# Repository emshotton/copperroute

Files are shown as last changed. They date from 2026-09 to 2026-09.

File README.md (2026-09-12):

# CoppeRoute

An open source PCB autorouter. This started as a rust port of [freerouting](https://github.com/freerouting/freerouting) that got out of hand.

[Live Web Demo](https://copperroute.net)

## Build

Requires a Rust toolchain (see `rust-toolchain.toml`).

```sh
cargo build --release
```

The binary is `target/release/copperroute`.

## Usage

```sh
copperroute route board.dsn -o board.ses
copperroute drc board.dsn --ses board.ses -o report.json
copperroute info board.dsn
copperroute mcp
```

Run `copperroute --help` or `copperroute <command> --help` for the full
option list.

Corridor guidance is enabled by default: related signals are encouraged to share
routing corridors. To disable it for a run:

```sh
COPPERROUTE_CORRIDOR_GUIDANCE=0 copperroute route board.dsn -o board.ses
```

### With a KiCad project

`copperroute` reads a `.kicad_pcb` board directly:

```sh
copperroute route board.kicad_pcb -o board.ses
copperroute drc board.kicad_pcb --ses board.ses -o report.json
```

KiCad 6 and later keep net classes in the `.kicad_pro` project file, not the
board, so a `.kicad_pcb` from those versions carries no clearance or via
sizing of its own. Pass `--kicad-project` alongside it — the flag applies to
a `.kicad_pcb` input the same way it does to a `.dsn` — unless the board is
old enough to embed its own `(net_class ...)` rules:

```sh
copperroute route board.kicad_pcb --kicad-project board.kicad_pro -o board.ses
copperroute drc board.kicad_pcb --kicad-project board.kicad_pro --ses board.ses -o report.json
```

The same flag routes a Specctra export using the project's design rules
instead of the defaults baked into the DSN:

```sh
copperroute route board.dsn --kicad-project board.kicad_pro -o board.ses
copperroute drc board.dsn --kicad-project board.kicad_pro --ses board.ses -o report.json
```

Import `board.ses` back into KiCad with **File → Import → Specctra
Session**. The DRC report uses KiCad's own report schema, so it can be
compared directly with the output of `kicad-cli pcb drc`.

## Layout

The workspace is split into crates, each with its own README:

- `copper-geometry` — exact-arithmetic planar geometry
- `copper-board` — the board model, design rules and spatial indexes
- `copper-dsn` — `.dsn`, `.ses`, `.rules` and KiCad board JSON readers and writers, and a `.kicad_pcb` reader
- `copper-settings` — router configuration from files, environment and CLI
- `copper-router` — fanout, maze routing and the optimizer
- `copper-drc` — the design-rule checker and KiCad DRC report writer
- `copper-core` — loading, saving, the routing job and result manifest
- `copperroute` — the command-line program

## License

GPL-3.0-only. See [LICENSE](LICENSE).

This project is a derivative work of
[freerouting](https://github.com/freerouting/freerouting), which is
distributed under the GNU General Public License version 3. Parts of the
design-rule checker in `copper-drc` are ported from
[KiCad](https://gitlab.com/kicad/code/kicad), which is distributed under
the GNU General Public License version 3 or later. Both are compatible with
distributing the combined work under GPL version 3.

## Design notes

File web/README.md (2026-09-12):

# CopperRoute homepage

A static webpage that accepts a `.kicad_pcb` by dropping it onto the routing
preview window or using the file picker,
runs the existing Rust autorouter in a WebAssembly module worker, displays an
SVG copper preview, and downloads the routed PCB and SVG. No board data is
uploaded. **Route board** removes the existing top-level segments, track arcs and
vias of the selected nets (including locked items) and routes those from scratch.
The initial preview shows the original board; clicking Route shows the unrouted
copy while WASM runs, then updates live with routed copper. The pass number,
remaining connections, and routes completed in the pass update alongside it.
Footprint pads and through holes remain. Original files
on disk are not modified.

The preview appears immediately on file selection, independently of
routing compatibility. Drop `.kicad_pcb` and `.kicad_pro` together to import project
rules, or use the separate optional project picker. Includes a tiny example board
and an immediate Cancel button.

**Board rules** and **Nets to route** are collapsed panels sharing one style.
Each summary names its current state — the project file, embedded classes or
manual rules, and the number of selected nets — so both stay readable while
closed. Board rules holds the zone refill and via-in-pad options.

The example board loads and renders straight away, under a hint inviting a
board to be dropped on the preview. The hint clears on the first click, key
press, scroll or drag, leaving the board visible.

A terminal-styled block below the results carries the commands for cloning and
building the command-line router from GitHub, which the header also links to,
and for serving the routing tools over MCP.
Import notes are no longer surfaced; the status line keeps the pass count and
the review reminder, and DRC findings stay in their own disclosure.

The preview header carries the routing result — remaining connections and the
router DRC count, split into violations that predate the route and new ones.
The line below the preview keeps the pass count and the review reminder.

## Run

From the repository root:

```sh
rustup target add wasm32-unknown-unknown
cargo install wasm-bindgen-cli --version 0.2.127 --locked
cd web
npm ci
npm run build
npm start
```

Open http://127.0.0.1:8080. Easyduino Uno loads automatically with its project rules.
Choose Uno or Nano in the example selector, then click **Route board**.
**Try a small example** loads a minimal two-net board.
Rust and the matching wasm-bindgen CLI are build dependencies; Node is used for
scripts/tests, and Python 3 serves the static files. The generated `pkg/` is
ignored by Git. Serve the `web/` directory over HTTP(S), not `file://`.
Any static host serving `.wasm` as `application/wasm` can host the page. There
are no runtime CDN dependencies, backend services, or cross-origin isolation
requirements; the logo face is the vendored
`fonts/bakbak-one-latin.woff2` (9.5 KiB), served from the same origin under
the SIL Open Font License in `fonts/OFL.txt`, so no request leaves the page. The current release WASM is
approximately 2.9 MiB uncompressed.

## Net selection

**Nets to route** lists every net on the board with its net class. All nets
start selected, so the default route is unchanged. Deselecting a net excludes
it from routing and keeps its existing tracks and vias, which the router treats
as fixed obstacles; only the selected nets are ripped up and routed from
scratch. Unselected nets stay unrouted and are counted in the remaining
connections. **Select all** and **Select none** apply to the nets currently
matching the filter box. Routing is blocked while no net is selected.

The list comes from the board itself, so it appears once the preview loads and
resets with each new board. Selection is passed to the router by net name.
A board the router cannot import still previews, without the net list, and DSN
boards have no net list.

Rerouting a subset of an already routed board is harder than routing the whole
board: the copper of every unselected net is fixed, so the router must fit the
selected nets around it. Expect more remaining connections than a full route of
the same board.

## Via-in-pad rules

**Allow vias in SMD pads** is off by default for KiCad boards and resets when
another board is selected. It supplies the Rust KiCad JSON bridge's explicit
`viaInPadAllowed` permission (absent means false), independently of the project's
width and clearance rules. This is a router option, not an imported KiCad project
property.

Rust stores this permission in each `ViaInfo.attach_smd_allowed`, for the default
via and every net-class via template. Maze search, fanout and forced via insertion
use those rules. Disallowing attachment keeps the new via's copper clear of SMD
pad copper, including off-centre overlaps. `smd_via_relaxation` may reduce via costs
on pure-SMD nets; it cannot override attachment permission for KiCad JSON inputs.

DSN routing continues to use its embedded `(control (via_at_smd on/off))` and
per-via attachment rules, including the legacy pure-SMD search relaxation. The
browser checkbox is disabled for DSN. See the [native permission guide](../docs/fixes/via-in-pad-permissions.md)
for JSON class overrides and format-conversion behavior. Native KiCad imports
preserve existing vias in place; this setting governs newly routed vias.
The browser removes existing vias before rerouting. Disallowing via-in-pad may
require more routing space and can leave connections unrouted.

## Scope and limits

This proves browser routing, rather than complete native KiCad format support.
For KiCad boards, the browser bridge imports KiCad **JSON**, so `kicad.js` translates a supported
subset of the native S-expression format into that existing representation.

- Standard circular, rectangular, oval, and rounded rectangular pads; rotated
  footprints and pads on either side; straight tracks; through vias; up to 32
  copper layers; one outer board outline with internal cutouts, made from lines, arcs, circles, a rectangle,
  or a polygon, including Edge.Cuts inside footprints. Curves are approximated
  within 0.005 mm; legacy center/angle arcs and modern three-point arcs are supported.
  The original outline remains intact in downloads. Cutouts become fixed obstacles
  on every copper layer, with the imported copper-edge clearance.
- Copper layers retain stack order and canonical names independently of KiCad
  numeric IDs; the original layer table (including IDs and aliases) is preserved
  in the PCB download. Signal/mixed copper layers allow routing; power layers
  become non-routing planes in Rust. Unsupported layer types are rejected.
  Export rejects changed layer mappings and traces on non-routing layers.
  The preview legend lists every copper layer, including aliases and plane status.
- Rounded pads preserve corner radii for physical hole-clearance DRC, while routing
  and other DRC checks still use enclosing rectangles. The core
  approximates oval pads with its existing polygon representation.
- Oval slots, plated or not, retain their original geometry in downloads. Routing
  uses the copper pad shape and the smaller drill dimension; slot-specific DRC needs
  KiCad. Connector pads are supported.
- Both legacy numeric net references and KiCad 10 named net references are
  supported. Paste-only pad apertures are excluded from copper routing.
- Copper zones are accepted when **Refill copper zones in KiCad after routing**
  is selected (the visible default). Routing operates on tracks and pads without
  relying on pours. The download preserves zone definitions and removes cached
  `filled_polygon`/`fill_segments` data. Open it in KiCad, press **B** to refill,
  then run DRC. This is not an in-browser zone fill implementation. Keepout areas that
  explicitly allow both tracks and vias are preserved, including pour-only
  keepouts. Areas restricting tracks or vias, and netless copper zones, remain
  rejected. Deselecting the option rejects copper zones but still allows these
  non-routing keepout areas.
- Offset pad copper is translated in its local coordinate system while the hole
  stays at the pad anchor. Custom pad copper is the convex hull of every primitive
  (polygon, line, rectangle, arc and circle) inflated by its stroke, together with
  the circular or rectangular anchor, approximated within 0.005 mm. A pad that is
  not a single convex filled outline warns that its hull can overstate its copper.
  Trapezoid pads are imported as their four corners.
- Copper text is reserved using conservative rectangles. Footprint copper
  rectangles include their stroke and reserve their entire interior. Original
  graphics remain in the download; the reserved text bounds can reduce routability.
- Keepouts restricting tracks or vias, separate outer boards, other footprint
  copper graphics, and net ties are explicitly rejected. Existing routing is
  discarded before import, including locked tracks, arcs and all via types. This excludes many production boards.
- An optional `.kicad_pro` supplies net-class widths, clearances, via diameters,
  drills and class assignments to the existing KiCad JSON loader. The WASM entry
  point also calls the same `fr_drc::apply_kicad_project` API as the native CLI
  for supported board minima, DRC constraints and severities. Project rules take
  precedence over the disabled manual fields. Simple `*`/`?` net-name patterns
  and explicit assignments are supported; composite classes and richer patterns
  are rejected. `.kicad_dru` custom rules and local pad overrides are not applied.
  Legacy embedded `net_class` records supply widths, clearances, via dimensions
  and exact net assignments without a project. An accompanying project takes
  precedence. Manual rules apply when neither source is available. Project files are
  limited to 5 MiB. Browsers cannot read adjacent project files automatically.
- Original non-routing source sections are preserved byte for byte, including
  footprints and board metadata, except cached zone fills when rebuilding zones and the modification notice
  added to bundled example downloads. Top-level tracks and vias are replaced with
  the pipeline output, so their individual UUIDs/properties are not retained.
- KiCad pad and via drills, including net-class via templates, are stored explicitly
  in Rust padstacks in board units. DRC and hole-clearance search geometry use these
  dimensions, and the writer exports them directly. Non-plated holes are marked
  separately and are exempt from annular-ring checks. Pads with different drill
  diameters or plating do not share a padstack. Slotted-hole drill geometry remains
  approximate; legacy inputs without drill metadata retain their fallback behavior.
- `preview.js` displays native outlines, pads, tracks, vias, filled copper zones,
  and reference labels, including modern arc geometry. Previewing does not need
  WASM or a successful routing import, and routing errors retain the preview.
  Some unsupported custom pad shapes are shown by their bounding dimensions.
  It does not render complete silkscreen, component bodies or airwires.
- Routing is single threaded; optimization is disabled. A time limit is
  cooperative within the router, and final DRC/export can take additional time.
  Cancel terminates the worker immediately and discards that attempt. A new
  attempt starts with a fresh WASM instance, including after a panic.
- The UI reports incomplete connections, timeouts, and the Rust DRC count.
  A completed run can still have unrouted connections or violations. Always
  inspect in KiCad and run its DRC with the original project rules.
- Files are capped at 20 MiB. Large accepted boards may still exceed the browser's
  practical memory or runtime limits. Tested in Chromium; other browsers have
  not yet been verified.

## Implementation

`app.js` manages file selection, worker lifecycle, result state, and Blob downloads.
`worker.js` renders native geometry on selection. On Route it imports the board,
applies project classes, loads WASM, routes, then sends the final preview and PCB. All parsing and routing happens in the worker.
`crates/copper-web` resolves normal headless settings, loads the existing JSON format,
invokes `fr_core::RoutingPipeline`, and returns the JSON output plus route metrics.
Routing `std::time::Instant` uses are replaced with `web_time`, a native alias on
native targets and a browser clock on WASM. `ProgressSink::on_board_update` lends
observers the board at existing autorouter checkpoints (250 ms throttle, plus
pass boundaries); its default forwards the unchanged event to existing sinks.
`RoutingPipeline::run_with_progress` allows the browser to use a local callback
without the native sink's `Send` requirement. Snapshots are serialized and rendered
in the worker, then posted while synchronous WASM routing continues. This shows
committed board geometry, not individual maze-search steps. Long searches can
leave a frame unchanged until the next checkpoint. Cancel/replacement terminates
the worker and ignores stale messages. Final output remains the pipeline result.

Relevant format/runtime references:
[KiCad board format](https://dev-docs.kicad.org/en/file-formats/sexpr-pcb/),
[KiCad common S-expressions](https://dev-docs.kicad.org/en/file-formats/sexpr-intro/),
[web-time](https://docs.rs/web-time/1.1.0/web_time/).

Next steps for broader board support: a full native-format importer with exact curved
geometry, in-browser copper zone fills/keepouts and custom rules; geometry oracle tests against
KiCad for real corpus boards; fanout/maze-search visualization; and richer layer/airwire viewing.

## Validation

```sh
# From web/ (build first):
npm test
npx playwright install chromium
npx playwright test

# From repository root:
cargo check --workspace
cargo test -p fr-core --lib
cargo test -p fr-board --lib time_limit
cargo test -p fr-router --lib pipeline::stop
```

Browser tests cover actual drag/drop → WASM route → SVG → PCB/SVG downloads,
read-back of downloaded routing, no uploads/external requests, mobile layout,
invalid input, cancellation and retry. Adapter tests cover placement, source
preservation, drill preservation, rejected geometry, and SVG metadata isolation.

The included board routed both connections with zero Rust DRC violations.
KiCad 10.0.3 independently loaded the browser download and reported zero
unconnected items and no routing errors. Its two warnings were missing local
`Browser` footprint-library definitions for the example's embedded footprints.

Lantern import regression (2026-09-06, before the route-from-scratch change): the user-supplied KiCad 10 PCB and project load
53 nets, 210 copper pads, 413 existing segments, and 128 vias. A one-pass browser
run produced a downloadable result with 10 track-only incomplete connections and
43 Rust DRC findings. KiCad 10.0.3 loaded that download with the original project,
refilled its two ground pours, and reported **zero unconnected items**; remaining
findings were two footprint-library warnings and one dangling-via warning.
The private board is not copied into this repository.

Live preview validation: the v2 Lantern PCB/project streamed six frames during
one routing pass, with remaining connections decreasing from 63 to 11. Browser
tests verify intermediate copper frames arrive before completion and dropping a
replacement onto an existing SVG cancels the old worker. The preview also opens
the file picker with click, Enter, or Space.

## Bundled examples

The picker offers six boards spanning 9 to 225 nets: Hubble jacks, CATs-Eurosynth
Slimline VCA, Easyduino Uno and Nano, Adafruit Feather ICE40, and real-time
chess. Each is fetched only when selected, so opening the page costs one board.
Every board keeps its upstream `LICENSE.txt` and notice beside it, and the
sidebar credit, the routed download's title block and the SVG description all
name that board's own project, author, commit and licence. Boards other than
the Easyduino pair ship without a KiCad project file, so the manual rules apply
to them.

## Bundled Easyduino examples

Uno and Nano are Arduino-compatible designs by Hanqaqa and contributors, from
[Easyduino](https://github.com/Hanqaqa/Easyduino/tree/53b14b66d64f25c55f88971c1c1b51656126bd30).
The unmodified PCB and project pairs are in `examples/easyduino/`, with the
upstream CERN-OHL-P-2.0 license, README, and a provenance notice. These are not
endorsed by Arduino. Keep these notices and the license when redistributing the
examples. Routed example PCBs include a dated modification notice in their title
block; SVG downloads include attribution in a description element.

Both are four-layer boards with one Default net class (no distinct per-net classes):

| Example | Track width | Clearance | Via diameter / drill |
| --- | --- | --- | --- |
| Uno | 0.20 mm | 0.15 mm | 0.50 / 0.30 mm |
| Nano | 0.25 mm | 0.128 mm | 0.50 / 0.30 mm |

The corresponding project is loaded automatically when selecting an example.
A user file selection takes precedence over pending example downloads.

Short one-pass browser runs produced PCB and SVG downloads for both examples.
After refilling zones, KiCad 10 loaded the results and reported 13 unconnected
items for Uno and 19 for Nano, plus 9 and 23 other findings respectively. These
are useful realistic routing demonstrations, not finished production layouts.

Layer regression: the bundled Uno declares F.Cu, In1.Cu, In2.Cu and B.Cu as
signal layers. The Uno example restricts the router to F.Cu and B.Cu via Rust
layer activation settings, while preserving all four layers and their original
types in downloads. Nano and uploaded boards retain their normal routing-layer
behavior. Inner copper now has distinct colors and legend
labels. Browser tests verify that power-plane inner layers receive no traces.

Uno DRC investigation before the drill fix (five passes, outer copper only): all 34 Rust findings were
estimated `drill_out_of_range` results: 32 vias estimated as 0.225 mm and two USB
NPTHs estimated as 0.2925 mm against a 0.30 mm minimum. Actual exported drills
were 0.30 mm and 0.65 mm respectively. The core padstack fallback estimates drill
diameter as 45% of copper diameter when its naming convention does not encode a
drill. At that point, the browser restored via drills only during export, after Rust DRC.
KiCad independently found no undersized holes, but did find one genuine
hole-to-copper clearance error (0.1753 mm versus 0.25 mm), one dangling-via
warning, and three unconnected items. The Rust count is not a manufacturing
sign-off. WASM now includes per-finding `drcDetails` and pre-route
`initialDrcDetails`, with estimate flags and dimensions in mm, for diagnosis.

After the explicit-drill fix, the same Uno run has zero drill-size violations.
Rust reports nine hole-clearance findings: eight already present in its imported
USB footprint approximation and one involving a routed track. KiCad still needs
to validate the complete native geometry, particularly slots and rounded pads.
Regression tests check the unmodified WASM result's via drills, so export-time
repair cannot hide a loss of metadata inside Rust.

## Specctra DSN import

Drop a `.dsn` into the preview window or select it with **Choose a board**.
The native Rust DSN importer supplies embedded net classes, widths, clearances,
via definitions, planes, keepouts, and layer settings to the router. KiCad project
and manual rule controls are disabled for DSN. The preview displays physical board
geometry and updates at routing checkpoints. Loading its preview requires WASM.

**Route board** removes existing traces and vias, including protected routing,
before routing from scratch. Downloads include a routed DSN, an SES session for
import into the original PCB editor, and an SVG. The DSN is reserialized by the
native writer; it is not a byte-preserving copy of the source. Artwork and
source-editor metadata are outside this interchange format. Run the source
editor's DRC after importing the SES. Partially imported DSNs can be previewed
but are rejected for routing.

USB hole-clearance follow-up: see [the investigation](docs/usb-hole-clearance-investigation.md).
The bridge now preserves rounded-pad corner radii and hole-to-copper DRC uses
physical circle, segment, rectangle and rounded-rectangle distances. Routing
retains enclosing rectangles for rounded pads. Result details distinguish
findings already present before routing from new findings; the original project
minimum is not reduced to hide existing footprint violations.

To check a local PCBench download through import, preview, WASM routing and both
PCB/SVG downloads, start the web server and run:

```sh
node web/scripts/check-pcbench.mjs /path/to/PCBench-top-5-new-boards /tmp/pcbench-results
```

The check imports both raw and processed boards and routes each processed board
with its adjacent `raw.kicad_pro` when available. It uses five passes and a
60-second routing budget per board, writes downloaded files and a JSON report,
and verifies unchanged footprints, layer tables and source rules. Passing this
check means the browser produces a usable partial result; the report separately
records remaining connections and DRC findings. Refill pours and run KiCad DRC
before treating an output as complete.

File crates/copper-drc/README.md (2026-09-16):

# copper-drc

The design-rule checker. It answers four questions about a board — *which
rules are violated, which items are unconnected, how many connections
are still incomplete, and how much further the routing fragmented the copper
pours* — and writes the answer as a KiCad DRC report. Use
`copper_drc::prelude::*` to bring in every public type.

The pour question is asked differentially. `PlaneConnectivity` models a refill
on a raster, and that model is an approximation of the CAD tool's own filler,
not a match for it: it erodes without re-inflating, has no thermal reliefs, and
assumes a zone clearance the design file cannot supply. `PlaneFragmentation`
therefore compares two runs of the same model over the same pour outlines —
before and after a session — so the approximations cancel and what is left is
the routing's own effect. An absolute cluster count from this model is not a
claim about the board; a rise in one between two runs is.

The crate sits on `copper-board` (the boards it checks) and on `copper-dsn` (for
`CoordinateTransform` and the shared JSON formatter), and depends on `serde`,
`serde_json` and `thiserror` besides — and on **nothing else**, in particular
not on `copper-settings`. `copper-drc → copper-dsn → copper-board → copper-geometry` is strict
and acyclic. No `tracing`, no GUI, no static mutable state, and **no
clock**: the report's `date` is an injected string.

## API surface

Everything starts from a checker borrowing the board **mutably**:

```rust,ignore
let mut drc = DesignRulesChecker::new(&mut board);
```

`&mut Board` is deliberate. Clearance queries advance the search tree's
entry counter and lower each item's memoised smallest clearance; hiding
either behind interior mutability would hide a side effect a caller can
observe.

| What you want | Call |
|---|---|
| every DRC violation | `get_all_violations() -> Vec<DrcViolation>` |
| the unconnected/dangling list | `get_all_unconnected_items() -> Vec<UnconnectedItems>` |
| the ratsnest | `calculate_all_incompletes()`, then `get_all_airlines() -> Vec<AirLine>` |
| the counters | `max_connections()`, `get_incomplete_count()`, `get_incomplete_count_for_net(n)`, `get_length_violation_count()`, `get_length_violation(n)`, `recalculate_length_violations()` |
| one net's state | `get_net_incompletes(n) -> Option<&NetIncompletes>`, `recalculate_net_incompletes(n)`, `..._with(n, &[ItemId])` |
| the KiCad DRC report | `generate_report(&DrcCoordinates, &DrcReportOptions) -> KiCadDrcReport` |
| that report as JSON | `report_to_json(&DrcCoordinates, &DrcReportOptions) -> Result<String, DrcError>` |
| a hand-built report as JSON | `KiCadDrcReport::to_json()` |
| the clearance block of the board statistics | `BoardStatisticsClearanceViolations::from_violations(&[DrcViolation], board_unit_to_um_factor)` |
| constraints from a KiCad project file | `apply_kicad_project(&project_json, &mut board, &transform)` |
| normalising two DRC documents for comparison | `testkit::normalize_drc_json(&str)` (the `tests/testkit` helper crate) |

`generate_report` and `report_to_json` are `&mut self` for the same reason
`new` takes `&mut Board`: they call `get_all_violations` internally.

### The checks

`get_all_violations` runs `checks::run_all(board, &constraints)`, one
module per check family:

| module | kinds |
|---|---|
| `checks/copper.rs` | `Clearance`, `ShortingItems`, `TracksCrossing` — copper-to-copper on each layer |
| `checks/holes.rs` | `HoleClearance`, `HoleToHole` |
| `checks/edge.rs` | `CopperEdgeClearance` |
| `checks/geometry.rs` | `TrackWidth`, `ViaDiameter`, `AnnularWidth`, `DrillOutOfRange`, `MicroviaDrillOutOfRange` |
| `checks/single.rs` | the per-item pass the geometry checks share |

A `DrcViolation` carries its `kind`, `severity`, the one or two items
involved, the layer, a position, and `expected`/`actual` values;
`kind.kicad_type()` is the string the report writes.

### Constraints

`constraints.rs` resolves the rule set a check runs under. `resolve(board)`
takes the board's own `DrcConstraints` when a KiCad project has been applied
and otherwise derives one from the design (`from_dsn`): per-class clearances
from the clearance matrix, the minimum track width, severities, and the
search radius the copper checks use. `apply_kicad_project` reads a KiCad
`.kicad_pro` document — its board design rules (minimum clearance, track
width, hole clearances, via and microvia sizes), its rule severities and
its net classes' clearances — merges them over the design-derived set, and
stores the result in `board.rules.drc_constraints`, so a board checked
against its project gets the project's numbers rather than the design
file's.

### The two injected parameter blocks

`copper-drc` has no clock and no version constant, so everything the report
needs from outside arrives as a parameter:

```rust,ignore
pub struct DrcReportOptions {
    pub source: String,               // the input file's base name
    pub coordinate_unit: String,      // "mm"
    pub date: String,                 // already formatted
    pub freerouting_version: String,  // without the "Freerouting " prefix, which the report adds
    pub quality_score: Option<f32>,   // None omits the key
}

pub struct DrcCoordinates {
    pub transform: CoordinateTransform,
    pub board_unit: Unit,
}
```

`quality_score` is `Option<f32>` because the score is computed one crate up
(`copper_router::score::BoardStatistics::normalized_score`) as a single-precision
value, and the report widens it to `f64` on the way out; typing the input
`f64` would let a caller hand in a number the scorer cannot produce.

## Determinism

Every walk that could depend on hash order is pinned to item id:

| where | order |
|---|---|
| `unconnectedItems[].items` | ascending item id |
| the seed order of each net's connected-set walk | ascending item id |
| `itemsByNet` | `BTreeMap<i32, …>`, ascending net number |
| the representative item of a connected set | lowest-id `Pin`, else lowest-id `Trace`, else lowest-id item |

**Within** one connected set the walk is descending item id, because
`Board::connected_set` is a `BTreeSet<ItemId>` and the triangulation's
corner-insertion order is the board's item order. Getting this backwards
silently reverses the Delaunay insertion order inside every component and
changes which equal-length airline the ratsnest picks — a wrong-output bug
with no crash.

Two consequences worth knowing before reading a diff:

- **Airline counts are stable; airline endpoints are a function of seed
  order.** `max_connections`, `get_incomplete_count()`, the per-net counts
  and the whole violation list depend only on the board. Which equal-length
  edge the triangulation picks depends on insertion order, so two checkers
  seeded differently can agree on every count and differ on an endpoint.
- **`generate_report` folds dangling-trace entries into `violations`** and
  deduplicates them against each net entry's representative item, so the
  report's `violations` array is longer than `get_all_violations()` and the
  `unconnected_items` array is one entry per net with two or more connected
  sets. The counters and the report measure different quantities of the
  same board; `tests/incompletes.rs` asserts both against one board.

Every `%.4f` in a description is written with a `.` unconditionally, through
`copper_dsn::format::double::java_format_fixed`, so the report does not depend on
the process locale.

## Tests

`cargo test -p copper-drc` runs the unit tests plus the integration suites:

| suite | what it pins |
|---|---|
| `checks.rs` | `get_all_violations`: one check per kind, the dedup and ordering, the report keys and severities |
| `constraints.rs` | constraint resolution from the design and from a KiCad project |
| `unconnected.rs` | `get_all_unconnected_items`: the three phases, their order, the dedup, the representative rule |
| `net_incompletes.rs` | `NetIncompletes`: net-item order, the triangulation, length violations |
| `incompletes.rs` | `calculate_all_incompletes`, the counters, `BoardStatisticsClearanceViolations` |
| `report.rs` | `generate_report` and the four report types, as normalised text |
| `report_json.rs` | `report_to_json`: the key order, the escape and number rules |
| `kicad_oracle.rs` | the checker against KiCad's own DRC output on the committed boards |
| `corpus.rs` | the whole DRC path over every `.dsn` in the fixture corpus (`#[cfg_attr(debug_assertions, ignore)]`) |

`corpus.rs` checks one invariant per board — `generate_report` does not
panic, the JSON parses, and
`violations.len() == hole_clearance + clearance + track_dangling + via_dangling`
with the clearance half checked against an independent
`get_all_violations().len()` — and is the guard on the report layer's three
`panic`s (`item_description`, `detailed_trace_description`,
`item_position`), which replaced silent fallbacks that would have put a
plausible-looking wrong value into a report.

```sh
cargo test -p copper-drc --release --test corpus     # or: --test corpus -- --ignored
```

The committed reference reports in `tests/reference/drc-*` (eight stems
covering every violation type, both auxiliary input paths and both zero and
non-trivial quality scores) are the goldens `crates/copperroute`'s
end-to-end tests compare the `drc` command against;
`COPPERROUTE_REGOLDEN=<label> cargo test -p copperroute --test cli_e2e`
regenerates them.

### What needs the fixture corpus

`tests/corpus` supplies the `.dsn` boards. The synthetic-board tests (the
majority of `net_incompletes.rs`, `incompletes.rs`, `checks.rs` and
`report.rs`) need nothing.

## Known limitations

- **The quality score is computed one crate up.** It needs the board
  statistics' trace lengths, via counts and bend counts, so this crate takes
  it injected and `crates/copperroute/src/commands/drc.rs` computes it.
- **Clearance compensation is never exercised.**
  `is_clearance_compensation_used()` is `false` on every headless path, so
  the compensated arm of the clearance split is unreached by any test or
  fixture.
- **`schematic_parity` is `Vec<serde_json::Value>` and always empty.** If a
  later change fills it, the element type needs its own `Serialize` in
  declaration order, like the other report types.

## Conventions this crate shares with the workspace

**`#![forbid(unsafe_code)]`** sits in the crate root, as it does in every
workspace crate.

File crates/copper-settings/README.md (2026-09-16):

# copper-settings

The router-configuration layer. It answers one question — *given a DSN file,
a `.rules` file, a settings JSON, the environment, the command line and a
board, what settings does the router actually run with?* Use
`copper_settings::prelude::*` to bring in every public type.

The crate sits on `copper-dsn` (which owns the `.dsn` and `.rules` readers) and
on `copper-board` (for the one pass that reads a board), and depends on `serde`,
`serde_json` and `thiserror` besides. No `tracing`: a source that cannot be
applied becomes a `MergeReport::errors` entry. No static mutable state.

## The settings types

`RouterSettings` is the root: `enabled`, `algorithm`, `max_passes`,
`max_items`, `max_threads`, `vias_allowed`, `automatic_neckdown`,
`strict_drc`, `trace_pull_tight_accuracy`, `copper_to_edge_clearance_um`,
`hole_clearance_um`, `zone_clearance_um`, `neck_width_um`,
`job_timeout_string`, `result_json_path`, `ignore_net_classes`,
`save_intermediate_stages`,
`opt_changed_area_ms`, `smd_via_relaxation`, `failure_give_up_threshold`, a
per-layer `layers: Vec<LayerSettings>`, and the nested `fanout:
FanoutSettings`, `optimizer: OptimizerSettings` and `scoring:
ScoringSettings`. `DesignRulesCheckerSettings` and `DebugSettings` live in
`drc_settings.rs`; `BoardUpdateStrategy` and `ItemSelectionStrategy` in
`optimizer_settings.rs`.

**Every field is `Option<T>`, and that is the merge protocol.** `None` means
"this source has no opinion", not "off". The null-coalescing accessors
(`get_max_passes`, `get_layer_active`, `get_bend_cost`, …) apply the defaults
only at the point of use, so a partial source can be merged over a complete
one without erasing anything.

`ExpansionCostFactor { horizontal, vertical }` is the per-layer trace cost
pair the router reads; `RouterSettings::get_trace_costs` builds one per
layer from the layer settings.

## Sources and the merge

Each source implements `SettingsSource` (`get_settings`, `get_source_name`,
`get_priority`, `kind`). `SettingsMerger` sorts its sources by priority,
clones the first non-empty one and applies the rest over it with
`apply_new_values_from`, then validates. The priorities are constants in
`merger::priority`:

| priority | source | where it comes from |
|---|---|---|
| 0 | `DefaultSettings` | built-in defaults, sized by `HostEnvironment` |
| 10 | `JsonFileSettings` | a `copperroute.json` named on the command line (`--settings <file>`) |
| 20 | `DsnFileSettings` | the design's own `(autoroute_settings …)` block |
| 30 | `SesFileSettings` | a session file (contributes nothing today) |
| 40 | `RulesFileSettings` | a `.rules` file |
| 55 | `EnvironmentVariablesSource` | `COPPERROUTE__ROUTER__<A>__<B>=v` |
| 60 | `CliSettings` | `--router.<a>.<b>=v`, or `--set router.<a>.<b>=v` on the native command line |
| 65 | GUI | reserved, unused |
| 70 | `ApiSettings` | the sparse tier an MCP `route_board` call's `settings` argument fills |

`set_field_value(&mut RouterSettings, path, value)` (`field_path.rs`) is the
string-path writer behind the environment and command-line sources; it
knows every field's type (`FieldSpec`/`FieldKind`) and refuses unknown paths
and unparsable values with a `MergeError`.

`copy_fields.rs` is the field-by-field merge (`CopyFields`, implemented per
struct in declaration order) with two rules that decide routing behaviour:
primitive and `String` arrays copy only into an empty target (first writer
wins), and object arrays merge element-wise and are never shrunk. That is
why a `.rules` file's per-layer trace costs do not reach the router through
the merge but its per-layer preferred directions do. `MergeMode::FillAbsent`
is the inverse mode, used once (below).

## `resolve_headless`

The headless run does not perform one merge; it performs two, with a
board-tuning pass between them and a `.rules` re-apply after the second,
and the `.rules` file ends up outranking the environment and the command
line for every field an `(autoroute_settings)` block can carry.
`resolve_headless` (`resolve.rs`) is that sequence as one linear pass:

```text
s = DefaultSettings
s.apply(json_file)                                   // 10
s.apply(dsn)                                         // 20
s.apply(parse(cli_rules))                            // 40   (a rules file named on the command line)
s.apply(env)                                         // 55
s.apply(cli)                                         // 60
s.validate()
s.set_layer_count(board) if it disagrees
s.apply_board_specific_optimizations(board)
s.board_specific_trace_costs_applied = None
s.fill_absent_from(parse(scheduler_rules))           // the second merge's own contribution
s.validate()
s.apply(parse_against(scheduler_rules, board))       // the rules file, re-read against the board's layers
s.apply_board_specific_optimizations(board)
```

Its inputs are `SettingsInputs`:

```rust,ignore
pub struct SettingsInputs<'a> {
    pub json_file:       Option<&'a RouterSettings>,
    pub dsn:             Option<&'a RouterSettings>,
    pub cli_rules:       Option<&'a [u8]>,
    pub scheduler_rules: Option<&'a [u8]>,
    pub env:             Option<&'a RouterSettings>,
    pub cli:             Option<&'a RouterSettings>,
}
```

The two rules slots are **bytes**, not parsed objects, because the same
file is parsed twice against two different layer structures: once with the
layers discovered from the file's own `(layer_rule …)` names, and once
against the board's. A two-layer rules file on a four-layer board puts
`B.Cu` at a different index in each, and handing one parsed object to both
steps produces the wrong settings. Feed it `std::fs::read(path)`.

`resolve_scheduler_rules_path(job_rules, cli_rules, dsn_path)` says which
`.rules` file a run picks up (an explicit one, else the one beside the
design); `_with` injects the file-exists probe for tests.

Three things to keep in view while reading `resolve.rs`:

- **`board_specific_trace_costs_applied` is cleared by hand** at the point
  where the two merges would have handed over to a fresh object, so the
  second `apply_board_specific_optimizations` re-derives the costs.
- **`validate()` is not idempotent.** `max_passes == 0` becomes `i32::MAX` on
  the first call and `9999` on the second, because the second call clamps a
  value above `9999`. The linear pass calls it exactly twice, like the two
  merges it replaces.
- **`resolve_headless` models the CLI-started run.** An MCP `route_board`
  call has a sparse priority-70 payload instead, and `crates/copperroute`
  composes that path itself.

## Defaults, clamps and the host

`DefaultSettings::new(&host)` fills every field; the headline constants are
public (`DEFAULT_VIA_COSTS = 50`, `DEFAULT_PLANE_VIA_COSTS = 5`,
`DEFAULT_START_RIPUP_COSTS = 100`, `DEFAULT_BEND_PENALTY = 10.0`,
`DEFAULT_UNROUTED_NET_PENALTY = 5e6`,
`DEFAULT_CLEARANCE_VIOLATION_PENALTY = 1e6`,
`DEFAULT_COPPER_TO_EDGE_CLEARANCE_UM = 500.0`,
`DEFAULT_HOLE_CLEARANCE_UM = 0.0`). `layers` and the two cost arrays are left
absent — their size depends on the board. `zone_clearance_um` defaults to
`router_settings::DEFAULT_ZONE_CLEARANCE_UM` (500.0): the zone clearance the
copper-pour refill model assumes, since no design file carries one.

Clamps live on the setters: `set_bend_cost` clamps to `[0.0, 9.9]`;
`set_via_costs`, `set_plane_via_costs` and `set_start_ripup_costs` floor at
1; the two trace-cost setters floor at 0.1 and set the applied flag;
`validate` clamps `max_passes` to `0..=9999` (with `0` meaning unlimited),
`max_threads` to the core count, and `trace_pull_tight_accuracy` to at
least 1.

Every machine-dependent number goes through `HostEnvironment`.
`HostEnvironment::detect()` calls `std::thread::available_parallelism()`
once — the only such call in the crate — and `HostEnvironment::with_processors(n)`
is what every test uses, so the processor count never leaks into a test
expectation.

## JSON

`RouterSettings::from_json_str` / `to_json_string_pretty` (`json.rs`) read
and write the settings document. The reader is strict JSON (`NaN` and
`Infinity` are refused) and drops the three transient fields (`max_items`,
`save_intermediate_stages`, `ignore_net_classes`). The writer emits fields
in declaration order through `copper_dsn::format::json::to_gson_string_pretty`,
the layout shared with the DRC report and the result manifest.

## The legacy short flags

`sources/cli.rs` also carries `apply_command_line_arguments`, the table for
the legacy short flags (`-mp`, `-mt`, `-oit`, `-us`, `-is`, `-hr`, `-inc`,
`-drc`). It writes a `LegacyBridge` that nothing on the routing path reads:
those flags are parsed for their effect on argument positions and
diagnostics, and the values that actually reach the router come through the
priority-60 `CliSettings` spelling. The `copperroute` binary no longer accepts
that form; nothing in the workspace calls this table any more.

## Tests

`cargo test -p copper-settings` runs the unit tests plus eleven integration
suites: `copy_fields`, `field_path`, `router_settings`, `board_optimizations`,
`sources`, `env_source`, `cli_source`, `precedence`, `json`, `struct_shape`
and `corpus`.

- **`precedence.rs`** is the load-bearing one. It runs a 64-case matrix
  (`tests/matrix/mod.rs`: 4 DSN shapes × 4 rules shapes × 2 environments × 2
  command lines) through **both** forms of the composition — the literal
  two-merge shape built out of `SettingsMerger`, and the linear
  `resolve_headless` — and asserts they agree field for field.
- **`struct_shape.rs`** pins every struct's field order, because
  `copy_fields` iterates it and `json.rs` emits it.
- **`json.rs`** replays 64 committed settings documents from
  `tests/golden/p4t1-mode1/all.txt` through the reader and writer.
- **`corpus.rs`** runs `DsnFileSettings::new` over every `.dsn` in the
  fixture corpus (~2.7 s in debug, not ignored) and asserts the source's
  layer count matches the header the reader reported. Its `.rules` sibling is
  `#[cfg_attr(debug_assertions, ignore)]`; run it with
  `cargo test -p copper-settings --release --test corpus`.

`tests/data/README.md` describes the committed inputs — the two `.rules`
matrices the precedence suite feeds in and the trimmed
`Issue029-hw48na_reduced.rules`.

### What needs the fixture corpus

`tests/corpus` supplies the DSN and `.rules` fixtures for `corpus.rs`,
`precedence.rs`, `sources.rs`, `json.rs` and `board_optimizations.rs`'s
three `*_golden_*` tests. `copy_fields`, `field_path`, `router_settings`,
`env_source`, `cli_source` and `struct_shape` are pure.

## Conventions this crate shares with the workspace

**`#![forbid(unsafe_code)]`** sits in the crate root, as it does in every
workspace crate.

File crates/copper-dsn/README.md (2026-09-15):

# copper-dsn

The file-format layer: a Specctra `.dsn` reader that builds a
`copper_board::Board`, writers for `.dsn`, `.ses` and `.rules`, a `.ses` and
`.rules` reader, and the KiCad board-JSON reader and writer. Use
`copper_dsn::prelude::*` to bring in every public type.

The crate sits directly on `copper-board` and `copper-geometry`. It builds boards
through `copper-board`'s public insert API and reads them back through
`get_traces`/`get_vias`/`get_connectable_items`/`items_in_board_order`; it
owns no board state of its own. `serde`/`serde_json` are used by the KiCad
module and the JSON formatter only. No `regex`, no `tracing`: reader
diagnostics go onto `ReadScopeParameter::warnings`.

## Entry points

| What you want | Call |
|---|---|
| read a `.dsn` into a board | `read_board(input, &DsnReadOptions) -> BoardReadResult` |
| only the header (layer count, unit, resolution, embedded router settings) | `read_metadata(input) -> BoardReadResult` |
| write a board as `.dsn` | `dsn_writer::write(&mut w, &board, &ct, …)` |
| write a routing session (`.ses`) | `ses_writer::write(&mut w, &board, &ct, …)` |
| apply a session to a board | `ses_reader::read(input, &mut board, …) -> SesImportSummary` |
| write / read a `.rules` file | `rules_writer::write`, `rules_reader::read`, `rules_reader::read_router_settings` |
| a KiCad board JSON | `kicad::read_board`, `kicad::import_session`, `kicad::write` |
| a `.kicad_pcb` file | `kicad::pcb::read_pcb(text, name, &defaults) -> Result<ImportedPcb, PcbError>` |

`BoardReadResult` is `Success { board, metadata, coordinate_transform, warnings }`,
`OutlineMissing` (the same, for a design with no outline), `Partial` (the
file ended inside an unclosed scope; the board built so far is returned with
that fact recorded), `ParseError` or `IoError`. `BoardMetadata` carries the
host CAD name and version, layer count, unit, resolution, snap angle, and the
`(autoroute_settings …)` block as a `DsnRouterSettings` when the file has one.

`CoordinateTransform` — the unit and resolution a file was read in — is
threaded explicitly: `BoardReadResult::Success` carries the one the reader
built, and every writer takes `ct: &CoordinateTransform`, because that is the
only transform that round-trips the file's coordinates unchanged.

## Layout

| Module | What it holds |
|---|---|
| `lexer/` | `DsnScanner`, a table-driven tokeniser (`tables.rs` is generated by `scripts/gen-lexer-tables.py`), and `Token { Open, Close, Kw, Str, Int, Float }` |
| `keyword.rs` | `Keyword` and `ScopeKeyword`, the token vocabulary |
| `parser/` | one module per scope family — `structure`, `library`, `part_library`, `placement`, `network`, `wiring`, `autoroute_settings`, `geometry`, `header`, `dsn_file` — plus `ReadScopeParameter`/`WriteScopeParameter`, the state threaded through a read or a write |
| `dsn_reader.rs`, `dsn_writer.rs`, `ses_reader.rs`, `ses_writer.rs`, `rules_reader.rs`, `rules_writer.rs` | the six file-level entry points |
| `kicad/` | `dto.rs` (the board-JSON document types, field names matching the wire format), `reader.rs`, `writer.rs` |
| `format/` | `IndentFileWriter`, `IdentifierType` (quoting rules for identifiers, with the DSN and SES reserved-word tables), `double` (fixed-width and shortest-round-trip number formatting), `json` (`to_gson_string_pretty`, the JSON layout shared with `copper-settings` and `copper-drc`) |
| `coordinate_transform.rs` | `CoordinateTransform` |

### Read lexemes and write literals are independent

Three things are kept separate and must not be conflated: the scanner's
lexeme → `Keyword` table, `Keyword::name()`, and the literal strings each
writer emits. A scope can be read under one spelling and written under
another (`(rect …)` is written where the keyword is named `rectangle`), so a
change to one table is not a change to the others.

### The KiCad board-JSON reader

`kicad::read_board` builds a board from a KiCad board JSON: units, layer
structure, clearance matrix, outline, net classes, nets, padstacks,
packages, components and pins, conduction areas, traces and vias. Things
worth knowing before touching it:

- **Nets are numbered in first-reference order.** Auto-registered nets get
  their numbers in the order the file first mentions them, so numbering is a
  pure function of the file.
- **A malformed board is refused at the DTO boundary.** A `null` where the
  board needs a name — a layer, a net class, a net, a component reference, a
  pad — or a `null` array element is refused by `KiCadBoardJson::validate`
  with a diagnostic naming the file, the section and the object.
- **A pad's padstack is keyed on its shapes and its drill, not on its
  generated name.** The name encodes neither the layer span nor the drill;
  `unique_padstack_name` keeps display names unique.
- **The clearance matrix it builds is asymmetric on purpose.** The reader
  writes one entry per class pair, and `ClearanceMatrix` readers ask for the
  `(a, b, layer)` triple they mean.

### Reading a `.kicad_pcb` file directly

`kicad::pcb::read_pcb` parses a `.kicad_pcb` file's S-expressions straight into a
`KiCadBoardJson`, returned as `ImportedPcb { board, warnings, embedded_net_classes }`; pass
the result's `board` to `kicad::read_board_json` to get a `copper_board::Board`.
`embedded_net_classes` is the number of `(net_class ...)` entries the file carried, so
callers can tell whether the board defines its own rules or needs a `.kicad_pro`.
`kicad::pcb::default_net_class` gives the net class values the reader falls back on when the
file has no `Default` net class.

- **Some constructs are refused outright.** Curved tracks, footprint zones, locked tracks,
  concave custom pads, zone keepouts that restrict tracks or vias, netless copper zones,
  locked/blind/micro vias, and through vias with no net all fail the read rather than being
  approximated.
- **Net ties are read.** A footprint's `net_tie_pad_groups` are resolved against its pads; the
  tie pads keep their own nets, and the copper joining them carries the group's nets.
- **Copper zones that carry a net are kept, not routed.** They come through with their fill
  cache removed and a warning attached: the reader works in tracks only, and expects KiCad to
  refill zones once the board comes back.
- **A curved board edge is approximated for routing, not discarded.** The outline is
  flattened to straight segments within 0.005 mm and a warning records it; the original
  curved outline is preserved wherever the board is written back out.

## Invariants

- **`normalize_all_traces` runs under a stop check.** Every `.dsn` read ends
  with trace normalisation, which can loop on pathological same-net ladders.
  `DsnReadOptions::normalize_time_limit` (default 60 s) bounds it; when it
  trips the reader records `"Wiring: normalization of traces failed"` as a
  warning and continues. `Duration::ZERO` is a deterministic opt-out. No
  fixture in the corpus comes near the limit, and the corpus test asserts it.
- **UTF-16 code-unit string order.** Several structures are keyed by name in
  UTF-16 code-unit order, which differs from Rust's code-point `str: Ord`
  above the BMP. Where the order is observable in the output, the writers
  use `utf16_cmp` (`parser/part_library.rs`), not the derived `Ord`.
- **Descending item iteration.** Every writer walks the board through
  `Board::get_items`/`items_in_board_order` — newest item first — and the
  output bytes depend on it.
- **The scanner buffer is sized to the input.** `DsnScanner::new` is
  infallible; there is no input-size ceiling.
- **Never edit a reference output by hand.** `tests/reference/<stem>/` is
  produced only by the generator scripts under `scripts/`.

## Tests

`cargo test -p copper-dsn` runs the unit tests plus the integration suites in
`tests/`: the lexer, the number formatters, `IdentifierType`, each scope
family (`structure_scope`, `library_scope`, `placement_scope`,
`network_scope`, `geometry_scopes`, `scopes`, `wiring`, `network`), the DSN
reader, the SES and rules round trips, the KiCad DTOs, reader, writer and
round trip, the JSON formatter (`gson_format`), and the two byte-parity
suites `parity_dsn` and `parity_ses`, which compare the writers' output
against the committed reference files in `tests/reference/` byte for byte.

The corpus test in `tests/dsn_reader.rs` reads every
`.dsn` in the fixture corpus and compares the `BoardReadResult` variant and
the complete warning list against a committed golden. It is `#[ignore]`d in
debug builds (~90 s) and runs unconditionally in release —
`cargo test -p copper-dsn --release`, or `--ignored` in debug. Its always-on
sibling checks that the golden still parses and still names every fixture.

### What needs the fixture corpus

The boards live in `tests/corpus` and the expected outputs in
`tests/reference/`; both travel with the repository. `parity_ses` re-cuts its
references under `COPPERROUTE_REGOLDEN=<label>`.

`tests/kicad_pcb_corpus.rs` runs `read_pcb` against a further set of real `.kicad_pcb`
boards that does not travel with the repository. It skips unless `COPPERROUTE_PCBENCH` names
the corpus root; run it with `COPPERROUTE_PCBENCH=<corpus root> cargo test -p copper-dsn
--test kicad_pcb_corpus -- --nocapture`.

## Conventions this crate shares with the workspace

**`#![forbid(unsafe_code)]`** sits in the crate root, as it does in every
workspace crate.

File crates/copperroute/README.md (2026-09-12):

# `copperroute` — the command-line program

```sh
copperroute route board.dsn -o board.ses
copperroute drc board.dsn --ses board.ses -o report.json
copperroute info board.dsn
copperroute mcp
```

Every subcommand builds a request for `ops` — the crate's one implementation of
load, route, check and summarise — and renders the outcome. The MCP tools are
the same operations behind a JSON-RPC front end.

## Subcommands

| command | what it does |
|---|---|
| `route <input> -o <output>` | load a design, route it, write the session. `<output>` must end in `.ses` (a Specctra session) or `.json` (a KiCad session); anything else is a usage error before the board is read |
| `drc <input> [-o <report>]` | load a design, optionally a session and rules, run the design-rule check, write the KiCad DRC report — to stdout when `-o` is omitted |
| `info <input>` | print the board summary — layers, nets and components by name, the file's metadata, and the board statistics — as JSON on stdout |
| `mcp` | serve the four tools below over newline-delimited JSON-RPC on stdin/stdout |

`<input>` is a Specctra DSN, a KiCad board JSON, or a KiCad `.kicad_pcb`
board; the format is read from the bytes, not the extension.

Global flags, accepted before or after the subcommand: `-v`/`-vv`/`--verbose`
and `--log-level <off|error|warn|info|debug|trace>` set the log level;
`--settings <file>` names a settings JSON.

Corridor guidance is enabled by default. Set `COPPERROUTE_CORRIDOR_GUIDANCE=0`
to disable it; leaving the variable unset or setting it to `1` enables guidance
and its final shove-path safety check.

`route` takes:

| flag | meaning |
|---|---|
| `--rules <file>` | a Specctra `.rules` file. Without it, a `.rules` beside the input is used when one exists |
| `--ses <file>` | a session to import before routing, so the run continues from it |
| `--kicad-project <file>` | a KiCad `.kicad_pro` whose design rules are applied before routing |
| `--max-passes <n>` | how many routing passes to run; `0` means unlimited |
| `--timeout <t>` | wall-clock budget for the whole job, as `hh:mm:ss` or seconds |
| `--result-json <file>` | write the result manifest here |
| `--set router.<section>.<field>=<value>` | override one setting; repeatable. `router.max_items=N` stops the optimizer as well as the router, where `--max-passes` stops only the router |
| `--visualize <dir>` | write one SVG frame per sampled maze step into an absent or empty directory; `--visualize-every N`, `--visualize-max-frames N`, `--visualize-width`, `--visualize-height` bound it (`docs/routing-visualizer.md`) |

`drc` takes `--ses`, `--rules`, `--kicad-project` and `-o <report>`.

## Settings

A run's settings are assembled from, lowest first: the defaults; the
`--settings` file; the design's own `(autoroute_settings …)` block; the rules
file; `--max-passes`, `--timeout` and `--set`; and, for the MCP `route_board`
tool, its `settings` argument. The rules file is read twice — once for its
own layer names, once against the loaded board — which is why `--rules` takes
a path rather than a parsed object.

`--set` names a field by its path under `router.`; `copperroute mcp`'s
`list_settings` tool prints every field with a description and the defaults
in force. The `--settings` file has the same shape:
`{"router": {"scoring": {"via_costs": 77}}}`. No settings file is read
without the flag.

## Exit codes

| code | when |
|---|---|
| **0** | a completed run; `--help`; a `drc` whose report is clean |
| **1** | any failure: an unreadable input, a board that will not load, a session that cannot be written; and a `drc` whose report carries at least one violation |
| **2** | a usage error: an unknown flag, a missing argument, an output path with the wrong extension |

`route` exits 0 on `COMPLETED` and on `TIMED_OUT` with the session written,
because a timed-out job still leaves a usable partial board.

## The MCP server

`copperroute mcp` speaks newline-delimited JSON-RPC 2.0 on stdin/stdout —
**one JSON object per line, no `Content-Length` framing**. Stdout carries the
protocol and nothing else; every log line goes to stderr. It is an
in-process server: there is no listener, no port and no credential.

| what | behaviour |
|---|---|
| `initialize` | `protocolVersion` `"2025-06-18"`; `serverInfo` `{name: "copperroute", version: <crate version>}`; `capabilities` `{"tools": {"listChanged": false}}` — the tool list is fixed at compile time |
| `ping` | answered, `{}` |
| `tools/call` result | a text block **and** `structuredContent`, so a client reads the value instead of re-parsing prose. A tool that runs and fails is an `isError: true` result; a protocol failure is a JSON-RPC `error`; a tool that **panics** answers `-32603` and the server keeps serving |
| a notification | nothing is written back |
| a malformed line | `{"jsonrpc":"2.0","id":null,"error":{…}}` (`-32700`); a blank line is skipped |
| `notifications/progress` and `notifications/cancelled` | both. A `tools/call` runs on its own thread with a `CancelToken`; `_meta.progressToken` turns on interim notifications, and an inbound `notifications/cancelled` flips the token **while** the tool runs |
| shutdown | every path **drains**: the loop stops taking new work and runs until the last tool thread has reported, so no response is truncated. **EOF does not cancel** — a client that closed stdin has no more requests, which is not a client that has stopped reading — so every in-flight `tools/call` finishes and answers, and the exit code is 0. A read failure (1) and a write failure (1) do cancel, because there the answers have nowhere to go |

### The four tools

| tool | arguments | answers |
|---|---|---|
| `route_board` | `dsn_path` \| `dsn_text`, `ses_path?`, `rules_path?`, `output_path?`, `settings?` | `ses_path` when `output_path` was given, else `ses_text` **and** `data` (Base64); plus `stats`, `incompletes`, `unrouted_report`, `drc_violation_count`, `timed_out`, and `job_id`/`size`/`crc32`/`format`/`filename`/`path`. Always a Specctra session, whatever went in |
| `check_drc` | `dsn_path` \| `dsn_text`, `ses_path?`, `rules_path?`, `kicad_project_path?` | the KiCad DRC report — the same document `copperroute drc` writes, coordinates in `mm` |
| `board_info` | `dsn_path` \| `dsn_text` | the board summary — the same document `copperroute info` writes |
| `list_settings` | `{}` | `{"schema": …, "defaults": …}` — the settings schema with a description on every field, and the defaults resolved at call time |

`route_board` is the only one that reports `notifications/progress` and the
only one whose `CancelToken` can be flipped mid-run; the other three are a
load and a walk. **A cancelled route answers a result, not an error**: a
partial board with `timed_out: false`, because only the job deadline sets
that flag. `filename` and `path` name **the input's** directory and the
session's derived name; `ses_path` is the only member that says where a file
was written.

The `settings` argument is applied above every other source and is
*sparse*: naming one field of `scoring` overrides that field and leaves the
rest alone. It is strict JSON — `NaN` and `Infinity` are refused — and a
transient field (`max_items`, `save_intermediate_stages`,
`ignore_net_classes`) is dropped. The server-wide `--settings <file>` given
to `copperroute mcp` sits below it.

## Logging

Everything goes to **stderr**, and there is no log file. The output carries
no timestamp, so it is byte-reproducible. The console default is `INFO`;
`-v` raises it to debug, `-vv` to trace, and `--log-level` sets it outright
(an unrecognised name means `INFO`).

## Layout

| module | what it holds |
|---|---|
| `cli.rs` | the clap surface |
| `lib.rs` | `run` and `ExitCode` |
| `ops/` | `SettingsOverrides` and the settings ladder (`settings.rs`); `BoardSource`, `LoadRequest`, `Loaded` and `load` (`load.rs`); `RouteRequest`, `RouteOutcome` and `route` (`route.rs`); `DrcRequest`, `DrcOutcome` and `drc` (`drc.rs`); `InfoRequest` and `info` (`info.rs`); `OpError` |
| `commands/` | the three CLI adapters: build a request, call `ops`, write files, pick the exit code |
| `mcp/` | the JSON-RPC transport (`stdio.rs`, `server.rs`, `jsonrpc.rs`) and the four tool adapters under `tools/` |
| `logging.rs` | the level ladder and the subscriber |

## Tests

`cargo test -p copperroute` runs the unit tests plus six integration
suites:

* **`ops_load.rs`, `ops_route.rs`, `ops_drc_info.rs`** pin the operations
  directly: settings precedence, rules discovery, session import, the output
  format, the job deadline, the DRC violation count and quality score.
* **`cli_e2e.rs`** runs the binary. Its scenario tests cover the refusals,
  `--set` and `--settings`, the timeouts, and the `drc` exit codes. Its
  reference tests run every stem of `tests/reference/cli-fixtures.txt` and
  compare the session bytes, the exit code and the normalised manifest
  against the committed `tests/reference/cli-<stem>/` outputs; the `ci` stems
  run by default, the `slow` ones under
  `COPPERROUTE_SLOW=1 cargo test --release`.
* **`mcp_stdio.rs`** drives the server through `initialize`, notifications,
  `ping`, `tools/list`, `tools/call`, cancellation, a panicking tool, a
  malformed line and EOF, over in-process pipes and over the spawned binary.
* **`kicad_pcb_input.rs`** runs the binary against a `.kicad_pcb` board:
  `info`'s summary, `route`'s session and its loader warnings on stderr.

The reference and corpus tests read their boards from `tests/corpus`.

```sh
cargo nextest run --workspace
cargo clippy --workspace --all-targets -- -D warnings
cargo fmt --all --check
COPPERROUTE_SLOW=1 cargo test --release            # the slow lanes

# re-cut the CLI goldens from the binary, after a change that is meant to move them
COPPERROUTE_REGOLDEN=<label> cargo test -p copperroute --test cli_e2e
```

The other reference families are re-cut the same way from their own
suites; `tests/reference/README.md` lists them.

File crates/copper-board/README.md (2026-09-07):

# copper-board

The board model: items, design rules, the component/net/padstack library,
the search trees that index items geometrically, and `Board` itself —
everything a PCB design needs *before* routing runs. Use
`copper_board::prelude::*` to bring in every public type.

The crate sits on `copper-geometry` and depends on `num-bigint` and `thiserror`
besides. It must not depend on `tracing`: invariant guards are
`debug_assert!`s, and there is no diagnostic logging.

## Layout

| Module | What it holds |
|---|---|
| `board/` | `Board` and its operations, split by subject: insertion and removal (`mod.rs`), connectivity queries (`connectivity.rs`), clearance queries (`clearance.rs`, `query.rs`), trace normalisation (`normalize.rs`, `trace_normalize.rs`), the changed-area tracker (`changed_area.rs`), the trace-entry bookkeeping shoves use (`shape_trace_entries.rs`), snapshots and the one-level undo journal (`snapshot.rs`), the two clearance overrides applied after a load (`clearance_override.rs`), and `Communication` — the coordinate unit and resolution the board was read in |
| `items/` | the `Item` enum and its nine variants, `ItemHeader`, `ItemCtx`, `PolylineTrace`, the drill items (`Pin`, `Via`), the area items, `AutorouteInfo` (the router's per-item scratch, kept as ids), `ClearanceViolation` |
| `structure/` | `LayerStructure`/`Layer`, `Components`/`Component`, `BoardOutline`, `AngleRestriction`, `FixedState`, `Unit`, `ShapeEntrySide` |
| `rules/` | `BoardRules`, `ClearanceMatrix`, `Nets`/`Net`, `NetClasses`/`NetClass`, `ViaInfos`/`ViaInfo`/`ViaRule`, `DrcConstraints`/`DrcSeverity` |
| `library/` | `BoardLibrary`, `Packages`/`Package`/`PackagePin`, `Padstacks`/`Padstack`, `LogicalParts`/`LogicalPart`/`PartPin`, `Keepout` |
| `searchtree/` | `ShapeSearchTree` (a compensated search tree of item shapes on one clearance class), `SearchTreeManager` (one tree per clearance class in use) |
| `datastructures/` | `ShapeTree` (the minimum-area tree under the search trees), `PlanarDelaunayTriangulation`, `TimeLimit`/`StopCheck` |
| `ids.rs` | the newtype ids: `ItemId`, `RoomId`, `ObstacleRoomId`, `ConnectionId`, `DrillId`, `TreeId`, `NetClassId`, `ViaInfoId`, `ViaRuleId`, `PadstackId`, and `TreeObject { Item, Room }`, the key type a search tree stores |

### `Board`

`Board` owns `items: BTreeMap<ItemId, Item>`, `components`, `rules`,
`library`, `communication`, `bounding_box`, `trees: SearchTreeManager`, the
optional `changed_area`, and the shove-failure scratch
(`shove_failing_obstacle`, `shove_failing_layer`). It is `Send + Sync +
Clone`. There is no undo/redo stack: callers that need to roll back clone
the board (`Board::clone` for a shallow snapshot, `Board::deep_copy` for one
whose memoised caches are reset). The one exception is the single undo level
the optimizer opens around each item it tries to improve
(`begin_undo_journal`, `discard_undo_journal`, `undo_from_snapshot`, over
`board::snapshot::UndoJournal`), which replays the attempt's item changes
back through the **live** search trees so the trees end up in the shape they
would have had without the attempt.

### The `Item` enum

`Item`'s nine variants are `Trace`, `Via`, `Pin`, `ObstacleArea`,
`ConductionArea`, `ViaObstacleArea`, `ComponentObstacleArea`,
`ComponentOutline` and `BoardOutline`. Every variant shares one `ItemHeader`:
id, layer set, clearance class, fixed state, net numbers, component number.
The inherent `impl Item` block in `items/mod.rs` is the common method table,
dispatching on the variant.

### `ItemCtx`

Items hold no pointer back to their board. `ItemCtx` bundles the four
immutable references an item method needs — library, rules, components,
bounding box — and is passed as a parameter; `crate::board::item_ctx!` builds
one from a `&Board`. It deliberately excludes `items` and the search trees,
so an item method holding an `ItemCtx` cannot alias `Board::items` while
`Board` iterates it.

## Invariants

- **Descending item iteration.** `Board::items` is a `BTreeMap`, which
  iterates ascending; every walk whose result depends on visiting order —
  search-tree rebuilds, writers, DRC — goes through
  `Board::items_in_board_order` (`items.values().rev()`), so items are always
  visited newest-first. This is load-bearing: `ShapeTree`'s insertion
  heuristic makes the resulting tree shape a function of insertion order, and
  the tree shape decides the order the router meets obstacles in.
- **`OnceLock`, not `Cell`/`RefCell`, for lazy memo fields** (precalculated
  areas, convex-piece caches, drill-item tile-shape caches). Accessors stay
  `&self` and the type stays `Send + Sync` without a lock, matching how the
  board is used: never mutably aliased while being read.
- **`ShapeTree::insert_tiles` returns `Vec<Option<LeafId>>`.** A shape with no
  bounding tile shape under the tree's angle restriction inserts nothing at
  that index but keeps the list the same length as the shape list. Do not
  `.flatten()` it away: callers zip it against the original shape list.
- **`Polyline::from_lines` errors propagate.** Any operation that re-runs the
  normalising `Polyline` constructor (`translate_by`, `turn_90_degree`,
  `change_placement_side`, trace normalisation, `PolylineTrace::split*`)
  threads the `Result` out rather than emptying the trace on failure. Inside
  `Board::normalize_trace` an `Err` becomes `BoardError::Normalization`.
- **Stop checks on the walks that may not terminate.** Trace splitting and
  normalisation can loop on pathological ladders of same-net traces, so
  `Board::insert_via_checked`, `insert_escape_via_checked` and
  `split_traces_checked` take a `StopCheck` (`&dyn Fn() -> bool`) and answer
  `BoardError::Stopped` when it trips. The unchecked forms pass `|| false`.
- **Clearance matrix values round up to even** on write
  (`ClearanceMatrix::set_value`), and the matrix is not required to be
  symmetric; readers ask for the `(class_a, class_b, layer)` triple they mean.

## Post-load overrides

`Board::apply_copper_to_edge_clearance_override` and
`Board::apply_hole_clearance_override` (`board/clearance_override.rs`) are
applied once after a design is loaded, by `copper_router::pipeline::prepare_board`.
The first appends a `board_edge` clearance class carrying the configured
copper-to-edge clearance (default 500 µm) and re-points the outline at it
unless the outline already carries an explicit class; the second does the same
for hole keepouts when a hole clearance is configured. The order is
load-bearing, because both append a class and `board_edge` gets the lower
index.

## Tests

`cargo test -p copper-board` runs the unit tests plus twenty integration suites,
one per subject: `areas_and_outlines`, `autoroute_info`, `board_builder`,
`board`, `clearance_matrix`, `clearance_override`, `clearance_violations`,
`component`, `conduction`, `consistency`, `drill_items`,
`expansion_room_tree`, `layer_structure`, `min_area_tree`, `polyline_trace`,
`search_tree`, `shape_trace_entries`, `snapshot`, `trace_normalize`.

`consistency.rs` is the property suite: insert/remove round trips,
`deep_copy`, 45- versus 90-degree tile shapes (compared with
`TileShape::contains_tile`, since both angle families compute the same
axis-aligned bounding box), `normalize_traces` idempotence on a fixture that
needs normalising, descending item iteration, and
`Board: Send + Sync + Clone`. `snapshot.rs` pins what `structural_hash`
covers — the whole item graph, walked in board order — and what it
deliberately leaves out (on-demand caches whose state records how often the
board has been measured rather than what it is).

Tests that read a board fixture take it from `tests/data/` or, for the larger
boards, from `tests/corpus`.

## Conventions this crate shares with the workspace

**`#![forbid(unsafe_code)]`** sits in the crate root, as it does in every
workspace crate.

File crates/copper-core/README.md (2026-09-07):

# `copper-core`

The composition layer between `copper-router` and the `copperroute` binary:
loading and saving boards, the routing job, cancellation and progress, the
result manifest, the board summary, and `RoutingPipeline::run`, which ties
routing, the final design-rule check and the unrouted report together.

If you want to **route a board from code**, this is the crate you call.
Everything below it is the router, the design-rule checker, the readers and
the settings ladder.

```rust,ignore
let mut job = RoutingJob::default();
job.set_input(&dsn_path)?;
let loaded = copper_core::load::load_board_if_needed(&mut job)?;     // parse, resolve settings, apply the overrides
let mut board = loaded.board;

let sink = SyncProgressSink::default();
let ctx = Ctx::new(&loaded.settings, &sink);                     // CancelToken::new(), RouterBudget::default()
let result = RoutingPipeline::run(&mut board, &ctx)?;

copper_core::save::save_as_specctra_session_ses(&board, &loaded.transform, &design_name, &mut out)?;
```

## What this crate is not

**It is not a new home for anything `copper-router` owns.** `copper_core::{BoardStatistics,
RoutingEvent, ProgressSink, PassRecord, TaskState, RouterStop, RouterBudget,
run_pipeline, prepare_board, build_unrouted_report, …}` are `pub use
copper_router::…`, and `RoutingPipeline::run` **wraps** `run_pipeline`. This
crate is partly a façade: a reader looking for where a routing decision is
made will find it in `copper-router`, even though the call came through here.

## Layout

| Module | What it holds |
|---|---|
| `ctx.rs` | `Ctx { settings, cancel, progress, budget }` and `RoutingResult { stats, unrouted_report, drc_violations, timed_out, stop_reason, pipeline }` |
| `pipeline.rs` | `RoutingPipeline::run(&mut Board, &Ctx) -> Result<RoutingResult, Error>` |
| `cancel.rs` | `CancelToken`, `Deadline` and `JobStopReason { Deadline, Cancelled }` |
| `progress.rs` | `SyncProgressSink`, a `ProgressSink` that can be read from another thread, and its `SyncProgressSinkView` |
| `job.rs`, `file_details.rs` | `RoutingJob`, `BoardFileDetails`, `FileFormat`, `RoutingJobState`, `RoutingStage`, `JobId`/`SessionId` (`Uuid128`) |
| `load.rs` | `load_from_specctra_dsn`, `load_from_kicad_json`, `parse_board_result`, `apply_router_settings_for_loaded_board`, `load_board_if_needed` |
| `save.rs` | `save_as_specctra_session_ses`, `calculate_crc32_for_board` |
| `manifest.rs` | `RoutingResultManifest`, the `--result-json` document |
| `summary.rs` | `BoardSummary` and `summarise`, what `copperroute info` and the `board_info` tool print |
| `stats_json.rs`, `stats_from_bytes.rs` | the board statistics as JSON, and the counters that are read from the file bytes rather than the board |
| `timespan.rs` | `parse_timespan_seconds` and the job-timeout ladder |

## `CancelToken` and `RouterStop`

A `CancelToken` is the cross-thread handle; it maps onto the router's
`RouterStop`, which is a **three**-state flag, and the mapping keeps the
distinction:

| `CancelToken` | `RouterStop` | what it means |
|---|---|---|
| `cancel()` | `ALL` | the router **and** the optimizer stop |
| `cancel_auto_router()` | `AUTO_ROUTER_ONLY` | the router stops between connections; the optimizer still runs |

`max_items` reaches the first and therefore *silently disables the
optimizer*; `max_passes` reaches the second and does not. A single boolean
collapsing the two would change behaviour without changing a test, which is
why the token exposes both. The help text for `--set` in
`crates/copperroute/src/cli.rs` says so, because the program has no
`--max-items` flag of its own — the surface for it is the generic override,
`--set router.max_items=N`.

**An uncancelled token is a no-op.** `CancelToken::default().as_router_stop()`
is indistinguishable from `RouterStop::new()`, and `apply_to` on it writes
nothing.

The router polls the token at four sites: the pass-loop heads in
`pipeline::{batch_loop, fanout, optimizer}`, and the item loop in
`pipeline::pass_runner`. The fourth exists because one pass of a large board
can take minutes in release, and a cancellation that is observed only
between passes is not a cancellation an operator can use.

## The job deadline

`Deadline` has one instant, `stop_at`: when routing must stop. The ladder
that builds it from `--timeout` / `router.job_timeout` is: parse; clamp
**from above only** at `MAX_TIMEOUT_SECONDS` (24 h); `started_at + timeout`.
There is **no lower clamp**, so a negative timeout is a deadline in the past.
`CancelToken::with_deadline` carries it into the run, and the router polls it
at the same sites it polls cancellation.

`RoutingPipeline::run` records **why** a run stopped as
`RoutingResult::stop_reason`: `Some(JobStopReason::Deadline)` when the job
deadline expired, `Some(JobStopReason::Cancelled)` when the token was
cancelled, `None` for a run that finished on its own.
`RoutingResult::timed_out` is `stop_reason == Some(Deadline)`. The CLI and the
MCP tools map that reason straight onto the job state (`TIMED_OUT`,
`CANCELLED`, `COMPLETED`), so a cooperatively stopped job reports
`TIMED_OUT` as soon as it returns its partial board.

The job deadline is not the same flag as a stage's budget. The tightener's
time limit, the fanout per-pin clock and the optimizer's own deadline are
`RouterBudget` knobs that end their stage and surface as
`PipelineResult::timed_out`; they never set the job's stop reason.
`crates/copperroute/tests/cli_e2e.rs::final_state_distinguishes_stage_limits_from_job_deadlines`
is the test that keeps the two apart.

## `Ctx` has no rng seed and no `max_threads`

Spec §10 mentions both. This crate has neither: there is no randomness on any
routing path that is not derived from the settings, and `max_threads` is
read by nothing — the only threads in the workspace are the MCP transport's
two, and they carry no routing policy. `Ctx` also holds no board and no
job; the board is `RoutingPipeline::run`'s `&mut Board` parameter, owned by
whichever caller loaded it.

## `RoutingPipeline::run` composes; it does not decide

Three additions over `run_pipeline`, and **no fourth**: the `CancelToken`
adaptation, the final board's DRC violations, and the unrouted report.
`RoutingResult::stats` **is** `PipelineResult::final_statistics`, never a
second `BoardStatistics::compute` — the statistics constructor runs the
design-rule checker, and `copper-drc`'s memoisation makes the call count
observable. `RoutingResult::unrouted_report` is the diagnostic text; the
**count** comes from `stats.connections.incomplete_count`.

## The load sequence

Loading a board is `load_from_specctra_dsn` (or `load_from_kicad_json`) →
`apply_parsed_board_result` → **`apply_router_settings_for_loaded_board`** →
`apply_immediate_post_load_processing`, with `load_board_if_needed` in front
of them. The third step has four parts that split two and two:

| step | who owns it |
|---|---|
| if the board's layer count differs from the settings', write the board's into the settings | **settings** — `apply_router_settings_for_loaded_board`, and `copper_settings::resolve_headless` |
| `apply_board_specific_optimizations(board)` | **settings** — the same two |
| the copper-to-edge clearance override | **board** — `copper_router::pipeline::prepare_board` → `Board::apply_copper_to_edge_clearance_override` |
| the hole clearance override | **board** — the same, → `apply_hole_clearance_override` |

The two settings steps have two callers and one implementation each.
`resolve_headless` runs them because it models the whole settings ladder;
`load.rs` runs them because it is the loader. They are **not** nested — the
loader has no `SettingsInputs` ladder to hand `resolve_headless`. The order
is settled at the one place the two meet, the CLI: parse the board, call
`resolve_headless` **once** against the parsed board, then run the loader's
two board passes with the resolved settings.
`tests/load.rs::the_settings_pass_is_the_same_two_steps_resolve_headless_runs`
asserts the two agree, so the duplication cannot drift.

The two board steps run **once** per load, after the design is read.

## Versions

```
SERVER_VERSION = env!("CARGO_PKG_VERSION")
```

The crate's own version is what the manifest's `app_version`, the DRC
report's `router_version` and the MCP `serverInfo` carry. The SES/DSN
`(host_cad …)`/`(host_version …)` are echoed back **from the input file** and
never carry it. `tests/testkit`'s manifest normaliser drops `app_version`, so
a committed manifest golden does not move when the crate version does.

## The result manifest (`manifest.rs`)

`RoutingResultManifest` is the `--result-json <path>` document: thirteen
keys in declaration order, written through the same
`to_gson_string_pretty` the settings and the statistics go through, with no
trailing newline. **The Rust field order is the JSON key order** — serde's
derived `Serialize` streams a struct in declaration order — so reordering the
struct changes the file.

Three things about it are worth knowing before reading the code.

**`board_statistics` is serialised through `GsonBoardStatistics`**, not
through `serde_json::Value`: `Value`'s map alphabetises keys and its `f32`
widens to `f64`, and both would change the bytes. `normalized_score:
572.4359` in the committed `p8t2` transcript is what proves the single-
precision path end to end.

**The SHA-256 is hand-written.** `sha256_hex` needs one and the workspace
adds no dependency for it; the FIPS 180-4 core is sixty lines in
`manifest.rs`, pinned against the three NIST example vectors, the empty
message and the 55/56/63/64/65-byte padding boundaries.

**`resolve_git_sha` reads the environment**, `COPPERROUTE_GIT_SHA` first and
`freerouting.git.sha` second, and trims the value with its own whitespace
set rather than `str::trim`; `whitespace_sets_are_the_measured_ones` pins
that set.

## The job model (`job.rs`, `file_details.rs`)

`RoutingJob` carries the file details of the input, output, rules and DRC
files (`BoardFileDetails`: path, name, format, derived output name), the
job's `RouterSettings` and `DesignRulesCheckerSettings`, its state and
stage, and resource usage. `FileFormat` is detected from the file bytes and
has nine values (`Dsn`, `Frb`, `Ses`, `Rules`, `Scr`, `DrcJson`,
`KicadDesignJson`, `KicadSessionJson`, `Unknown`). `RoutingJobState::Invalid`
is a terminal state — an input that is neither a design nor a KiCad board
fails the job rather than leaving it queued.

`Session` collapses to `SessionId` (a 128-bit newtype) plus
`validate_session_host`. There is no random id: `RoutingJob::new` uses
`Uuid128::NIL` and `RoutingJob::with_id` takes one from a caller that has one
(the MCP server mints them). Nothing on a decision path reads an id.

**The path helpers in `job.rs` are POSIX-only**: they hardcode `/` as the
separator and `starts_with('/')` as the definition of an absolute path, so
every derived output name goes through the same rules on every host.
Windows support is a rewrite of that module, not an unpinning of one
constant.

## Tests

`cargo test -p copper-core` runs the unit tests plus eleven integration suites:
`cancel` (the three-state mapping, the no-op property, a real cross-thread
cancel), `ctx`, `job` (154 file-detail rows from `tests/data/p8t1-job-model.txt`,
plus 36 named edge cases), `load`, `manifest`, `overrides` (the 54 stage
blocks of `tests/data/p8t3-clearance-overrides.txt`, search-tree leaf count
and order digest included), `pipeline` (the whole pipeline with a recording
sink, comparing session bytes), `register`, `stats`, `summary` and
`timespan` (the 30 rows of `tests/data/p8t0-timespans.txt`).

The suites that read a board fixture take it from `tests/corpus`.

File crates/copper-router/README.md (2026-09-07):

# copper-router

The autorouter. It routes, fans out and optimises a **whole board**:
`pipeline::run_pipeline` sequences the fanout pre-pass, the routing pass loop
and the optimizer, and everything under it — the maze search, its expansion
rooms, the shove and pull-tight families, the via optimizer — is this crate's
too. Use `copper_router::prelude::*` to bring in every public type.

The crate depends on `copper-board`, `copper-geometry`, `copper-settings`, `copper-drc` (for
the unrouted report and the score's clearance block) and `thiserror`, and on
nothing else. `copper-dsn` and `parity` are dev-dependencies, for fixtures.

## Entry points

```rust,ignore
pub fn run_pipeline(
    board: &mut Board,
    settings: &RouterSettings,
    stop: &RouterStop,
    budget: RouterBudget,
    progress: &mut dyn ProgressSink,
) -> Result<PipelineResult, RouterError>;
```

`prepare_board(&mut Board, &RouterSettings)` applies the two post-load
clearance overrides and is called once per loaded board, before
`run_pipeline`. `PipelineResult` carries the router and optimizer
`TaskState`s, the pass counts, the fanout summary, one `PassRecord` per
routing pass (`pass`, `score`, `incomplete_count`, `clearance_violations`,
`via_count`, `trace_count`), the final `BoardStatistics`, and whether any
stage's budget expired. `build_unrouted_report(&mut Board)` writes the
diagnostic text naming every incomplete connection.

Below the pipeline, `route_connection` routes one connection through an
`AutorouteEngine` — maze search, locate, delete the ripped connections,
insert — and `route_connection_full` adds the necked retry, the strict-DRC
rollback and the failure-log write around it.

## Layout

| Module | What it holds |
|---|---|
| `pipeline/run.rs` | `run_pipeline`, `PipelineResult`, `normalize_router_algorithm` |
| `pipeline/batch_loop.rs` | `AutorouteBatchLoop::run` — how many passes run, which board survives them, when to give up; `BatchLoopResult`, `BatchLoopExit`, the stagnation windows |
| `pipeline/pass_runner.rs`, `batch_autorouter.rs` | one routing pass: the work list (`BatchAutorouter::autoroute_items`, sorted ascending by airline length), the per-item loop, progress events |
| `pipeline/fanout.rs` | `BatchFanout::fanout_board` and `fanout_pass`, the SMD-pin escape pre-pass, with `FanoutComponent`/`FanoutPin` ordering and the `FanoutRunSummary` |
| `pipeline/optimizer.rs` | `BatchOptimizer::run_batch_loop`, `opt_route_pass`, `opt_route_item` — re-route one item at a time and keep the result only if the score improves, rolling back through `copper-board`'s undo journal otherwise |
| `pipeline/board_history.rs` | `BoardHistory`, the pass loop's best-board memory (up to 30 clones, ranked by score) |
| `pipeline/stop.rs` | `RouterStop` (the three-state stop flag), `RouterBudget` (the wall-clock knobs), `PassRecord`, `ProgressThrottler`, `DeterministicWorkBudget` |
| `pipeline/airline.rs`, `counters.rs`, `failure_log.rs`, `item_route_result.rs`, `unrouted_report.rs`, `board_prep.rs` | airline distance, `RouterCounters`, `RoutingFailureLog`, `ItemRouteResult`, the unrouted report, `prepare_board` |
| `autoroute/maze/` | `AutorouteEngine` (the room lifecycle), `MazeSearchEngine` (the search frame, `expand.rs` its body), `MazeExpansionEngine` (drill and layer expansion), `MazeRipupResolver` (the ripup decision and cost), `MazeTraceShover` (the check-only shove probe), `AutorouteControl`, `DestinationDistance`, `MazeListElement`, `MazeQueue` |
| `autoroute/expansion/` | the expansion rooms (`FreeSpaceExpansionRoom`, `IncompleteFreeSpaceExpansionRoom`, `CompleteFreeSpaceExpansionRoom`, `ObstacleExpansionRoom`), doors (`ExpansionDoor`, `TargetItemExpansionDoor`), the three neighbour sorters (any-angle, 45°, orthogonal), and `ExpansionRoomStore`, the arenas they live in |
| `autoroute/drill/` | `DrillPage`, `DrillPageArray`, `ExpansionDrill` — the pages that manufacture the search's layer changes |
| `autoroute/path/` | `FoundConnectionLocator` (three angle regimes) turns a `MazeResult` into corner lists; `FoundConnectionInserter` inserts them; `Connection` |
| `autoroute/tree_ext.rs` | `AutorouteSearchTreeExt` — `complete_shape` and `divide_large_room`, the two search-tree operations only the router needs |
| `board_ext/` | `RoutingBoardExt`, the extension trait over `copper_board::Board` for everything that needs an engine or a shove: `init_autoroute`/`finish_autoroute`, `insert_forced_trace_polyline`/`_segment`, `opt_changed_area`, `remove_items_and_pull_tight`, `fanout`; and the classes it drives — `TraceShover`, `DrillItemMover`, `ForcedPadRouter`, `ForcedViaInserter`, `ViaOptimizer`, and the pull-tight family in `tightener/` (base, 90°, 45°, any-angle) |
| `score/` | `BoardStatistics` and its blocks, `normalized_score`, the JSON DTOs |
| `visualization.rs` | opt-in SVG capture of the maze search: `RoutingVisualizationOptions`, `start_routing_visualization`, the `RoutingVisualizationGuard` whose `finish()` returns a `RoutingVisualizationSummary`. When no recorder is active the capture hooks the search calls cost one relaxed atomic load; `docs/routing-visualizer.md` describes the frames and the viewer |
| `arena.rs` | `Arena<T>` and its index newtypes |
| `error.rs` | `RouterError` |

## The stop machine and the budget

`RouterStop` is a **three**-state flag, not a boolean, and the distinction
is load-bearing:

| write | state | effect |
|---|---|---|
| `request_stop()` | `ALL` | the router **and** the optimizer stop |
| `request_stop_auto_router()` | `NONE -> AUTO_ROUTER_ONLY` | the router stops between connections; **the optimizer still runs** |

`is_stop_requested()` is `== ALL` and gates the optimizer stage;
`is_stop_auto_router_requested()` is `!= NONE` and is what the pass loop and
the item loop read. Every ordinary exit from the pass loop — the pass cap,
"cannot improve", both stagnation windows — raises `AUTO_ROUTER_ONLY`, so
the optimizer runs after a normal routing run and is skipped only after a
full cancel. Nothing resets the flag between stages; `run_pipeline` hands
both stages the same `RouterStop`.

`RouterBudget` holds the wall-clock knobs: `opt_changed_area_ms` (the
tightener's time limit, default 1000), `fanout_ms_per_pin`,
`board_update_throttle_ms` and `progress_throttle_ms`.
`RouterBudget::disabled()` turns every one of them off, which is what every
reproducibility test passes — a run with a live budget is a function of
machine speed. `RouterStop::poll_deadline` has exactly one production call
site, the job-level check at the head of the pass loop; the per-stage clocks
(fanout, optimizer) write only their own `is_timed_out` and never the stop
flag.

## House rules

* **Single-threaded.** No `rayon`, no `std::thread`. `Board` stays
  `Send + Sync`, but nothing here spawns, and `max_threads` is read by
  nothing. A threaded maze would be non-deterministic and would dissolve
  every reproducibility test in the tree.
* **No new workspace dependencies.** Not `rand` (see `SplitMix64` in
  `copper-geometry`), not `slotmap` (see `Arena` below), not `rayon`.
* **Deterministic containers.** The maze queue is a sorted set (`BTreeSet`),
  never a `BinaryHeap`: the search pops the least element and re-inserts
  mutated elements. Every sorted container is a `BTreeSet`, which is sound
  because every comparator is a total order: float keys compare with
  `total_cmp`, giving `NaN` a fixed position rather than letting it sort
  arbitrarily. That covers the neighbour sorters' `SortedRoomNeighbour`,
  `MazeListElement`, `BatchFanout`'s pin order and the queue — each orders and
  dedups identically on every run. `MazeQueue::push` is guarded: an element
  outside the fanout escape window is refused, and the boolean is discarded at
  the one site that discards it, so `init` can succeed with an empty queue.
* **No GUI, no logging, no observers, no clock, and no static mutable state,
  with one recorded exception:** `copper_geometry::Line`'s identity token, which
  `Board::change_trace` reads through `Line::is_same_object` to decide how
  many search-tree leaves to reuse. The contract: a new token wherever a new
  `Line` is built, `Copy` — the same token — wherever the same line is passed
  on. Nothing reads the token's *value*, so no output, ordering, hash or
  serialised form can observe it.
* **`#![forbid(unsafe_code)]`**, as in every workspace crate.

## Cancellation: six sites, and why a seventh is a bug

`AutorouteEngine::is_stop_requested` — the per-connection time limit or the
caller's stop flag — is consulted at exactly six places: four inside
`MazeSearchEngine::init` (the destination-set walk and three seeding loops),
the head of the pop loop before the queue is touched, and
`DrillPage::get_drills`' convex split. Each has a test. Adding a seventh
makes a run stop earlier than the loop shape implies, which changes the
board: the divergence is not "we stopped sooner", it is "we routed something
else". Two consequences:

* **The inserter is handed `&|| false`.** Nothing below the maze search
  checks cancellation; threading the caller's check into
  `FoundConnectionInserter` would abort inserts that should complete, after
  the ripped items have already been removed — a worse board than either
  outcome.
* **`Board::split_traces_checked` consults the check once**, inside the entry
  walk that may not terminate, not once per picked trace.

The per-connection wall clock belongs to `route_connection`, which builds a
`TimeLimit` from the settings; `AutorouteBatchLoop` owns everything outside
that.

## The recovery boundaries

Panics are the error channel for geometry that has no meaningful degraded
value, and the router catches them at exactly these boundaries:

| # | site | mechanism | what it answers |
|---|---|---|---|
| 1 | `AutorouteEngine::complete_expansion_room` | `Result`, and **`Err` means an empty collection** — every caller uses `unwrap_or_default()`, never `?` | no rooms |
| 2 | maze construction in `autoroute_connection` | `catch_unwind` | `FAILED` |
| 3 | `find_connection` | `catch_unwind`, nested inside 2 because the search borrows the engine for its whole life | `FAILED` |
| 4 | the locator | `catch_unwind` | `FAILED` |
| 5 | the whole of `route_connection` | `catch_unwind` | a bare `FAILED` |
| 6 | `insert_forced_trace_polyline`'s normalise and split | the `Result` channel: the `Err` is dropped and the trace stays as it was | a silent skip |
| 7 | `AutoroutePassRunner::run_single_thread` | `catch_unwind` around the whole pass body, degrading to `Ok(false)` — **not** per item: a failure inside the item loop ends the pass rather than skipping one item | the pass ends |
| 8 | `AutorouteBatchLoop::run` when no layer is both active and a signal layer | the **only one that propagates**: fires `TaskState::Cancelled`, then returns `RouterError::NoRoutableLayer` | an error |

The boundaries catch panics, not stack overflows. Everything *below* the
maze search deliberately panics rather than degrading, because the necked
retry in `route_connection_full` is the real recovery. `panic = "abort"`
must stay unset in the release profile: `AutorouteEngine::drill_page_drills`
restores the drill-page grid through `catch_unwind`/`resume_unwind`.

## `Arena<T>`, and why not `slotmap`

The autoroute object graph is cyclic: a room holds its doors, a door holds
both of its rooms, a drill holds one room per layer. `Rc<RefCell<…>>` would
make the engine's borrow of a `Send + Sync` `Board` unrepresentable, so every
room, door, drill and page lives in an `Arena<T>` — a `Vec<Option<T>>`
addressed by a `u32` index — and the newtypes `RoomId`, `ObstacleRoomId`,
`IncompleteRoomId`, `DoorId`, `TargetDoorId`, `DrillId`, `PageId` and
`ConnectionId` are those indices.

It has **no generation counter**, deliberately. `Arena::remove` leaves a
permanent hole and **indices are never reused**: `insert` always appends, so
an index stays valid, or permanently empty, for the arena's whole life. A
long run's arena grows to the total number of objects ever created rather
than the live count. `Arena::clear` drops the indices as well and is only
sound between connections, when no id from the old arena survives.
`DrillPage::invalidate` frees its own drill ids, because pages are
invalidated once per changed item and leaving the slots would grow the arena
for the whole run.

## The maze search in outline

1. `AutorouteControl::from_settings` copies the numbers the search reads —
   trace half widths and costs per layer, via costs and masks, ripup costs,
   the fanout escape window — so the search never touches `RouterSettings`.
2. `MazeSearchEngine::init` seeds the queue with the start items' expansion
   rooms and target doors. A seed refused by the escape window is dropped.
3. The pop loop takes the cheapest `MazeListElement` — ordered by sorting
   value, then expansion value, then door id — and expands it: through its
   room's doors (`expand.rs`), to a drill page or a drill (`MazeExpansionEngine`),
   or through a rippable obstacle (`MazeRipupResolver`, which prices the
   ripup from the obstacle's half width, its detour and the pass number, with
   a pseudo-random scaling from pass 4 on). The A\* cost is the expansion
   value plus a bend penalty (charged above `sin² > 0.01`, about 5.7°) plus
   `DestinationDistance`'s lower bound.
4. `FoundConnectionLocator` walks the backtrack chain into corner lists per
   layer, in the board's angle regime.
5. `FoundConnectionInserter` derives the vias from the layer changes, inserts
   each corner run through `insert_forced_trace_polyline` (which shoves,
   springs over obstacles and pull-tightens), connects the ends, and
   normalises.

`ExpansionDoor`'s id is a hash of its two rooms' ids, not an identity, and it
is the third sort key of the queue; the same is true of `ObstacleExpansionRoom`
and `IncompleteFreeSpaceExpansionRoom`. Only `CompleteFreeSpaceExpansionRoom`
carries a true counter id. Complete-room ids **skip** — the counter ticks once
per neighbour calculation, including ones that build no room — and the arena
index is a different number; both are minted in creation order.

## The pass loop, fanout and optimizer in outline

**The work list** is every routable item with an unconnected set, in board
order, sorted ascending by airline distance. A two-net item that qualifies
on both nets enters the list twice and is routed on every net each time.

**`AutorouteBatchLoop::run`** repeats passes until the pass cap, until a
pass routes and fails nothing, until the score stops improving over the
stagnation window, or until the stop flag rises. `BoardHistory` remembers
the best boards seen; the loop restores from it mid-run when a pass makes
the board worse and swaps the best board in at the end, so the board written
out is the *best* pass's, not the *last* pass's. `restore` is a
`Board::deep_copy` — memoised caches reset, the item-id counter preserved.

**`BatchFanout`** runs first when enabled: components sorted by pin count
descending then id, each SMD pin escaped through `RoutingBoardExt::fanout`
under a per-pin time budget, up to a fixed number of passes or until a pass
changes nothing.

**`BatchOptimizer::run_batch_loop`** runs after routing unless the stop flag
is `ALL`. Each pass visits the routed items in a fixed order, re-routes each
one with its trace removed, and keeps the result only if the board score
rises; otherwise it rolls the item back through `Board::undo_from_snapshot`,
which replays the attempt's changes back through the live search trees. A
pass that improves nothing ends the stage.

`route_connection_full`'s tail — `opt_changed_area` (the tightener sweep
over the region a connection changed), the necked retry with a narrower
trace, and the strict-DRC rollback that removes a connection whose insert
created a violation — runs after every connection.

Two guards on the fanout path are the router's own rather than inherited
behaviour: the micro-neckdown fallback never emits a trace narrower than
the design's minimum net-class width, and the work list is airline-sorted.
`benchmark/reports/java-regressions-2026-09.md` measures why.

## The score

`score::BoardStatistics` is the per-board metric block: board, layers,
items, components, pads, nets, connections (with the incomplete count),
traces (total length, per layer), bends, vias, clearance violations (from
`copper-drc`) and fanout. `normalized_score` folds it into one number from the
`ScoringSettings` weights; the pass loop, the optimizer and `BoardHistory`
rank boards by it, and the result manifest and DRC report carry it.
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

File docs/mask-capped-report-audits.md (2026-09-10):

# Additional findings on boards with capped KiCad reports

These diagnostics validate specific added mask findings. They do not replace the full routing evaluation or imply an uncapped full-board comparison.

## Dropbot

The NPTH correction changes the native full-board mask count 331→332; the archived KiCad report stops at 199. The added pair is SW1's unnetted NPTH pad and rear pad 3. Retained those two pads from the exact saved source, with their footprint and original project; removed other footprints, routing, zones and other SW1 pads from a diagnostic copy.

KiCad 10.0.4 reports one rear mask bridge between those same items, matching the cumulative candidate. The source NPTH pad has 0.254 mm effective expansion despite having no remaining copper. The other pad's expansion is also 0.254 mm. The required gap is 0.508 mm and the copper-shape gap 0.150 mm. The specific new finding is therefore confirmed independently. Other unmodified findings are retained in the diagnostic report.

## Mechaduino DR

The layer correction adds eight mask findings while the full-board KiCad report is capped at 199. Two overlapping HS pads have identical size, position, net and logical pad number but opposite copper sides; both declare front and back mask openings. The added findings are two pad/track comparisons on the opposite mask side and six pad/pad comparisons with U2. This includes KiCad's multiplicity for the two distinct HS pad objects, rather than eight independent new physical defects.
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

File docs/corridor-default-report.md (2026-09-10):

# Corridor guidance enabled by default

Related signals now receive corridor guidance without an environment variable. Its existing final post-shove path check uses the same predicate. `COPPERROUTE_CORRIDOR_GUIDANCE=0` disables guidance; unset or `1` enables it. No routing-cost or insertion algorithms changed. The rejected protected-prefix prototype is excluded.
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

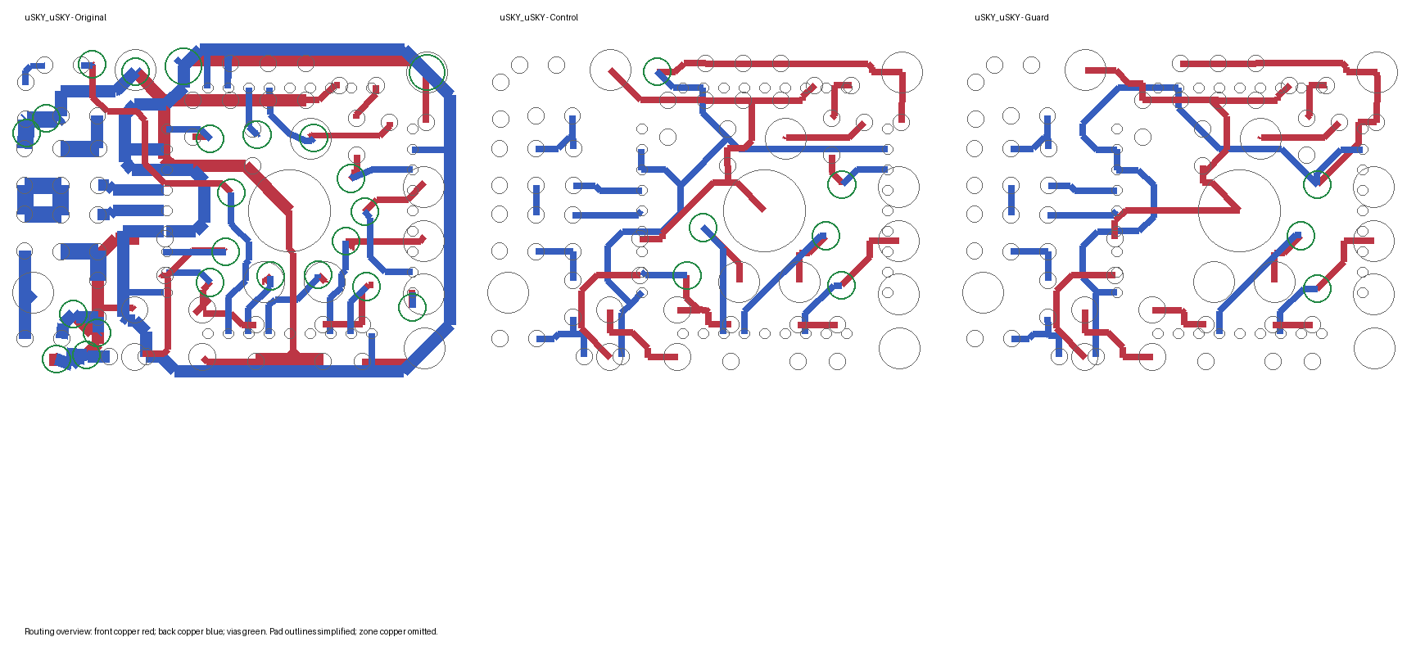
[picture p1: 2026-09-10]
docs/routing-quality-artifacts/shove-revalidation/uSKY_uSKY-routing-overview.png

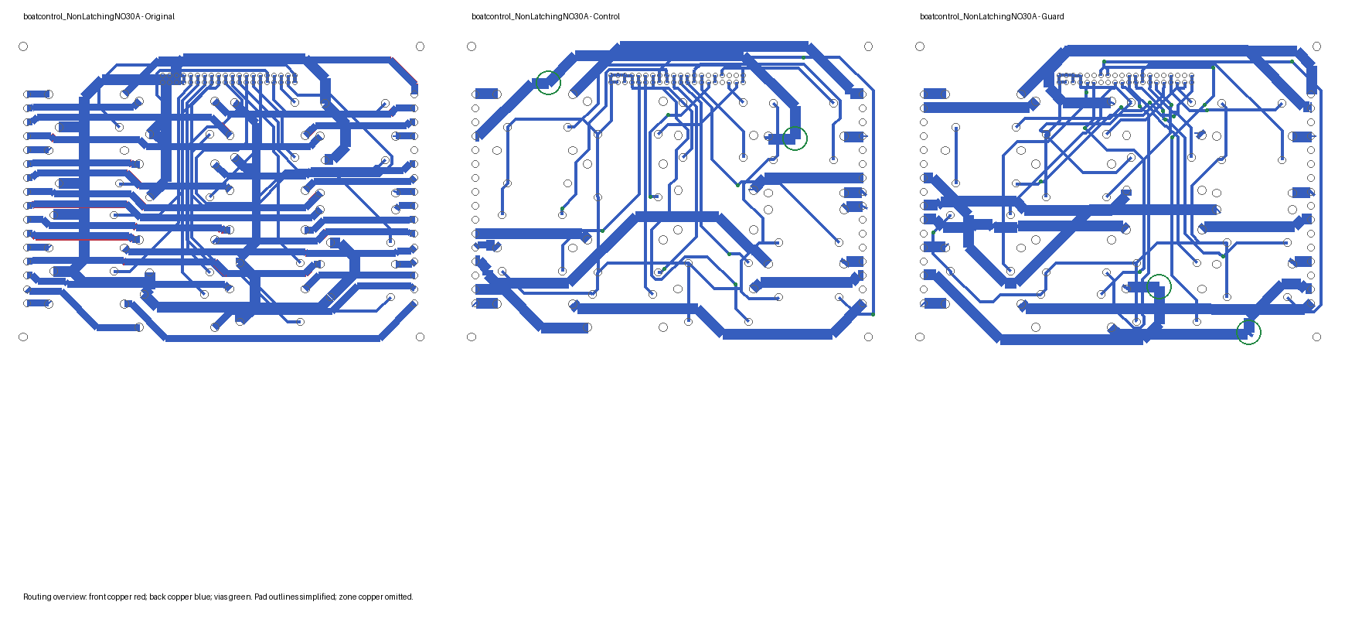
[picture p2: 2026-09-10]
docs/routing-quality-artifacts/shove-revalidation/boatcontrol_NonLatchingNO30A-routing-overview.png

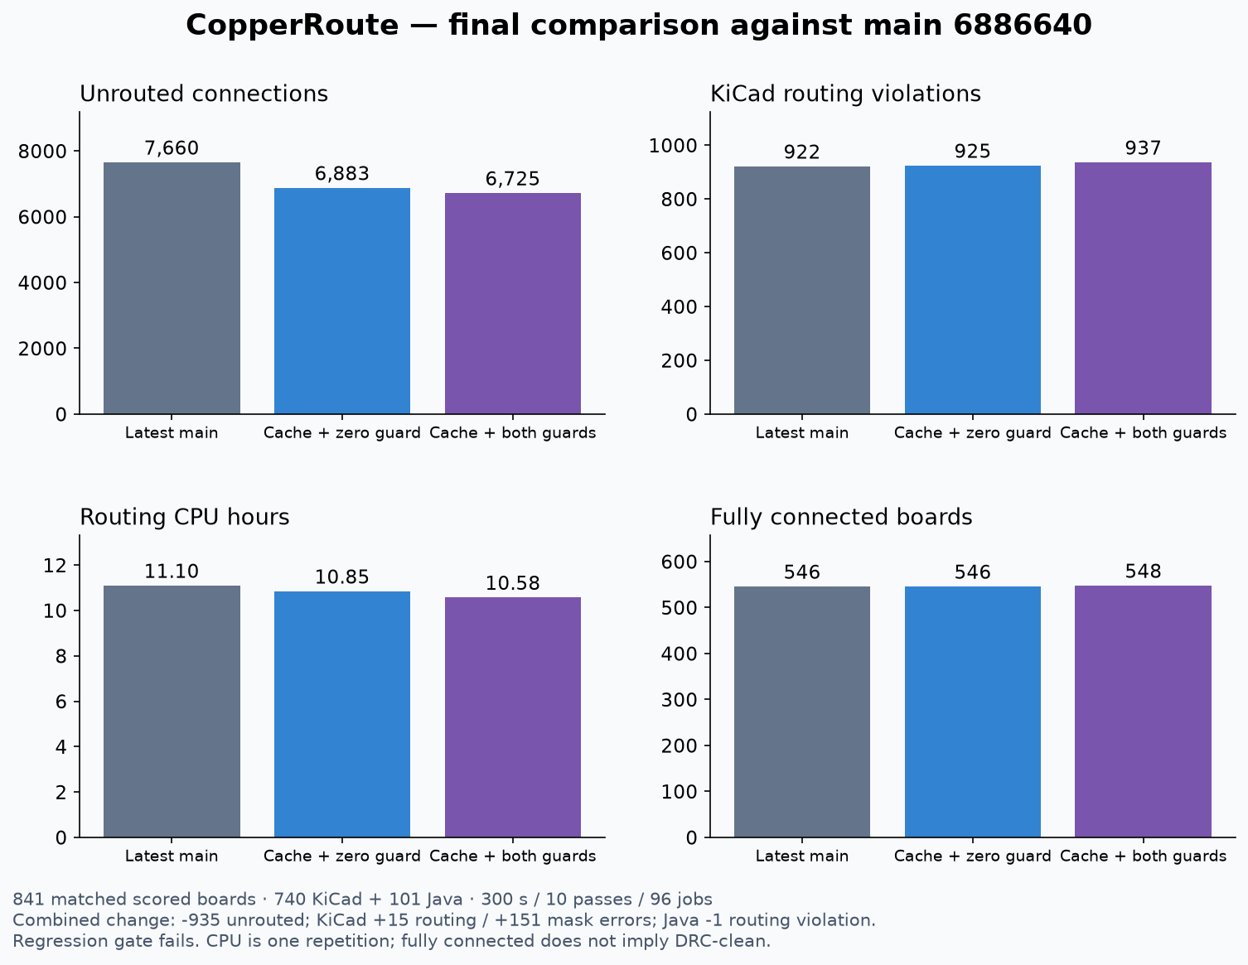
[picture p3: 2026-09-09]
docs/routing-quality-pr-chart.png

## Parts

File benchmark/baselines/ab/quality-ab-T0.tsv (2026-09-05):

# gate-version: g1
# task: T0
# port-sha: 5238a04a579f +uncommitted-changes-under-crates
# repeats: 3
# port-baseline: (none — this run seeds the rolling baseline)
# jar-baseline: benchmark/baselines/quality-baseline-java-head.tsv [absent — Task 1 writes it; the jar_* columns render `-`]
# time-baseline: benchmark/baselines/stem-times.tsv [absent — this run seeds it]
# corpus-median-cpu-ratio: (no time baseline)
# source-of-incomplete-and-violations: the referee's DRC document (`-de <board> <ses> -drc <report>`), NEVER the manifest (survey §4.1)
# forbidden-inputs: traces.total_{vertical,horizontal,angled}_length (#195), board.bounding_box.width/height (#196)
# quality-lane-budget: RouterBudget::disabled() (ruling AI); cpu_s lane: RouterBudget::default()
# cols:family | stem | mp_cap | incomplete | violations | clearance_violations | hole_clearance_violations | normalized_score | trace_length_mm | via_total | via_through | via_blind | via_buried | bend_count | cpu_s | cpu_spread_s | jar_incomplete | jar_violations | jar_clearance_violations | jar_normalized_score | flag
batch | router-rpi-splitter | 8 | 0 | 0 | 0 | 0 | 999.9719 | 111.2505 | 9 | 9 | 0 | 0 | 14 | 0.072 | 0.000 | - | - | - | - | seed
batch | router-dac2020-bm01 | 2 | 31 | 0 | 0 | 0 | 825.6295 | 2972.233 | 81 | 81 | 0 | 0 | 413 | 15.189 | 0.260 | - | - | - | - | seed
batch | router-j2-reference | 99 | 0 | 0 | 0 | 0 | 999.9895 | 377.88388 | 16 | 16 | 0 | 0 | 54 | 0.341 | 0.030 | - | - | - | - | seed
batch | router-tutorial-board | 8 | 0 | 0 | 0 | 0 | 0.0 | 0.0 | 0 | 0 | 0 | 0 | 0 | 6.893 | 0.094 | - | - | - | - | seed
batch | router-ecc83-input | 8 | 0 | 0 | 0 | 0 | 999.997 | 161.87364 | 0 | 0 | 0 | 0 | 15 | 0.028 | 0.001 | - | - | - | - | seed
batch | router-fanout-bm11 | 2 | 2 | 5 | 0 | 0 | 987.4912 | 1632.4795 | 53 | 53 | 0 | 0 | 275 | 5.592 | 0.036 | - | - | - | - | seed
batch | router-strict-drc-cnh | 2 | 11 | 17 | 0 | 16 | 930.0412 | 5038.2734 | 4 | 4 | 0 | 0 | 294 | 10.863 | 0.028 | - | - | - | - | seed
batch | router-empty-board | 1 | 0 | 0 | 0 | 0 | 0.0 | 0.0 | 0 | 0 | 0 | 0 | 0 | 0.005 | 0.001 | - | - | - | - | seed
cli | router-rpi-splitter | 8 | 0 | 0 | 0 | 0 | 999.9719 | 111.2505 | 9 | 9 | 0 | 0 | 14 | 0.071 | 0.001 | - | - | - | - | seed
cli | router-j2-reference | 99 | 0 | 0 | 0 | 0 | 999.9895 | 377.88388 | 16 | 16 | 0 | 0 | 54 | 0.321 | 0.003 | - | - | - | - | seed
cli | router-ecc83-input | 8 | 0 | 0 | 0 | 0 | 999.997 | 161.87364 | 0 | 0 | 0 | 0 | 15 | 0.029 | 0.001 | - | - | - | - | seed
cli | router-empty-board | 1 | 0 | 0 | 0 | 0 | 0.0 | 0.0 | 0 | 0 | 0 | 0 | 0 | 0.005 | 0.000 | - | - | - | - | seed
cli | router-dac2020-bm01 | 2 | 31 | 0 | 0 | 0 | 825.6295 | 2972.233 | 81 | 81 | 0 | 0 | 413 | 14.957 | 0.039 | - | - | - | - | seed
cli | router-tutorial-board | 8 | 0 | 0 | 0 | 0 | 0.0 | 0.0 | 0 | 0 | 0 | 0 | 0 | 6.923 | 0.086 | - | - | - | - | seed
cli | router-fanout-bm11 | 2 | 2 | 5 | 0 | 0 | 987.4912 | 1632.4795 | 53 | 53 | 0 | 0 | 275 | 5.583 | 0.018 | - | - | - | - | seed
cli | router-strict-drc-cnh | 2 | 11 | 17 | 0 | 16 | 930.0412 | 5038.2734 | 4 | 4 | 0 | 0 | 294 | 10.882 | 0.050 | - | - | - | - | seed
cli | tutorial_board | default | 0 | 0 | 0 | 0 | 0.0 | 0.0 | 0 | 0 | 0 | 0 | 0 | 6.845 | 0.022 | - | - | - | - | seed
cli | Issue026-J2_reference | default | 0 | 0 | 0 | 0 | 999.9895 | 377.88388 | 16 | 16 | 0 | 0 | 54 | 0.323 | 0.002 | - | - | - | - | seed
cli | large-outline | 2 | 8 | 415 | 0 | 400 | 823.31805 | 4812.476 | 162 | 162 | 0 | 0 | 534 | 4.983 | 0.016 | - | - | - | - | seed
cli | kicad-ecc83-json | 3 | 6 | 14 | 0 | 14 | 309.99774 | 113.13041 | 0 | 0 | 0 | 0 | 11 | 0.297 | 0.003 | - | - | - | - | seed
cli | kicad-complex-hierarchy-json | default | 0 | 36 | 0 | 36 | 935.709 | 1399.8671 | 0 | 0 | 0 | 0 | 154 | 2.721 | 0.002 | - | - | - | - | seed
drc | drc-dev-board | n/a | 4 | 10 | 0 | 2 | - | - | - | - | - | - | - | 0.045 | 0.000 | - | - | - | - | seed
drc | drc-bbd-mars-64 | n/a | 3 | 96 | 12 | 64 | - | - | - | - | - | - | - | 0.054 | 0.001 | - | - | - | - | seed
drc | drc-natural-tone-preamp | n/a | 44 | 112 | 0 | 0 | - | - | - | - | - | - | - | 0.123 | 0.002 | - | - | - | - | seed
drc | drc-issue593-rules | n/a | 74 | 0 | 0 | 0 | - | - | - | - | - | - | - | 0.012 | 0.001 | - | - | - | - | seed
drc | drc-issue593-ses | n/a | 45 | 13 | 0 | 0 | - | - | - | - | - | - | - | 0.028 | 0.001 | - | - | - | - | seed
drc | drc-issue753-cpu85 | n/a | 169 | 107 | 0 | 78 | - | - | - | - | - | - | - | 0.124 | 0.001 | - | - | - | - | seed
drc | drc-issue110-relay | n/a | 44 | 26 | 0 | 4 | - | - | - | - | - | - | - | 0.012 | 0.001 | - | - | - | - | seed
drc | drc-tutorial-board | n/a | 0 | 0 | 0 | 0 | - | - | - | - | - | - | - | 0.832 | 0.007 | - | - | - | - | seed

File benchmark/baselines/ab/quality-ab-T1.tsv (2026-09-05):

# gate-version: g1
# task: T1
# port-sha: 4c59c86c41cb
# repeats: 3
# port-baseline: benchmark/baselines/ab/quality-ab-T0.tsv
# jar-baseline: benchmark/baselines/quality-baseline-java-head.tsv [read; rendered in the jar_* columns as context, never a gate; 29 stems]
# time-baseline: benchmark/baselines/stem-times.tsv
# corpus-median-cpu-ratio: 1.000
# source-of-incomplete-and-violations: the referee's DRC document (`-de <board> <ses> -drc <report>`), NEVER the manifest (survey §4.1)
# forbidden-inputs: traces.total_{vertical,horizontal,angled}_length (#195), board.bounding_box.width/height (#196)
# quality-lane-budget: RouterBudget::disabled() (ruling AI); cpu_s lane: RouterBudget::default()
# cols:family | stem | mp_cap | incomplete | violations | clearance_violations | hole_clearance_violations | normalized_score | trace_length_mm | via_total | via_through | via_blind | via_buried | bend_count | cpu_s | cpu_spread_s | jar_incomplete | jar_violations | jar_clearance_violations | jar_normalized_score | flag
batch | router-rpi-splitter | 8 | 0 | 0 | 0 | 0 | 999.9719 | 111.2505 | 9 | 9 | 0 | 0 | 14 | 0.073 | 0.002 | 0 | 0 | 0 | 999.9719 | ok
batch | router-dac2020-bm01 | 2 | 31 | 0 | 0 | 0 | 825.6295 | 2972.233 | 81 | 81 | 0 | 0 | 413 | 15.421 | 0.562 | 31 | 0 | 0 | 825.6295 | ok
batch | router-j2-reference | 99 | 0 | 0 | 0 | 0 | 999.9895 | 377.88388 | 16 | 16 | 0 | 0 | 54 | 0.327 | 0.008 | 0 | 0 | 0 | 999.9895 | ok
batch | router-tutorial-board | 8 | 0 | 0 | 0 | 0 | 0.0 | 0.0 | 0 | 0 | 0 | 0 | 0 | 7.068 | 0.210 | 0 | 0 | 0 | 0.0 | ok
batch | router-ecc83-input | 8 | 0 | 0 | 0 | 0 | 999.997 | 161.87364 | 0 | 0 | 0 | 0 | 15 | 0.028 | 0.002 | 0 | 0 | 0 | 999.997 | ok
batch | router-fanout-bm11 | 2 | 2 | 5 | 0 | 0 | 987.4912 | 1632.4795 | 53 | 53 | 0 | 0 | 275 | 5.844 | 0.290 | 2 | 5 | 0 | 987.4912 | ok
batch | router-strict-drc-cnh | 2 | 11 | 17 | 0 | 16 | 930.0412 | 5038.2734 | 4 | 4 | 0 | 0 | 294 | 11.239 | 0.246 | 11 | 17 | 0 | 930.0412 | ok
batch | router-empty-board | 1 | 0 | 0 | 0 | 0 | 0.0 | 0.0 | 0 | 0 | 0 | 0 | 0 | 0.006 | 0.002 | 0 | 0 | 0 | 0.0 | ok
cli | router-rpi-splitter | 8 | 0 | 0 | 0 | 0 | 999.9719 | 111.2505 | 9 | 9 | 0 | 0 | 14 | 0.080 | 0.009 | 0 | 0 | 0 | 999.9719 | ok
cli | router-j2-reference | 99 | 0 | 0 | 0 | 0 | 999.9895 | 377.88388 | 16 | 16 | 0 | 0 | 54 | 0.329 | 0.007 | 0 | 0 | 0 | 999.9895 | ok
cli | router-ecc83-input | 8 | 0 | 0 | 0 | 0 | 999.997 | 161.87364 | 0 | 0 | 0 | 0 | 15 | 0.029 | 0.001 | 0 | 0 | 0 | 999.997 | ok
cli | router-empty-board | 1 | 0 | 0 | 0 | 0 | 0.0 | 0.0 | 0 | 0 | 0 | 0 | 0 | 0.006 | 0.001 | 0 | 0 | 0 | 0.0 | ok
cli | router-dac2020-bm01 | 2 | 31 | 0 | 0 | 0 | 825.6295 | 2972.233 | 81 | 81 | 0 | 0 | 413 | 15.139 | 0.134 | 31 | 0 | 0 | 825.6295 | ok
cli | router-tutorial-board | 8 | 0 | 0 | 0 | 0 | 0.0 | 0.0 | 0 | 0 | 0 | 0 | 0 | 6.926 | 0.045 | 0 | 0 | 0 | 0.0 | ok
cli | router-fanout-bm11 | 2 | 2 | 5 | 0 | 0 | 987.4912 | 1632.4795 | 53 | 53 | 0 | 0 | 275 | 5.570 | 0.018 | 2 | 5 | 0 | 987.4912 | ok
cli | router-strict-drc-cnh | 2 | 11 | 17 | 0 | 16 | 930.0412 | 5038.2734 | 4 | 4 | 0 | 0 | 294 | 10.850 | 0.029 | 11 | 17 | 0 | 930.0412 | ok
cli | tutorial_board | default | 0 | 0 | 0 | 0 | 0.0 | 0.0 | 0 | 0 | 0 | 0 | 0 | 6.889 | 0.020 | 0 | 0 | 0 | 0.0 | ok
cli | Issue026-J2_reference | default | 0 | 0 | 0 | 0 | 999.9895 | 377.88388 | 16 | 16 | 0 | 0 | 54 | 0.320 | 0.003 | 0 | 0 | 0 | 999.9895 | ok
cli | large-outline | 2 | 8 | 415 | 0 | 400 | 823.31805 | 4812.476 | 162 | 162 | 0 | 0 | 534 | 4.970 | 0.015 | 8 | 415 | 0 | 823.31805 | ok
cli | kicad-ecc83-json | 3 | 6 | 14 | 0 | 14 | 309.99774 | 113.13041 | 0 | 0 | 0 | 0 | 11 | 0.296 | 0.003 | 6 | 14 | 0 | 309.99774 | ok
cli | kicad-complex-hierarchy-json | default | 0 | 36 | 0 | 36 | 935.709 | 1399.8671 | 0 | 0 | 0 | 0 | 154 | 2.724 | 0.011 | 0 | 36 | 0 | 935.709 | ok
drc | drc-dev-board | n/a | 4 | 10 | 0 | 2 | - | - | - | - | - | - | - | 0.046 | 0.000 | 4 | 10 | 0 | - | ok
drc | drc-bbd-mars-64 | n/a | 3 | 96 | 12 | 64 | - | - | - | - | - | - | - | 0.054 | 0.001 | 3 | 96 | 12 | - | ok
drc | drc-natural-tone-preamp | n/a | 44 | 112 | 0 | 0 | - | - | - | - | - | - | - | 0.122 | 0.004 | 44 | 115 | 0 | - | ok
drc | drc-issue593-rules | n/a | 74 | 0 | 0 | 0 | - | - | - | - | - | - | - | 0.011 | 0.001 | 74 | 0 | 0 | - | ok
drc | drc-issue593-ses | n/a | 45 | 13 | 0 | 0 | - | - | - | - | - | - | - | 0.028 | 0.001 | 45 | 13 | 0 | - | ok
drc | drc-issue753-cpu85 | n/a | 169 | 107 | 0 | 78 | - | - | - | - | - | - | - | 0.124 | 0.002 | 169 | 107 | 0 | - | ok
drc | drc-issue110-relay | n/a | 44 | 26 | 0 | 4 | - | - | - | - | - | - | - | 0.013 | 0.000 | 44 | 26 | 0 | - | ok
drc | drc-tutorial-board | n/a | 0 | 0 | 0 | 0 | - | - | - | - | - | - | - | 0.831 | 0.002 | 0 | 0 | 0 | - | ok

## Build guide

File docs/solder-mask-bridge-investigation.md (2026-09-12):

# Solder mask bridges: a real routing rule the router cannot see

Routed boards scored by `kicad-cli` report `solder_mask_bridge` errors. This report
establishes where they come from, shows they are caused by the routing rather than by the
source board, and identifies the three places the rule is missing.

## Result

A solder mask aperture is the pad opening: the pad copper grown by the board's mask
expansion. KiCad reports `solder_mask_bridge` when copper of a *different* net enters that
aperture — two nets exposed through one opening will short when the board is soldered.

The gap a foreign net must keep from a pad's copper was measured against `kicad-cli`
10.0.3 across sixteen configurations, to 0.01 mm:

```
threshold gap (mm) at which solder_mask_bridge clears
  expansion \ mask-to-copper    0.00   0.10   0.20   0.30
                       0.00     0.00   0.10   0.20   0.30
                       0.10     0.10   0.20   0.20   0.30
                       0.20     0.20   0.30   0.40   0.40
                       0.30     0.30   0.40   0.50   0.60
```

The two mask terms add: `pad_to_mask_clearance + solder_mask_to_copper_clearance` fits
thirteen of the sixteen cells exactly. The three it misses — `(0.1, 0.2)`, `(0.1, 0.3)` and
`(0.2, 0.3)`, all where expansion is the smaller of the two nonzero terms — it
over-estimates by 0.1 mm, so using it as the rule never under-clears.

The keepout a foreign-net track must respect around a pad is therefore

```
max(net_class_clearance, pad_to_mask_clearance + solder_mask_to_copper_clearance)
```

The router enforces only the first term. Whenever the sum of the two mask terms exceeds
the net class clearance, the router routes to a gap that is legal under copper clearance
and illegal under mask, and `kicad-cli` reports a bridge.

On the benchmark corpus this rarely matters in practice: `benchmark/vendor/kicad/legacy_rules.py`
lists `solder_mask_to_copper_clearance` among `_ZEROED_RULE_KEYS`, so every generated
`.kicad_pro` sets it to zero — the matrix's first column, where the required gap is exactly
the mask expansion.

## Evidence

Synthetic board, `kicad-cli` 10.0.3: one pad on `NETA`, a `NETB` track running past it at a
controlled copper-edge-to-copper-edge gap, net class clearance 0.2 mm.

With `pad_to_mask_clearance` 0.4 mm:

| gap (mm) | KiCad errors |
|---:|---|
| 0.10 | `clearance`, `solder_mask_bridge` |
| 0.15 | `clearance`, `solder_mask_bridge` |
| 0.20 | `solder_mask_bridge` |
| 0.25 | `solder_mask_bridge` |
| 0.30 | `solder_mask_bridge` |
| 0.40 | clean |

The three rows at 0.20–0.30 mm are the finding: copper clearance is satisfied, and the
board is still a DRC failure. The threshold tracks the mask term exactly — sweeping
`pad_to_mask_clearance` at 0.0 / 0.2 / 0.3 / 0.4 mm moves the first clean gap to 0.2 / 0.2 /
0.3 / 0.4 mm respectively, and setting `solder_mask_to_copper_clearance` to 0.3 mm with zero
expansion moves it to 0.3 mm. Each of these sweeps varies one mask term while the other is
zero, which the sixteen-configuration matrix above confirms is exactly where addition and a
plain maximum agree; that fuller matrix is what pins the rule down to addition.

The violations are caused by the routing. The same board, same mask settings, at a gap of
0.25 mm — copper-legal — differs only in whether the track is present:

```
routed  : {'solder_mask_bridge': 1}
stripped: {}
```

This is not pre-existing pad-to-pad noise. It is geometry the router chose, and could have
chosen differently.

## Why nothing caught it

**The router has no mask data.** `pad_to_mask_clearance` and `solder_mask_min_width` live in
the `.kicad_pcb` `(setup)` block. Neither the Specctra DSN nor the `.kicad_pro` carries them,
and `KiCadBoardJson` (`crates/copper-dsn/src/kicad/dto.rs`) has no field for either — it
carries `clearance`, `traceWidth`, `viaDiameter`, `viaDrill` and nothing about mask.
`BoardRules` has no mask concept at all.

**The port has no mask check.** `DrcViolationKind` (`crates/copper-drc/src/violation.rs:5`)
has eleven variants and none is a mask kind.

**The oracle cannot fail on it.** `oracle_counts` in
`crates/copper-drc/tests/kicad_oracle.rs:132` tallies a KiCad violation only when
`DrcViolationKind::from_kicad_type(kind).is_some()`. A check the port does not implement is
dropped from the expected counts as well as the actual ones, so a missing check is invisible
to the test by construction. The six oracle fixtures happen to carry no mask violations, so
nothing pointed at the gap from the data either.

**The benchmark scores it as noise.** `ROUTING_DRC_TYPES`
(`benchmark/bench/referee/kicad.py:39`) lists the types that count toward `violations` and
`clean_pass`. `solder_mask_bridge` is absent, so mask bridges are classed with footprint and
silkscreen findings as pre-existing artwork noise the router never touches. The experiment
above shows that classification is wrong: this type belongs in the routing set. It still
surfaces in `violations_by_type` and `violations_all`, which is where it is visible today.

## What closing it requires

1. **Represent** — carry `pad_to_mask_clearance` and `solder_mask_to_copper_clearance` into
   `BoardRules`. The DSN cannot supply them; they need a path from the `.kicad_pcb`
   `(setup)` block, alongside the existing `apply_kicad_project` route for `.kicad_pro`
   rules.
2. **Check** — add a mask violation kind and check to `copper-drc`, which also makes the
   oracle able to compare the type.
3. **Enforce** — widen the pad keepout the maze and shover use from the net class clearance
   to `max(net_class_clearance, pad_to_mask_clearance + solder_mask_to_copper_clearance)`.
   This is the half that removes the violations rather than reporting them.

Steps 1 and 2 make the failures visible and measurable. Only step 3 changes a board.
Because the effective keepout only grows where the sum of the mask terms exceeds the net
class clearance, boards whose mask expansion is small or zero are unaffected.

## Reproducing

The measurements above come from a generated board and a gap sweep driven through
`kicad-cli pcb drc --format json`. The generator writes a board with one `NETA` pad, a `NETB`
track at a chosen gap, and chosen `pad_to_mask_clearance` / `solder_mask_min_width` values;
the sweep runs DRC per gap and counts error-severity violations by type. `solder_mask_min_width`
had no effect on this geometry at any value tested — it governs the web between two
apertures, not copper under mask.

## Can the native KiCad reader measure stage two?

Stage two needs mask settings out of a `.kicad_pcb`'s `(setup)` block, which the native
reader (`copper_dsn::kicad::pcb::read_pcb`) reads directly rather than through a DSN plus
`--kicad-board`. Whether stage two can run on that path instead depends on how much of the
corpus the reader accepts, which requires the corpus.

`crates/copper-dsn/tests/kicad_pcb_corpus.rs` checks the eleven cells with the largest
`solder_mask_bridge` counts; `scripts/kicad-pcb-import-survey.sh <corpus root>` runs
`copperroute info` across the whole corpus and reports an accept rate. Both are opt-in and
have not been run against the corpus: it lives on em@workbench, not in this checkout. Run

```
COPPERROUTE_PCBENCH=<corpus root> cargo test -p copper-dsn --test kicad_pcb_corpus -- --nocapture
scripts/kicad-pcb-import-survey.sh <corpus root>
```

to get the accept rate and the per-board refusal reasons before stage two is planned. Sort
each refusal into one of two categories:

- a **porting bug**, where `node crates/copper-dsn/tests/data/kicad_pcb_parity.mjs <board>`
  accepts the same board the Rust refuses — fix it;
- a **shared limitation**, where the JS adapter refuses it too, for a construct neither
  supports — leave it, and record it here rather than chasing a bug that is not there. See
  `crates/copper-dsn/README.md`'s "Reading a `.kicad_pcb` file directly" section for the
  current list of constructs `read_pcb` refuses outright; do not copy that list here, since a
  second copy is exactly what would let this section and the README drift apart.

If the accept rate against the corpus turns out low and the refusals are mostly shared
limitations rather than porting bugs, stage two should reach the mask settings through
`--kicad-board` beside a DSN instead of the native path.

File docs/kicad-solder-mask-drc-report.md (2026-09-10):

# Solder-mask checker validation

The proposed checker detects foreign tracks and vias that violate a pad's mask
aperture or the project's mask-to-copper clearance. KiCad remains the external
referee. This change does not include nominal clearance, smoothing, router mask
floors, dogleg escapes, or connection scheduling experiments.

The browser import retains per-pad front/back exposure, board/footprint/pad
expansion precedence, explicit zero and negative expansion, and explicit
footprint permission for solder-mask bridges. Native board import preserves
those values. The check refines corner distances instead of relying solely on
the router's octagonal approximation. Copper-clearance rules remain independent
of mask-bridge permission.

Four included synthetic KiCad 10.0.3 references exercise an illegal mask gap
with legal copper clearance, additional project clearance, a clear off-axis
corner, and an explicitly permitted bridge. Each new behavior had a failing
regression test before implementation. Full validation: **2,570 Rust tests
passed, 77 ignored; 47 web tests passed**.

| Finished session | Internal routing-mask reports | External KiCad evidence |
|---|---:|---|
| LPC2148 nominal/smoothing | 111 | 107 reports match full-board pad/net/layer keys; four more are confirmed on isolated boards |
| LPC2148 mask/dogleg control | 0 | Zero routing-related mask reports; 68 total mask reports include fixed geometry |
| EncoderBoard nominal/smoothing | 0 | Zero routing-related mask reports; 39 total mask reports include fixed geometry |
| Own-Mailbox main, whole board | 353 | All reports match KiCad probes; internal check finds 302 of 305 pad/net/layer keys, missing three unnetted-pad contacts |

Two initial LPC corner false positives, involving a track and a circular via,
were removed by the distance refinement. Report counts do not directly express
precision or recall because Rust joins track segments and KiCad groups apertures.
The Mailbox comparison uses 465 separate probes retaining copper while
exposing one pad aperture per probe. Each stays below KiCad's per-type report
limit; this is local contact evidence rather than a substitute full-board score.

Metadata matching covers all 331 LPC pads and all 461 routed Mailbox pins
(465 original pads, including mechanical geometry). Encoder matches 137/150
original pads and leaves eight synthetic router pins unmatched. The diagnostic
session loader's matching is not a production metadata-import feature.

Coverage is intentionally explicit: unnetted pads, pad-to-pad mask webs and mask
artwork are not implemented in this check; the browser already rejects net-tie footprints.
The three unmatched KiCad keys concern unnetted pads D2.3, IC2.58, and one
physical P3.5 pad. Plain DSN inputs do not carry pad-mask metadata. A clean internal result does
not certify a board as KiCad-clean.

The independent full-corpus run `quality-kicad-drc-01` is complete: all
751 boards have valid KiCad scores. It compares the frozen checker candidate
against main `e9d10c2`, using 10 passes, 300 seconds, one routing thread and
12 jobs on workbench. The measured code matches all 30 implementation/test
source hashes in the local PR worktree.

| Population | Unrouted main → checker | Routing violations | Reported mask violations | CPU seconds main → checker | CPU ratio | Fully connected boards |
|---|---:|---:|---:|---:|---:|---:|
| 740 PCBench, KiCad | 5,321 → 5,069 | 947 → 945 | 13,834 → 13,915 | 37,427.84 → 34,932.14 | 0.9333 | 520 → 521 |
| 11 local, KiCad | 243 → 235 | 59 → 59 | 0 → 0 | 714.45 → 762.77 | 1.0676 | 6 → 6 |
| 751 total | 5,564 → 5,304 | 1,006 → 1,004 | 13,834 → 13,915 | 38,142.29 → 35,694.91 | 0.9358 | 526 → 527 |

PCBench has 14 boards with fewer unrouted connections and four with more;
two gain ordinary routing violations (net change −2). Local fixtures have
one connection improvement and no regression, with unchanged violations.
Total all-category KiCad errors are 17,978 → 18,057. Eighteen boards gain
reported mask errors and eleven lose them. There are no Java-refereed rows.

The standard benchmark gate **fails** on four routing-quality losses.
This result is retained, not replaced by the diagnostic comparisons below.
All 718 pairs where neither run timed out have byte-identical SES routing.
The other 33 pairs involve a timeout on at least one side. Some byte-identical
pairs have different mask totals near KiCad's per-type report cap (for example
badge2016: 203 → 229). These identical-routing pairs account for +62 of the
reported +81 mask delta; the other +19 is among timeout-affected pairs.
The counts on identical routes cannot establish a geometric regression.

The four boards with more unrouted connections are:

| Board | Unrouted main → checker | Routing violations main → checker |
|---|---:|---:|
| karabas-nano_karabas-nano-revC | 92 → 93 | 1 → 1 |
| decelerator4030_decelerator4030 | 481 → 486 | 10 → 11 |
| bms-8s50-ic_bms-8s50-ic | 52 → 53 | 0 → 0 |
| zx-sizif-512-ext_sizif512ext | 44 → 48 | 0 → 0 |

Memory (per-job peak RSS; medians and maxima across the population):

| Population | Median MiB main → checker | Maximum MiB main → checker |
|---|---:|---:|
| PCBench | 15.20 → 15.40 | 453.10 → 453.60 |
| Local | 20.40 → 20.50 | 75.20 → 109.10 |
| All | 15.20 → 15.40 | 453.10 → 453.60 |

Longer 1,200-second controls are complete, runs
`quality-kicad-drc-controls-01` and `-02`. They use the same frozen binaries,
one thread and ten passes; every referee succeeded.

| Board | State on both sides | Unrouted, each | Ordinary violations, each | Mask reports, each | SES files | CPU seconds main → checker |
|---|---|---:|---:|---:|---|---:|
| azalea | Completed, ten passes | 76 | 40 | 159 | Identical | 286.74 → 313.96 |
| bms-8s50-ic | Completed, ten passes | 53 | 0 | 88 | Identical | 542.78 → 544.90 |
| zx-sizif-512-ext | Completed, ten passes | 38 | 0 | 183 | Identical | 749.44 → 794.59 |
| karabas-nano-revC | Completed, ten passes | 40 | 1 | 199 | Identical | 845.90 → 912.89 |
| decelerator4030 | Timed out, six passes | 192 | 14 | 0 | Different partial routes | 1,197.02 → 1,197.17 |

The four completed controls establish identical finished routing for their
boards. Decelerator has equal quality counts at the longer cutoff but
still produces different partial routes; complete-route equivalence on that
board is unproven. The standard 300-second gate remains failed, and its
measurements are not replaced with these diagnostics.

This DSN run tests routing compatibility and cost; native-import oracle tests
and session audits separately validate the new mask behavior. No timing or
routing-quality improvement is claimed for the checker itself. One timing
repetition does not establish a speedup.

The deterministic-work diagnostic `quality-kicad-drc-items-01` is complete.
All five pairs stop after 100 routed items without a timeout, produce
byte-identical SES files, and have identical external KiCad scores:

| Board | Unrouted, each | Ordinary violations, each | Mask reports, each |
|---|---:|---:|---:|
| azalea | 110 | 39 | 159 |
| decelerator4030 | 499 (report cap) | 2 | 0 |
| bms-8s50-ic | 101 | 0 | 88 |
| karabas-nano-revC | 184 | 1 | 199 (report cap) |
| zx-sizif-512-ext | 306 | 0 | 183 |

This establishes matching output for the tested routing prefix on all five
problem boards; it does not claim complete-board convergence for decelerator. All ten
referee checks succeeded.

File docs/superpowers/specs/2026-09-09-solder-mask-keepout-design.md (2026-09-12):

# Solder mask keepout: design

Date: 2026-09-09. Status: design settled; the branch base is an open decision.

## Goal

Stop the router creating solder mask bridges. A foreign net must keep clear of a pad's
mask aperture, not merely of its copper.

This is stage two of the work begun in
`2026-09-09-native-kicad-board-input-design.md`. Stage one built the data path — the
command line reads a `.kicad_pcb` directly. This stage uses it, and is the stage that
changes boards.

## The rule, measured

A pad's mask aperture is its copper grown by the board's mask expansion. KiCad reports
`solder_mask_bridge` when copper of a different net enters that aperture. The gap a
foreign net must keep from a pad's copper was measured against `kicad-cli` 10.0.3 across
sixteen configurations, to 0.01 mm:

```
threshold gap (mm) at which solder_mask_bridge clears
  expansion \ mask-to-copper    0.00   0.10   0.20   0.30
                       0.00     0.00   0.10   0.20   0.30
                       0.10     0.10   0.20   0.20   0.30
                       0.20     0.20   0.30   0.40   0.40
                       0.30     0.30   0.40   0.50   0.60
```

The required gap is `pad_to_mask_clearance + solder_mask_to_copper_clearance`. That fits
thirteen of the sixteen cells exactly. The three it misses — `(0.1, 0.2)`, `(0.1, 0.3)`
and `(0.2, 0.3)`, all where expansion is the smaller of the two nonzero terms — it
over-estimates by 0.1 mm, so it never under-clears.

The keepout the router enforces around a pad is therefore

```
max(net_class_clearance, pad_to_mask_clearance + solder_mask_to_copper_clearance)
```

`docs/solder-mask-bridge-investigation.md` currently states this as a three-way maximum,
with the two mask terms not adding. That is wrong: a maximum under-estimates in six of the
sixteen cells, which would leave in place the violations this stage exists to remove. The
error came from a sweep whose sampled points all lay where the two candidate models
coincide. This stage corrects that document.

On the benchmark corpus the distinction does not arise.
`benchmark/vendor/kicad/legacy_rules.py` lists `solder_mask_to_copper_clearance` among
`_ZEROED_RULE_KEYS`, so every generated `.kicad_pro` sets it to zero — the matrix's first
column, where the required gap is exactly the mask expansion.

## Decisions taken

| Question | Decision |
|---|---|
| Keepout formula | `expansion + mask_to_copper`, per the measurements above. |
| Where it is applied | A per-pad clearance class in the clearance matrix, raised before routing. |
| Guard against harm | Each raised floor is capped at the pad's existing gap to the nearest foreign-net pad. Raising a mask clearance may never close a gap that was already routable, and may never lower an existing copper rule. |
| Enforcement source | Extracted from PR #25, which implements exactly this and has been measured across 751 boards. |
| Representation source | Extracted from PR #22, which carries the board-model fields any enforcement needs. |
| Mask data source | The `.kicad_pcb` parser from stage one, reading `(setup pad_to_mask_clearance)` and per-pad `(solder_mask_margin)`. No sidecar file. |

## Why not the alternatives

**A sidecar metadata file.** PR #25 reaches pad mask data on the DSN path through
`COPPERROUTE_PAD_CLEARANCE_JSON`, a KiCad-derived file passed alongside the board. It
works, but it is a third artifact that must be generated per board and kept in step with
the DSN, and a run that silently lacks it routes differently with no signal. Stage one
removed the need for it: the command line reads the board KiCad wrote.

**A global clearance increase.** Raising every clearance by the mask expansion would clear
the apertures, but would also push apart nets nowhere near a pad, costing routability
across the whole board for a constraint that only applies around pads.

## Components

| File | Change | Purpose |
|---|---|---|
| `crates/copper-board/src/items/drill.rs` | extend | `Pin::solder_mask_expansion` per layer, `Pin::allow_solder_mask_bridges`. From #22. |
| `crates/copper-board/src/rules/drc_constraints.rs` | extend | `solder_mask_to_copper_clearance`, resolved from project then DSN. From #22. |
| `crates/copper-board/src/board/clearance_override.rs` | extend | `raise_solder_mask_clearances`, `solder_mask_clearance_limit`, `raise_pin_clearance`. From #25, with the sidecar loader removed. |
| `crates/copper-router/src/pipeline/board_prep.rs` | extend | Raise the clearances before routing. From #25. |
| `crates/copper-dsn/src/kicad/dto.rs` | extend | `PadJson::solderMaskExpansion`, `PadJson::allowSolderMaskBridges`. From #22. |
| `crates/copper-dsn/src/kicad/reader.rs` | extend | Populate the pin from the DTO. From #22. |
| `crates/copper-dsn/src/kicad/pcb/footprints.rs` | extend | **New.** Populate `solderMaskExpansion` from the board's `(setup pad_to_mask_clearance)` and each pad's `(solder_mask_margin)` override. |
| `crates/copper-board/tests/pad_clearance.rs` | new | From #25. |
| `docs/solder-mask-bridge-investigation.md` | correct | Replace the maximum model with the measured matrix. |

The sidecar loader in #25's `clearance_override.rs` is dropped: its purpose was to reach
mask data the DSN could not carry, which the native reader now supplies directly.

## Verification

**The formula, against KiCad.** A test sweeping the sixteen measured configurations and
asserting the keepout the board computes matches the table above.

**The cap, against routability.** A test with two foreign pads closer together than their
mask expansion would demand, asserting the raised floor is capped at their existing gap
rather than closing it.

**The parser.** The stage-one parity test extends to `solderMaskExpansion`, so the Rust
and the JavaScript adapter must agree on the per-pad value.

**End to end.** A board with a known mask bridge routes clean after the change, verified
by `kicad-cli`, and its copper clearance violations do not increase.

**The corpus.** The eleven boards with the worst `solder_mask_bridge` counts, scored before
and after by the KiCad referee. This is the measurement that says whether the stage worked,
and it must run where the corpus lives.

## Risks

Routability. Raising pad clearances makes boards harder to route, and PR #25's 751-board
run showed both large gains and real regressions — though its packaging bundles nominal
clearance with the mask floors, so the mask work's own contribution is not isolated there.
Extracting the floors alone makes that attribution possible for the first time.

Two of the eleven worst boards — `8bit-cpu_programming_interface` and
`FRM16_Relay_Module_I2C_Controller_relay_controller` — are documented in PR #25 as artwork
boards whose mask reports come from copper lost during stripping, or from mask artwork
outside the pad model. Those are not router-caused and will not improve. The achievable
win is smaller than the raw counts suggest.

## Open decision

The branch base. This stage needs PR #22's representation, and #22 is a separate open pull
request. Rebasing onto it keeps history clean and avoids duplicating those fields across
two branches, at the cost of this branch inheriting #22's review surface and merge order.
Cherry-picking only the representation keeps this branch independently mergeable but
guarantees a conflict for whichever branch merges second.

## Out of scope

Detecting mask bridges in `copper-drc` — PR #22 does that, and this stage is enforcement.
Pad-to-pad mask webs, mask artwork, and unnetted pads, none of which a router can move.
Nominal clearance, smoothing and dogleg changes, which are independent of mask work
despite sharing a commit in PR #25.

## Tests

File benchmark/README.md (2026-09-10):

# Routing benchmarks

This suite answers two questions:

1. How does copperroute compare with the original Java freerouting router?
2. Does a proposed change improve routing relative to a pinned HEAD of this repository,
   without regressions on individual boards?

Candidates run as separate CLI processes on the same board inputs. A shared referee scores
connectivity, routing violations, wirelength and vias; the suite also measures process wall
time, CPU time and peak RSS. Use the same suite checkout, corpus, referee and machine for
both sides of a comparison.

## Setup

Run suite commands from `benchmark/`:

```bash
cd benchmark
uv sync
```

Build the Rust release binary and import KiCad reference boards:

```bash
cargo build --release --locked --manifest-path ../Cargo.toml
uv run bench corpus kicad-fixtures
uv run bench corpus list --tier kicad-fixtures
```

Java is optional as a router candidate. To compare it, build `./gradlew executableJar` in
`../../freerouting`. KiCad is the only DRC reference for all candidates.

Copy [.env.example](.env.example) to `.env` for machine-specific tool paths. Python and the
remote scripts load `benchmark/.env`; shell environment values take precedence. `{java}` in
candidate commands uses `FREEROUTING_JAVA`, otherwise a Gradle-downloaded JDK or `java` on PATH.
`FREEROUTING_JAR` does not rewrite candidate commands.

The manifest is tracked, but board input files, binaries and raw results are gitignored.
A fresh worktree needs corpus import or a copy of the corresponding inputs before routing.
Historical jars are optional: only candidates named by `--candidates` are loaded and checked.

## Compare Rust with Java freerouting

The default [candidates.toml](candidates.toml) provides `java-current` from the sibling Java
checkout and `rs-main` from this checkout's `target/release/copperroute`. `rs-main` is a label:
it runs the binary you built, not an automatic checkout of `main`.

```bash
uv run bench run --candidates java-current,rs-main --tier kicad-fixtures \
  --seeds 3 --threads 1 --jobs 1 --max-passes 100 --timeout 120 --run-id java-vs-rust
uv run bench compare --baseline java-current --against rs-main \
  --runs java-vs-rust --out java-vs-rust
```

Start with KiCad fixtures to check the pipeline, then repeat on a broader shared tier such as
`pcbench` with the same settings for both routers. Use a new run ID each time. Existing run
directories are never reused, so old sessions or metrics cannot leak into new measurements.

Record which Java revision or release you are comparing against. The candidate table also
contains historical releases and experimental Java variants; those are optional investigations,
not the default performance baseline. `sha_from` reads the checkout's HEAD at run time; it
cannot prove an existing binary was built from that commit. Build from a clean, pinned checkout
and keep it unchanged during the run. For a copied binary, set `sha` or `sha_file` explicitly.

[candidates.rs.toml](candidates.rs.toml) provides just Rust and a copied Java jar under
`binaries/`. [candidates.remote.toml](candidates.remote.toml) adds optional Java variants for
remote hosts. Both read the copied Java commit from `binaries/freerouting-current.sha`.

## Compare a change with current HEAD

Freeze HEAD **before starting the change**. If work has already started, choose its intended
baseline commit explicitly (usually the current `origin/main`). Run both binaries from one
suite checkout so they share the same corpus and scoring code.

From the Rust repository root, create and build a separate baseline worktree:

```bash
git worktree add --detach ../benchmark-head HEAD
cargo build --release --locked --manifest-path ../benchmark-head/Cargo.toml \
  --target-dir ../benchmark-head/target
```

Make and commit the proposed change in your development branch, then build it:

```bash
cargo build --release --locked --target-dir target
cd benchmark
```

Create `candidates.local.toml` in `benchmark/`:

```toml
[candidates.rs-head]
kind = "rust"
exec = ["../../benchmark-head/target/release/copperroute"]
sha_from = "../../benchmark-head"

[candidates.rs-change]
kind = "rust"
exec = ["../target/release/copperroute"]
sha_from = ".."
```

Use distinct candidate names and separate target directories. Do not rebuild one candidate's
binary with the other revision before both runs finish. Relative paths resolve against the
candidate TOML file's directory.

```bash
uv run bench run --candidates-file candidates.local.toml --candidates rs-head,rs-change \
  --tier kicad-fixtures --seeds 3 --threads 1 --jobs 1 --max-passes 100 --timeout 120 \
  --run-id head-vs-change
uv run bench compare --baseline rs-head --against rs-change --runs head-vs-change \
  --out head-vs-change --fail-on-regression
```

`--fail-on-regression` writes the reports first, then exits nonzero for routing-quality losses
(clean-pass rate, unrouted connections, violations or score), or if no boards can be compared,
naming each reason it rejected. `uv run bench pr-summary --compare head-vs-change` prints the
same outcome as a Markdown block to paste into the pull request.
Timing and RSS verdicts remain advisory by default. To gate those too, add
`--performance-regression-percent 10`: each side needs at least three measured repetitions,
and insufficient measured time/RSS samples also fail the gate. A performance loss must
exceed both the specified relative margin and three times the root-sum-square
of the two samples' standard deviations. This is a conservative noise allowance, not a
statistical significance guarantee; repeat borderline results under controlled conditions.

Comparisons use the intersection of the candidates' selected boards. Missing repetitions,
unjudged outputs and incompatible referees are reported explicitly; available comparable
measurements still contribute. Add `--require-complete` alongside `--fail-on-regression` when
every shared board and its planned repetitions must be present. A replacement run can complete
an interrupted plan under a new run ID; repeated plans are not added together as new obligations.
Boards selected by only one side are excluded and listed in coverage.

You can also compare separate run IDs with `--runs baseline-run,change-run`. Keep the candidate
names distinct across revisions. Never combine multiple commits under `rs-main`: the suite
rejects that ambiguity. Explicit run IDs avoid accidentally selecting an unrelated latest run.

## Reading results

`reports/<name>.json`, `.md` and `.html` contain candidate identities, settings, per-board
metrics, failures, warnings and aggregate verdicts. Per-board verdicts check, in order:

| Metric | Better direction |
|---|---|
| Clean-pass rate | Higher; connected with zero routing violations |
| Unrouted connections | Lower |
| Routing violations | Lower |
| Normalized routing score | Higher |
| Wall time, or CPU time for concurrent runs | Lower |
| Peak RSS | Lower |

The first difference outside twice the baseline's sample standard deviation decides the
verdict. The first three metrics are hard quality metrics; a loss on one prevents an overall
“better” verdict. `same` means differences did not decide a net win or loss under this rule;
it is not proof of equivalence. Per-board rows remain essential.

`--seeds` defaults to 1 **repetition**; use `--seeds 3` or more to estimate noise. By default no random-seed flag is sent to either router;
`{seed}` is available in candidate `extra_args` for a router that supports one. Below three
baseline measurements the suite uses a zero noise band. This is a noise heuristic, not a significance
test; short routes can be dominated by process/JVM startup. Repeating both candidates under
quiet, comparable conditions is necessary for timing claims.

Coverage is shown near the top of each report. A candidate with no comparable shared boards
gets `inconclusive`; otherwise aggregate verdicts describe the comparable subset. A candidate
that produces no session is scored as a routing failure. An output the referee cannot judge is
excluded from routing aggregates and listed in failures. `--no-referee` runs require
`bench referee` before comparison. The JSON `coverage` field includes shared, unmatched,
incomplete and skipped boards, with reasons for skipped comparisons.

Comparisons reject different thread counts, job counts, pass limits or timeouts unless
`--allow-mixed` is passed for exploratory analysis. Host differences produce a warning: network
hostnames can change on the same machine, so verify the physical hardware yourself. Repetition
count differences are reported, and each board's noise estimate uses its actual baseline
sample count, regardless of `--runs` order. Different commits/settings under one candidate
name remain an error: they cannot be pooled into one identity.

Cells judged by different referees or known Java referee jars are excluded for that board and
candidate pair, without discarding other boards. Re-score those outputs with one referee to
include them. Different score versions omit the score comparison but retain stored scores
for display and keep other metrics. Charts omit incomparable score pairs rather than drawing
them as zero.

For current-version metrics, comparison recomputes scores in memory using one shared denominator
per board: its positive manifest connection count, falling back to its positive manifest net
count. If neither exists, use the largest positive recorded `score_n` across the compared
cells, shared by both sides. If no positive denominator is available, retain the stored scores
for display and omit the score comparison. This avoids manufacturing zero scores for boards
with missing net counts. Candidate failures are charged the same shared connection count. Raw
metrics and exports retain their original scores; the compare JSON records `config.score_basis`
and each board's `score_n`. Historical manifest connection counts remain readable.
Keep the manifest fixed across comparisons and inspect connectivity,
violations, length and vias alongside the normalized score.

### Timing and parallelism

Use `--jobs 1 --threads 1` for controlled comparisons. `--threads` is passed to both routers
(the current Rust implementation does not use that setting to create workers);
`--jobs` controls how many candidate/board/repetition processes run concurrently. Time includes
process startup and the candidate's routing/optimization/output work, but excludes referee work.

With `--jobs > 1`, automatic comparison uses CPU time instead of wall time. CPU time still
changes with host load, cache contention and scheduling; it is not a correction for contention.
Time-limited routing may also produce different quality under contention. Keep host, jobs,
threads and budgets identical, and confirm claimed improvements with serial runs. You can force
`--time-metric wall` or `--time-metric cpu` for analysis.

## Corpus and referees

```bash
uv run bench corpus init
uv run bench corpus kicad-fixtures
uv run bench corpus pcbench --clone ~/PCBench --licensed-only --jobs 4
uv run bench corpus list --tier pcbench
```

`corpus init` imports the Java checkout's DSN fixtures. KiCad fixtures and PCBench imports
strip routing, export DSN inputs and measure the reference board. PCBench license metadata
is retained in the manifest; `--licensed-only` selects classified licensed sources. Review
individual license terms before sharing inputs. `--skip-existing` is the import default;
`--force` regenerates boards. Use `--ids` for PCBench directory names and `--boards` on `run`
for manifest board IDs; both accept comma-separated values.

Scored runs select only KiCad-backed boards by default. DSN-only fixtures can be routed with
`--no-referee` for diagnostics, but cannot be scored. Explicitly selecting them for scoring
produces an error before routing. Historical Java results remain readable, but cannot be
rescored with Java. KiCad boards use `kicad-cli pcb drc` after the
suite imports the session with `vendor/kicad/ses_to_board.py`. The referee preserves project
rules or reconstructs legacy rules, refills zones, and counts routing-related DRC errors.
KiCad failures remain unjudged; there is no automatic Java fallback. KiCad requires both
`kicad-cli` and a Python interpreter with `pcbnew`, configured through `.env` when necessary.

```bash
uv run bench referee --run head-vs-change --only-missing --jobs 1
uv run bench corpus revalidate --origin pcbench --regenerate-projects --rerun-drc --jobs 4
```

Full rescoring records an incomplete marker before starting and clears it only after all
cells are processed. Interrupted rescoring excludes the affected run from quality comparisons;
rerun without `--only-missing` to finish. Individual referee failures remain visible as
failed/unjudged cells even when the rescore attempt finishes. Rescoring does not require
candidate binaries or a candidates file. Legacy runs containing DSN-only cells must be kept
as historical records; scoring them is rejected before any results are modified.

Revalidation can change corpus membership and ground truth. Finish it before benchmarking and
keep the corpus fixed between candidates. Compare/export currently use the current manifest;
archive it along with inputs if a result needs to remain reproducible after corpus updates.
Candidate processes receive isolated HOME/XDG directories to prevent saved
router settings leaking between invocations. Their `JAVA_TOOL_OPTIONS` also includes
`-Djava.awt.headless=true -Dapple.awt.UIElement=true` to disable AWT windows and suppress
normal macOS GUI activation for Java candidates. Existing
`JAVA_TOOL_OPTIONS` are preserved; only subprocess environments are changed. Reports warn about results lacking isolation data.

## Reports, exports and history

```bash
uv run bench pr-summary --compare head-vs-change
uv run bench report --compare head-vs-change
uv run bench export --run head-vs-change --candidate rs-head
uv run bench export --run head-vs-change --candidate rs-change
uv run bench plot --files exports/BASELINE.json,exports/CHANGE.json --out reports/change.html
```

`compare` writes four files per comparison. `<name>.json` is the data, `<name>.md` the full
per-board report, `<name>.html` the report with charts and history, and `<name>.pr.md` a short
Markdown block for a pull request: the verdict, whether the regression gate passes, both
candidates' commits and settings, and the boards whose verdict is not a tie, capped and folded
into a `<details>` block. `pr-summary` prints that block to stdout so it can be piped to a
clipboard; `report` regenerates all three rendered files from the JSON.
[CONTRIBUTING.md](../CONTRIBUTING.md) describes the pull-request workflow that uses it.

Use the filenames printed by `export` in the last command. Exports contain compact per-board
measurements, candidate SHA, host and configuration; they are tracked and can be deliberately
committed. Raw `results/` and generated `reports/` remain local. To share a report, explicitly
add the chosen files with `git add -f reports/<name>.{json,md,html}` and retain the source run
and corpus elsewhere. Exports alone cannot reconstruct every raw cell or rerun the referee.

Existing baseline files and exports are fixed historical measurements, not an updating HEAD
baseline. New comparisons should pin and measure the intended baseline. The archive utility
`scripts/make-java-view.sh` can extract the specific Java result set it names from existing
local result data.

## Remote runs

The `scripts/remote-*.sh` helpers launch jobs on a configured NixOS host. See `.env.example`
for `BENCH_REMOTE_*` settings and each script's usage header. `remote-setup.sh HOST` prepares
the KiCad Python wrapper; `remote-corpus.sh` imports corpus data; `remote-run.sh` syncs the
suite and Java jar, launches a detached job, and pulls results back.

```bash
scripts/remote-setup.sh "$BENCH_REMOTE_HOST"
scripts/remote-run.sh "$BENCH_REMOTE_HOST" --remote-dir copperroute/benchmark --jobs 1 -- \
  --candidates java-current,rs-main --seeds 3 --threads 1 --tier kicad-fixtures \
  --max-passes 100 --timeout 120 --run-id remote-java-vs-rust
```

Provision the Rust repository and build its release binary **on the remote host** first.
These helpers sync the benchmark directory, not a Rust worktree or its build output. For branch
comparisons, build both pinned revisions there and provide a candidates file with remote paths
and known SHAs; `sha_from` only works when the referenced remote Git checkout exists. Keep each
worktree's remote directory separate. Local binaries may target a different architecture.

Remote run IDs cannot be reused, including completed or interrupted runs. Use a new ID for
a new measurement; the script refuses existing IDs before syncing and reserves launches
against concurrent reuse. A successful retrieval requires the remote job's recorded exit status.
`--no-wait` returns after launch; `remote-run.sh HOST --attach RUN_ID` resumes polling and result
retrieval. Corpus import does not pull all board files back automatically; copy the corpus
inputs separately if you need local routing or rescoring. Do not mix local and remote timings.

## Suite checks

```bash
uv run pytest -m 'not slow'
uv run pytest -m slow
```

The first command exercises the suite with synthetic router outputs. Slow tests require the
external Java/KiCad tools and provide integration checks. Neither replaces measuring actual
routing performance on the chosen corpus.

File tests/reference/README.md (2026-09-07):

# `tests/reference`

The committed outputs the test suites compare the crates against. Every file here was written
by this repository's own code, and every family is re-cut the same way:

```sh
COPPERROUTE_REGOLDEN=<label> cargo test -p <crate> --test <suite>
```

The label is free text; the run rewrites the family's files instead of comparing against them.
Inputs come from `tests/corpus`, whose layout the table files below name relative to it.

| family | files | table | cut by |
|---|---|---|---|
| DSN/SES writers | `<stem>/unrouted.ses` | `fixtures.txt` | `copper-dsn`'s `parity_ses` |
| per-connection routing | `router-<stem>/router.jsonl`, `router-steps18.jsonl` | `router-fixtures.txt` | `copper-router`'s `reference_parity` |
| whole-board routing | `router-<stem>/batch.ses`, `batch.passes.jsonl` | `router-fixtures.txt` | `copper-router`'s `batch_parity` |
| DRC reports | `drc-<stem>/drc.json` | `drc-fixtures.txt` | `copperroute`'s `cli_e2e` |
| the command line | `cli-<stem>/argv.txt`, `route.ses`, `route.exit`, `manifest.json` | `cli-fixtures.txt` | `copperroute`'s `cli_e2e` |
| KiCad's DRC | `<stem>/kicad-drc.json`, `kicad-drc.meta.txt` | `kicad-drc-fixtures.txt` | `scripts/gen-kicad-drc-reference.sh` |

The `<stem>/roundtrip.dsn` files are inputs to `copper-core`'s `stats` suite, not references.

The KiCad DRC family is the one oracle: `scripts/gen-kicad-drc-reference.sh` runs `kicad-cli pcb
drc` over each stem's board with the routed session imported, and `copper-drc`'s `kicad_oracle`
compares the checker's per-type counts against it. It needs a KiCad installation and is run by
hand.

Stems marked `slow` in `cli-fixtures.txt` and the `#[cfg_attr(debug_assertions, ignore)]` tests
run only under `COPPERROUTE_SLOW=1 cargo test --release`; re-cut those in release mode too.

`_scratch/` receives the actual output of a failed text comparison and is ignored by git.

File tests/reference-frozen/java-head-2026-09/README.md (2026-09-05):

# Reference outputs

> ## Plan 9 — these stop being *Java* reference outputs
>
> **Read this before regenerating anything.** Plans 1-8 cut every file under this directory from
> the Java jar, and byte parity with the jar was the port's acceptance test. **Plan 9 reverses
> that.** The port fixes 121 catalogued defects, byte parity with the jar may break wherever a fix
> lands, and the evidence moves from "the jar agrees" to "the port's own golden did not move
> unexplained, and the routing got better on 605 real boards". From Plan 9 Task 1 on, everything
> here is **regenerated from the port** and is the port's own golden.
>
> ### The freeze
>
> Before the first regeneration, Task 1 copies this whole tree, as it stands at the last
> jar-generated commit, to the **sibling** directory
>
> ```
> tests/reference-frozen/java-head-2026-09/
> ```
>
> — a sibling, never a child of `tests/reference/`, because a recursive copy of a directory into
> itself is not expressible and because a child would be swept up by every glob that walks this
> tree. The freeze is a **historical artefact, not a test input**: it is written once, made
> read-only, and **read by nothing** — no test, no script, and specifically not
> `scripts/quality-ab.sh` (ruling BL8, as amended by ruling BP1). The jar's quality numbers are
> derived from it **once**, at Task 1, and written *outside* it to
> `benchmark/baselines/quality-baseline-java-head.tsv`, where the A/B harness reads them as
> context and never as a gate. `grep -rn "reference-frozen" crates/ scripts/` must return nothing
> but prose for the whole of Plan 9, and `tests/reference-frozen/README.md` says so at the other
> end.
>
> ### The two generator lanes
>
> Each of the five generators now takes a lane:
>
> | flag | drives | what it is for |
> |---|---|---|
> | `--jar` (**the default**) | the jar, exactly as before | the frozen baseline, and **triage**: when a port-cut golden churns for a reason nobody can name, this answers "did the jar move, did the port move, or did the reference?" |
> | `--from-port` | the port — its CLI, or its own `p6t1` / `p7t9` / `refwriter` twin | what regenerates the committed references from Task 1 on |
>
> A `--from-port` run writes three provenance lines into the stem's `meta.txt`: **the port's git
> sha, the Plan 9 task at that sha, and the `RouterBudget` in force**. That line exists so that a
> golden cut *before* a later fix is **loudly** invalid — a reader who finds `plan 9 task UNKNOWN`,
> or a task number older than the fix they are chasing, knows the reference is stale without
> having to re-derive it. Cut a reference without `--task T<n>` and the file says so in capitals.
>
> `REFERENCE_OUT_ROOT` redirects a generator's **output** to a scratch tree while it still reads
> the fixture tables from here — which is how a lane is proved byte-unchanged without moving a
> committed byte.
>
> ### What does not change
>
> The stem lists, the `-mp` caps, the file names and the meaning of every artefact are unchanged;
> so is the rule below that **no generated file is ever edited by hand**. The `--jar` lane still
> produces exactly the bytes it produced before Plan 9 — Task 0 proved that by re-running it into
> a scratch tree and diffing, and the Task 0 report records what was compared and the two known
> non-deterministic fields (a `drc.json` `date` stamp and a `route.log` timestamp) that no lane
> can make reproducible.
>
> Everything below this box describes the **jar** lane and is still accurate for it.

# Java reference outputs

Generated by `scripts/gen-reference.sh` from the pinned freerouting 2.3.0 jar
(the parity baseline per the Java repo's AGENTS.md). For each stem in
`fixtures.txt` the script produces:

- `<stem>/roundtrip.dsn` — Java `DsnReader.readBoard` → `DsnWriter.write`, no routing
- `<stem>/unrouted.ses`  — same board → `SesWriter.write`, no routing (0 `(wire` entries)
- `<stem>/java.log`      — driver output, for debugging

## How it works (and why not `-de/-do`)

The script compiles `scripts/gen-reference/RefWriter.java` against the jar and
runs it per fixture. The normal `-de/-do` job path was tried first and cannot
produce these references:

- `-do <file>.dsn` is accepted but the headless job writer only emits SES or
  KiCad JSON, so the DSN output is an empty file.
- `-mp 0` means *unlimited* passes, not zero.
- `--router.enabled=false` disables only the autoroute stage; fanout and the
  optimizer still run and modify the board (fanout added vias/wires).
- With all three of `--router.enabled=false --router.fanout.enabled=false
  --router.optimizer.enabled=false` the job completes with nothing to do and
  writes 0 bytes.

## Which fixtures, and why

`fixtures.txt` has seven stems. The first four (`tutorial_board`,
`Issue026-J2_reference`, `Issue103-Board-Unrouted`, `Issue143-rpi_splitter`)
are the plan's original bit-parity set. Between them they have **zero**
`polyline_path`, zero wiring `(via `, zero `(type shove_fixed|fix|protect)`
and zero `(plane ` — so they prove the `structure`/`placement`/`library`/
`part_library`/`network` writers and nothing about six others. Plan 3
controller ruling G added three more in Task 15 to close that:

| stem | exercises | roundtrip.dsn | wires in .ses |
|---|---|---|---|
| `Issue413-test` | 11 `polyline_path`, 4 wiring vias, 3 fixed states | 8,492 B | 11 |
| `Issue110-RelayModule` | 22 wiring vias, 22 fixed states | 171,349 B | 0 |
| `Issue753-CPU-85_r104` | 3 `(plane …)`, 65 `polyline_path` | 273,049 B | 0 |

`Issue413-test` is the only reference whose `unrouted.ses` carries `(wire`
entries, so it is the one that pins `SesWriter`'s trace path. The other six are
wire-free. Both halves of that are asserted: `parity_ses.rs`'s
`no_reference_contains_a_wire` runs over all six wire-free stems (the ruling-G
ones included) and `ruling_g_references_do_carry_wires` pins `Issue413-test`'s
11 entries.

**Never edit a generated file by hand** — regenerate with the script. Adding a
stem to `fixtures.txt` and re-running is the whole procedure; the script is
idempotent for the stems already present (only `java.log`'s timestamp changes).

Note the 2.3.0 jar's package layout predates the clone's renames
(`app.freerouting.board.BasicBoard`, not `board.facade`); the driver imports
the jar's names.

## Why the 2.3.0 jar, not the clone's HEAD (Plan 3 ruling 1)

The clone's HEAD camelCased fifteen Specctra keyword names in `Keyword.java`
*and* the writers' string literals (`(hostCad `, `(viaRule `, `(snapAngle `,
`(stringQuote `, ...), while its lexer still only recognises the snake_case
tokens -- so HEAD writes DSN it cannot read back (re-reading its own
`tutorial_board` output drops `host_cad`, every via rule, every clearance rule
and 26 wires). The 2.3.0 jar writes the correct Specctra tokens, and diffing
HEAD's output against these references differs in exactly those fifteen tokens
and nothing else on every fixture. The port therefore emits the 2.3.0 tokens,
these references are the acceptance target, and `docs/java-quirks.md` #92 is
the upstream bug report. Regenerating with a HEAD jar would silently move the
target; do not.

Reference files are committed. `_scratch/` holds the Rust side of a failing
comparison and is gitignored, as is `scripts/gen-reference/build/`.

Requirements: JDK 25 (`brew install openjdk@25`, then
`JAVA=/opt/homebrew/opt/openjdk@25/bin/java scripts/gen-reference.sh`), network
access on first run to download the jar into `tools/`.

---

# DRC references (`drc-*`, Plan 5 Task 9)

The seven stems above are `scripts/gen-reference.sh`'s. The eight `drc-*` stems are a **separate
set**, generated by `scripts/gen-drc-reference.sh` from a **different jar**, and listed in
`drc-fixtures.txt` (`stem|dsn|rules|ses`) rather than in `fixtures.txt`. Per stem:

- `<stem>/drc.json`     — the `-drc` CLI's report, **verbatim**
- `<stem>/drc.meta.txt` — the jar's identity (size, mtime, version), `java -version`, the hash
                          mode and the command line. Every machine-specific prefix is written as
                          `<FREEROUTING_JAVA_DIR>` or `<workspace>`, so the file is byte-identical
                          wherever it is regenerated. `scripts/gen-drc-reference.sh --meta-only`
                          rewrites it from the existing `drc.json` without running the jar, for
                          when this file's format changes and the references must not move
- `<stem>/java.log`     — the CLI's stdout+stderr. **Unlike the other two it is machine-specific**:
                          it carries absolute paths and wall-clock timestamps, exactly as
                          `gen-reference.sh`'s `java.log`s do. It is kept for debugging and read by
                          nothing, so a diff in it means nothing

## Why a second script and a second jar

`gen-reference.sh` is pinned to the downloaded **2.3.0** jar because the `io/specctra` byte-parity
references have to be 2.3.0's (Plan 3 ruling 10, "Why the 2.3.0 jar" above). The DRC references
have to be the clone's **HEAD** build: Plan 5 ports HEAD's `drc/**` and `io/kicad/KiCadDrc*.java`,
every file:line in that plan is HEAD's, and the two jars disagree about the report's key spelling
(HEAD writes `coordinateUnits`/`holeClearance`, 2.3.0 writes `coordinate_units`/`hole_clearance` —
plan-5 rulings 1 and 2). Putting two jars behind one `fixtures.txt` would hide that skew, so the
DRC set gets its own file, its own script and its own `drc-` stem prefix.

Unlike the DSN/SES case, no Java driver has to be compiled: `-drc` works from the CLI as-is, for a
plain DSN, for a DSN + `.rules` (`-dr`) and for a DSN + `.ses`. Driving the real CLI is also what
puts a real `qualityScore` in the reference — `DesignRulesChecker` alone never computes it
(`Freerouting.java:343-352`; plan-5 ruling 5 makes it an injected `Option<f64>` in the port, and
`crates/fr-drc/tests/reference_parity.rs` feeds the reference's own value back in).

**There is no `-ds` flag.** The session file has no option of its own: `GlobalSettings` collects
every non-`-` argument after `-de` into a slot list and sorts them by extension
(`GlobalSettings.java:564-648`), so the DSN and the SES are simply two arguments in the `-de` slot.
A single `<dsn>+<ses>` argument reaches the same list through the `+`-split at `:573-579`; the
generator uses the two-argument form, which needs no split and survives a path containing `+`.
(Verified equivalent: both forms produce a `drc-issue593-ses` report byte-identical to the
committed one apart from `date`.) `-drc` is matched by `startsWith` *before* `-dr` in the same
if-chain (`:660-674`), so the two flags cannot be confused whatever their order on the command
line.

## The eight stems, as measured on the HEAD jar

| stem | input(s) | violations (breakdown) | unconnectedItems | qualityScore |
|---|---|---|---|---|
| `drc-dev-board` | `Issue575-drc_dev-board_4_hole_clearance_violations.dsn` | 10 (2 holeClearance, 8 track_dangling) | 4 | 902.078369140625 |
| `drc-bbd-mars-64` | `Issue575-drc_BBD_Mars-64_6_track_1_hole_clearance_violations.dsn` | 96 (64 holeClearance, 12 clearance, 18 via_dangling, 2 track_dangling) | 3 | 828.276123046875 |
| `drc-natural-tone-preamp` | `Issue575-drc_Natural_Tone_Preamp_7_unconnected_items.dsn` | **115** (111 track_dangling, 4 via_dangling) | 44 | 334.8545227050781 |
| `drc-issue593-rules` | `Issue593-BBD_Mars-64.dsn` + `.rules` via `-dr` | 0 | 74 | 0.0 |
| `drc-issue593-ses` | `Issue593-BBD_Mars-64.dsn` + `.ses` via the `-de` slot | 13 (1 track_dangling, 12 via_dangling) | 45 | 556.5908203125 |
| `drc-issue753-cpu85` | `Issue753-CPU-85_r104.dsn` | 107 (78 holeClearance, 16 track_dangling, 13 via_dangling) | 169 | 331.1068115234375 |
| `drc-issue110-relay` | `Issue110-RelayModule.dsn` | 26 (4 holeClearance, 22 via_dangling) | 44 | 0.0 |
| `drc-tutorial-board` | `examples/tutorial_board/tutorial_board.dsn` | 0 | 0 | 0.0 |

Between them the set covers all five `type` strings (`clearance` only ever appears in
`drc-bbd-mars-64`), the `-dr` path, the session path, one wholly empty report
(`drc-tutorial-board`, 0/0 — `drc-issue593-rules` has no violations but 74 unconnected entries),
three `qualityScore`s of exactly `0.0` and five non-trivial ones.

## The hash-mode sweep, and the one stem that fails it

`scripts/gen-drc-reference.sh --verify-hash-modes` regenerates every stem once per
`-XX:+UnlockExperimentalVMOptions -XX:hashCode=0,1,2,3,4` and reports how many distinct
**normalised** documents (`scripts/normalize-drc.py`) come out. Agreement is what makes a
reference a property of the board rather than of the JVM run that produced it. Result on the jar
named in `drc.meta.txt`:

| stem | distinct normalised documents over the five modes |
|---|---|
| `drc-dev-board`, `drc-bbd-mars-64`, `drc-issue593-rules`, `drc-issue593-ses`, `drc-issue753-cpu85`, `drc-issue110-relay`, `drc-tutorial-board` | **1** |
| `drc-natural-tone-preamp` | **5** |

`drc-natural-tone-preamp` is recorded, not papered over. `generateReport` folds
`getAllUnconnectedItems`' `track_dangling` entries into `violations`
(`DesignRulesChecker.java:271-276`), and that phase's dedup (`:160`) drops whichever dangling trace
a net entry's hash-ordered `firstItem` happens to be — a representative-dependent result
(`findRepresentativeItem`, plan-5 ruling 3; quirk #146).

**Its violation count lands in the range 113-115, and only `-XX:hashCode=2` pins it.** Mode 2 is a
constant, so it is the one `Object.hashCode` source that reproduces run to run without being
derived from an object address; it gives **115**, and that is the committed reference. Modes 0 and
5 are PRNG-seeded and modes 1 and 4 are address-derived, so their counts move between sweeps — two
independent sweeps of this same jar agreed on mode 2 and disagreed with each other on modes 0 and 4
— and mode 3 is a per-thread xorshift, deterministic only within a single-threaded run. **No
per-mode count should be quoted for those four**; the honest statement is the range plus mode 2's
value. Three independent sweeps of this jar have now been taken (Task 9's, the reviewer's and a
re-run): every one of modes 0, 1, 3 and 4 produced a different count in at least one of them, and
mode 2 produced 115 in all three. `crates/fr-drc/tests/data/README.md` records the same finding
from Tasks 4, 7 and 8.

**All eight references are therefore generated under `-XX:hashCode=2`.** For the seven
hash-independent stems the flag changes nothing; for this one it is what makes the reference
reproducible at all. `references_are_from_the_head_jar` asserts every `drc.meta.txt` says so.

The port's own answer on that fixture is 112 violations — its ascending-id representatives make
three of the fixture's four `Trace`-represented net entries dangling — and
`natural_tone_preamp_is_the_reference_minus_three_dangling_tracks` requires the port's document to
be this reference with exactly the three `track_dangling` entries whose item uuids are `1909`,
`1696` and `1242` deleted **in place**, pinned by uuid rather than by count. The other 44
`unconnectedItems` entries and the remaining 112 violations are byte-identical.

## The normalisation is three lines long, on purpose

`parity::normalize_drc_json` drops `date` (`ZonedDateTime.now()`, `KiCadDrcReport.java:70`, an
injected string in the port) and sorts each `unconnectedItems` entry's `items` by **numeric** uuid
(on the JVM that array is two `HashSet<Item>`s, quirk #144). It does **not** touch `violations` —
neither the array order nor any entry's `items`, because a clearance entry's `items` is
`[firstItem, secondItem]` in a deterministic order and sorting it would hide a real ordering
regression. `scripts/normalize-drc.py` is the Python twin, used by `--verify-hash-modes` only; it
is deliberately not on the path of any committed byte, which is why the committed `drc.json` is the
jar's own output and the Rust normaliser is applied to *both* sides inside the test.

## The `*-freerouting_drc.json` files in the Java fixtures directory are NOT references

`../freerouting/fixtures/Issue575-*-freerouting_drc.json` look like DRC references and are not
(plan-5 ruling 10). Verified while writing this task:

- they are `Freerouting 2.1.2-SNAPSHOT`-era and carry **no `quality_score`** key at all;
- they are snake_case, i.e. neither jar's current output for two of the type strings;
- the dev-board one claims **5 violations / 1 unconnected item** where both current jars produce
  **10 / 4**; the BBD Mars-64 one claims 93 / 0 against 96 / 3, and the Natural Tone Preamp one
  28 / 9 against 113-115 / 44.

The `*-kicad_drc.json` files beside them are KiCad 9.0.1's own output and are the evidence for
ruling 2's `DrcJsonFlavor::KiCad` spelling, not a parity target either.

**Never edit a generated file by hand** — regenerate with
`scripts/gen-drc-reference.sh [stem ...]`. The one thing that changes on every regeneration is
`date` (and `java.log`'s timestamps); the parity test drops it on both sides.

---

# Router references (`router-*`, Plan 6 Task 17)

`tests/reference/router-<stem>/router.jsonl` is one JSON line per **routed
connection** — the third reference family in this directory, and the first that
is neither a whole file the jar wrote (`fixtures.txt`'s DSN/SES round trips) nor
a report it generated (`drc-fixtures.txt`'s `-drc` documents).

`scripts/gen-router-reference.sh` writes them from
`tests/reference/router-fixtures.txt` (`stem|dsn|max_items|ripup_pass_no`, paths
relative to the Java checkout; Plan 7 Task 16 made fields 3 and 4
mandatory-or-`-` and appended three batch columns at 5-7, which this script does
not read) and `crates/fr-router/tests/reference_parity.rs` reads the same table,
so the generator and the tests cannot drift apart. A row with `-` in `max_items`
is a batch-only row and this generator skips it.

## A third script, and the HEAD jar again

Like `gen-drc-reference.sh` this one is pinned to the clone's **HEAD** build, not
to the 2.3.0 jar the DSN/SES references need: HEAD's `autoroute/**` has been
refactored away from upstream (`MazeSearchAlgo` → `maze/MazeSearchEngine`,
`LocateFoundConnectionAlgo*` → `path/FoundConnectionLocator*`, and
`MazeExpansionEngine`/`MazeRipupResolver`/`AutorouteConnectionRouter` do not
exist there at all), so a 2.3.0 reference would be a *different algorithm*.

Unlike the DRC generator it cannot drive the CLI: the CLI runs the whole pipeline
(fanout, passes, the optimizer) and plan-6 ruling 2 cuts the port at step 5 of
`AutorouteConnectionRouter.route`. So it compiles and runs
`scripts/differential/java/P6T1.java` — the same driver
`scripts/differential/run.sh p6t1` diffs live against the Rust twin.

Per stem: `router.jsonl` (the driver's stdout **verbatim**, minus its `HEADER`
line), `java.log` (its stderr) and `router.meta.txt` (the jar's identity and
version, `java -version`, the hash mode, the driver path, the connection count,
the command line and the `HEADER` line, every machine-specific prefix replaced by
`<FREEROUTING_JAVA_DIR>` or `<workspace>`). The `HEADER` line is the one thing
not committed as-is: it names the jar by absolute path, byte size and mtime,
which are properties of a checkout rather than of a board.
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

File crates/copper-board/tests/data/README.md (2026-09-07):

# `copper-board` test data

The transcripts here are expected-value tables for
`crates/copper-board/tests/clearance_violations.rs`: for every item of the dev board, each
clearance violation's `(firstItem, secondItem, layer, expectedClearance, actualClearance)`, the
aggregated list sorted by severity, the smallest clearance, and seven synthetic box pairs for the
bisection. Doubles are printed the way `copper_dsn::format::double::format_double` prints them,
so the comparison is exact.

`copper-board` cannot read a `.dsn` itself (the dependency runs the other way), so the
whole-board rows are checked one crate up.

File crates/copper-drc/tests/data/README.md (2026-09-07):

# `copper-drc` test data

Expected-value transcripts for this crate's integration suites, one family per suffix:

| suffix | read by | rows |
|---|---|---|
| `.list.txt` | `checks.rs` | the deduplicated clearance-violation list in walk order, every field |
| `.unconnected.txt` | `unconnected.rs` | the unconnected-items list, projected to what is order-independent |
| `.netincompletes.txt`, `.airlines.txt`, `.airlines-union.txt` | `net_incompletes.rs` | per-net incompletes and the airline endpoints |
| `.incompletes.txt` | `incompletes.rs` | the incompletes counters and the clearance block of the board statistics |
| `.report.txt` | `report.rs` | the report as normalised text |
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

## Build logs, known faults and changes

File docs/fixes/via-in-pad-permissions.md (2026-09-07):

# Via-in-pad permissions

KiCad board JSON uses an explicit opt-in for newly routed vias to share SMD pad
copper. Add `"viaInPadAllowed": true` to the top-level board object to allow this.
An absent or false field disallows attachment. Each entry in `netClasses` can
override the board value with its own `viaInPadAllowed` boolean.

For example, merge these properties into a complete KiCad board JSON:

```json
{
  "viaInPadAllowed": false,
  "netClasses": [
    { "name": "Default" },
    { "name": "DenseBGA", "viaInPadAllowed": true }
  ]
}
```

This keeps attachment off for Default and allows it for nets assigned to
DenseBGA. Preserve the other board and net-class properties when editing an
export. These are extensions to the Rust JSON bridge; KiCad exporters may omit
them. They are not imported from a .kicad_pro project.

CLI users can edit the JSON before running
`copperroute route board.json -o routed.json`. MCP users can route the same
edited JSON through `route_board`. There is no separate CLI permission flag.
The browser integration supplies the top-level value from its checkbox.

The importer sets each via template's attachment permission and enables
`BoardRules.strict_smd_via_attachment`. Maze search and final insertion respect
the template permissions. `smd_via_relaxation` still discounts pure-SMD via costs
but does not override these KiCad permissions. Imported existing vias are
preserved in place.

DSN imports retain their established behavior: via rules carry the
`via_at_smd`/padstack permissions, and `smd_via_relaxation` additionally relaxes
the legacy pure-SMD search gate. That search relaxation is separate from the
per-via insertion masks. Disabling the setting removes the search relaxation
and cost discount, without revoking explicitly allowed via rules.

KiCad JSON export takes each class's permission from the same first via in its
effective net-class rule used for its exported via diameter and drill. It does
not use the separately stored via catalogue. The default class supplies the
top-level permission and differing classes carry overrides. Mixed class
permissions therefore survive a JSON round trip. The JSON format represents
one via template per class; additional DSN via templates are not representable.
DSN and SES output retain their native via rules and attachment controls.

Disallowing via-in-pad can require more routing space and leave connections
unrouted on dense boards.

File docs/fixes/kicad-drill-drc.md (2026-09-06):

# KiCad drill metadata and clearance measurements

## Import and routing rules

Padstacks carry optional drill diameters in board units, a drill-approximation
flag and a hole-only flag. KiCad JSON imports populate these for pads, existing
vias, session vias and net-class via templates. Padstack sharing includes drill
diameter, plating and approximation status. The writer exports explicit via
drills. Inputs without drill metadata use padstack-name heuristics or estimated
diameters. The JSON pad extensions `nonPlated` and `drillEstimated` default to
false. Non-plated holes are exempt from annular-ring checks.

Project import attaches DRC constraints after board preparation. Board
preparation and pipeline entry floor routing hole clearance and board-edge
clearance at the project minima, converting to board units. Larger explicit
routing clearances are preserved, and search trees are rebuilt when a minimum
raises a value.

## Hole-clearance geometry

Hole-to-hole DRC measures center distance minus the two drill radii.
Hole-to-copper DRC measures circular pad/via copper, trace centerlines plus half
width, and placed rectangular or rounded pad copper. Both directions of a
pad/hole pair are checked. Same-net and same-logical-pad exclusions apply; there
is no general same-footprint exemption. Bare holes participate in hole checks
but have no copper for copper-clearance or copper-edge checks. Real overlap is
reported even when the required clearance is zero.

KiCad JSON accepts `shape: "roundrect"` with an optional `roundRectRatio` between
zero and one half. When present, the ratio and positive finite pad dimensions
are validated. When absent, the pad retains the legacy rectangular
representation. Corner-radius metadata participates in padstack identity.

Rounded-corner measurements use the nearest point on an inset convex tile plus
the corner radius. This supports axis-aligned, 45-degree and arbitrary pad
rotations. If the inset cannot supply a nearest point, measurement falls back to
the enclosing polygon; the pad/hole pair is still checked. Coordinates are
rounded to board units. Trace measurements use the geometry crate's polyline
nearest-point implementation and run once per ordered copper/hole/layer tuple,
even if several segment tiles encounter the same hole. Violation markers are
clamped to the interval between the hole center and nearest geometry point.

## Limits

Routing and non-hole DRC use enclosing rectangles for rounded pads.
Oval copper remains a circumscribing octagon, so hole-to-oval gaps can be
underestimated near the curved ends. General polygonal pad geometry is measured
as imported. Slotted holes and drills marked estimated retain their
approximations. These limits mean that not every DRC measurement represents an
exact physical copper outline.

Via-in-pad attachment permissions are independent of these measurements.
Browser format translation, UI behavior and zone refilling are outside these
native checks.

## Regression coverage

Tests cover distinct padstack drill/radius identities, via drill export, legacy
roundrect payloads without radius metadata, invalid explicit radii, circular
hole spacing, trace clearance, both item orders, both board sides, rotations
including 45 and 135 degrees, zero-clearance overlap and project routing minima.

Analytical USB connector examples with a 0.25 mm requirement give these gaps:

| Pad geometry | GND gap (mm) | Vbus gap (mm) |
| --- | ---: | ---: |
| Rectangle (Uno) | 0.1751 | 0.2099 |
| Rounded rectangle (Nano) | 0.1944 | 0.2586 |

With the duplicated pad definitions in those footprints, these measurements
correspond to eight Uno and four Nano findings. They describe the imported
footprints, independently of any routed tracks or vias.

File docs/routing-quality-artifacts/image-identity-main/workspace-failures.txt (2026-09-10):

---- the_p8t3_transcript_replays_cell_for_cell stdout ----

thread 'the_p8t3_transcript_replays_cell_for_cell' (4304168) panicked at crates/copper-core/tests/overrides.rs:443:17:
assertion `left == right` failed: issue593-bbd-mars-64 0 stage after_parser: the port's board disagrees with the jar's
--- port ---
[stage] name=after_parser
  layers=2 classes=3 names=null,default,smd
  outline_class=1 default_area_class=1 hole_clearance=0 items=961
  keepouts=8 keepout_classes=1:8
  reclassified=
  tree_leaves=216 entry_id=0
  tree_order digest=558f83db7f9fe53b head=1:0,1:4,1:1,1:5,1:2,76:0,78:0,80:0,82:0,84:0,86:0,77:0 tail=222:0,258:0,294:0,321:0,681:0,958:0,959:0,908:0,934:0,909:0,935:0,1:7
  matrix_sum=13000
  msum L0 = 6500 rows=0,4000,2500
  msum L1 = 6500 rows=0,4000,2500
  mrow L0 0 null = 0 0 0
  mrow L0 1 default = 0 2000 2000
  mrow L0 2 smd = 0 2000 500
  mrow L1 0 null = 0 0 0
  mrow L1 1 default = 0 2000 2000
  mrow L1 2 smd = 0 2000 500

--- jar ---
[stage] name=after_parser
  layers=2 classes=3 names=null,default,smd
  outline_class=1 default_area_class=1 hole_clearance=0 items=961
  keepouts=8 keepout_classes=1:8
  reclassified=
  tree_leaves=216 entry_id=0
  tree_order digest=51459a519bd57b53 head=1:0,1:4,1:1,1:5,1:2,76:0,78:0,80:0,82:0,84:0,86:0,77:0 tail=222:0,258:0,294:0,321:0,681:0,958:0,959:0,908:0,935:0,909:0,934:0,1:7
  matrix_sum=13000
  msum L0 = 6500 rows=0,4000,2500
  msum L1 = 6500 rows=0,4000,2500
  mrow L0 0 null = 0 0 0
  mrow L0 1 default = 0 2000 2000
  mrow L0 2 smd = 0 2000 500
  mrow L1 0 null = 0 0 0
  mrow L1 1 default = 0 2000 2000
  mrow L1 2 smd = 0 2000 500

  left: "[stage] name=after_parser\n  layers=2 classes=3 names=null,default,smd\n  outline_class=1 default_area_class=1 hole_clearance=0 items=961\n  keepouts=8 keepout_classes=1:8\n  reclassified=\n  tree_leaves=216 entry_id=0\n  tree_order digest=558f83db7f9fe53b head=1:0,1:4,1:1,1:5,1:2,76:0,78:0,80:0,82:0,84:0,86:0,77:0 tail=222:0,258:0,294:0,321:0,681:0,958:0,959:0,908:0,934:0,909:0,935:0,1:7\n  matrix_sum=13000\n  msum L0 = 6500 rows=0,4000,2500\n  msum L1 = 6500 rows=0,4000,2500\n  mrow L0 0 null = 0 0 0\n  mrow L0 1 default = 0 2000 2000\n  mrow L0 2 smd = 0 2000 500\n  mrow L1 0 null = 0 0 0\n  mrow L1 1 default = 0 2000 2000\n  mrow L1 2 smd = 0 2000 500"
 right: "[stage] name=after_parser\n  layers=2 classes=3 names=null,default,smd\n  outline_class=1 default_area_class=1 hole_clearance=0 items=961\n  keepouts=8 keepout_classes=1:8\n  reclassified=\n  tree_leaves=216 entry_id=0\n  tree_order digest=51459a519bd57b53 head=1:0,1:4,1:1,1:5,1:2,76:0,78:0,80:0,82:0,84:0,86:0,77:0 tail=222:0,258:0,294:0,321:0,681:0,958:0,959:0,908:0,935:0,909:0,934:0,1:7\n  matrix_sum=13000\n  msum L0 = 6500 rows=0,4000,2500\n  msum L1 = 6500 rows=0,4000,2500\n  mrow L0 0 null = 0 0 0\n  mrow L0 1 default = 0 2000 2000\n  mrow L0 2 smd = 0 2000 500\n  mrow L1 0 null = 0 0 0\n  mrow L1 1 default = 0 2000 2000\n  mrow L1 2 smd = 0 2000 500"
note: run with `RUST_BACKTRACE=1` environment variable to display a backtrace

---- every_port_airline_is_one_some_jvm_run_picks stdout ----
Issue575-drc_dev-board_4_hole_clearance_violations: all 9 port airlines are in the six-run JVM union

thread 'every_port_airline_is_one_some_jvm_run_picks' (4305585) panicked at crates/copper-drc/tests/net_incompletes.rs:184:17:
Issue575-drc_BBD_Mars-64_6_track_1_hole_clearance_violations: airline (4, 909, 935) was picked by none of the six JVM runs
note: run with `RUST_BACKTRACE=1` environment variable to display a backtrace

---- the_three_fixtures_match_the_jvm stdout ----

thread 'the_three_fixtures_match_the_jvm' (4305754) panicked at crates/copper-drc/tests/unconnected.rs:102:9:
assertion `left == right` failed: Issue575-drc_BBD_Mars-64_6_track_1_hole_clearance_violations.dsn
  left: "unconnectedItems 3\nnet=1 first=Pin second=Pin items=13,87,792,873,962,963,964,965,966,967,1192,1193,1194\nnet=4 first=Pin second=Pin items=4,5,78,79,766,798,867,909,922,935,986,987,988,989,990,991,992,993,994,995,996,997,998,999,1000,1001,1002,1200,1201\nnet=7 first=Pin second=Pin items=8,726,818,1030,1031,1032,1033,1034,1035,1205,1206,1207\ntrack_dangling_candidates 2\nfirst=1031\nfirst=998\nvia_dangling 18\nfirst=1289\nfirst=1287\nfirst=1266\nfirst=1264\nfirst=1262\nfirst=1257\nfirst=1255\nfirst=1252\nfirst=1242\nfirst=1233\nfirst=1226\nfirst=1222\nfirst=1220\nfirst=1215\nfirst=1213\nfirst=1211\nfirst=1204\nfirst=1194\n"
 right: "unconnectedItems 3\nnet=1 first=Pin second=Pin items=13,87,792,858,962,963,964,965,966,967,1192,1193,1194\nnet=4 first=Pin second=Pin items=4,5,78,79,766,798,864,909,922,934,986,987,988,989,990,991,992,993,994,995,996,997,998,999,1000,1001,1002,1200,1201\nnet=7 first=Pin second=Pin items=8,726,818,1030,1031,1032,1033,1034,1035,1205,1206,1207\ntrack_dangling_candidates 2\nfirst=1031\nfirst=998\nvia_dangling 18\nfirst=1289\nfirst=1287\nfirst=1266\nfirst=1264\nfirst=1262\nfirst=1257\nfirst=1255\nfirst=1252\nfirst=1242\nfirst=1233\nfirst=1226\nfirst=1222\nfirst=1220\nfirst=1215\nfirst=1213\nfirst=1211\nfirst=1204\nfirst=1194\n"
note: run with `RUST_BACKTRACE=1` environment variable to display a backtrace

---- issue110_relay_module_wiring_matches_javas_vias stdout ----

thread 'issue110_relay_module_wiring_matches_javas_vias' (4305862) panicked at crates/copper-dsn/tests/common/mod.rs:243:9:
assertion `left == right` failed: Issue110-RelayModule-items.txt: line 47 differs
  left: "item 46 ComponentOutline layer=0 courtyard=false cmp=4 cl=0 nets=[]"
 right: "item 46 ComponentOutline layer=0 courtyard=true cmp=4 cl=0 nets=[]"
note: run with `RUST_BACKTRACE=1` environment variable to display a backtrace

---- every_reference_is_byte_for_byte_identical stdout ----

thread 'every_reference_is_byte_for_byte_identical' (4306564) panicked at crates/copper-dsn/tests/parity_ses.rs:145:9:
Issue110-RelayModule: not byte-identical to /Users/em/Development/freerouting/copperroute-image-identity-main/tests/reference/Issue110-RelayModule/unrouted.ses
line 11:
  actual   "    )"
  expected "      (place K2 1220000 -2040000 front 180)"
note: run with `RUST_BACKTRACE=1` environment variable to display a backtrace

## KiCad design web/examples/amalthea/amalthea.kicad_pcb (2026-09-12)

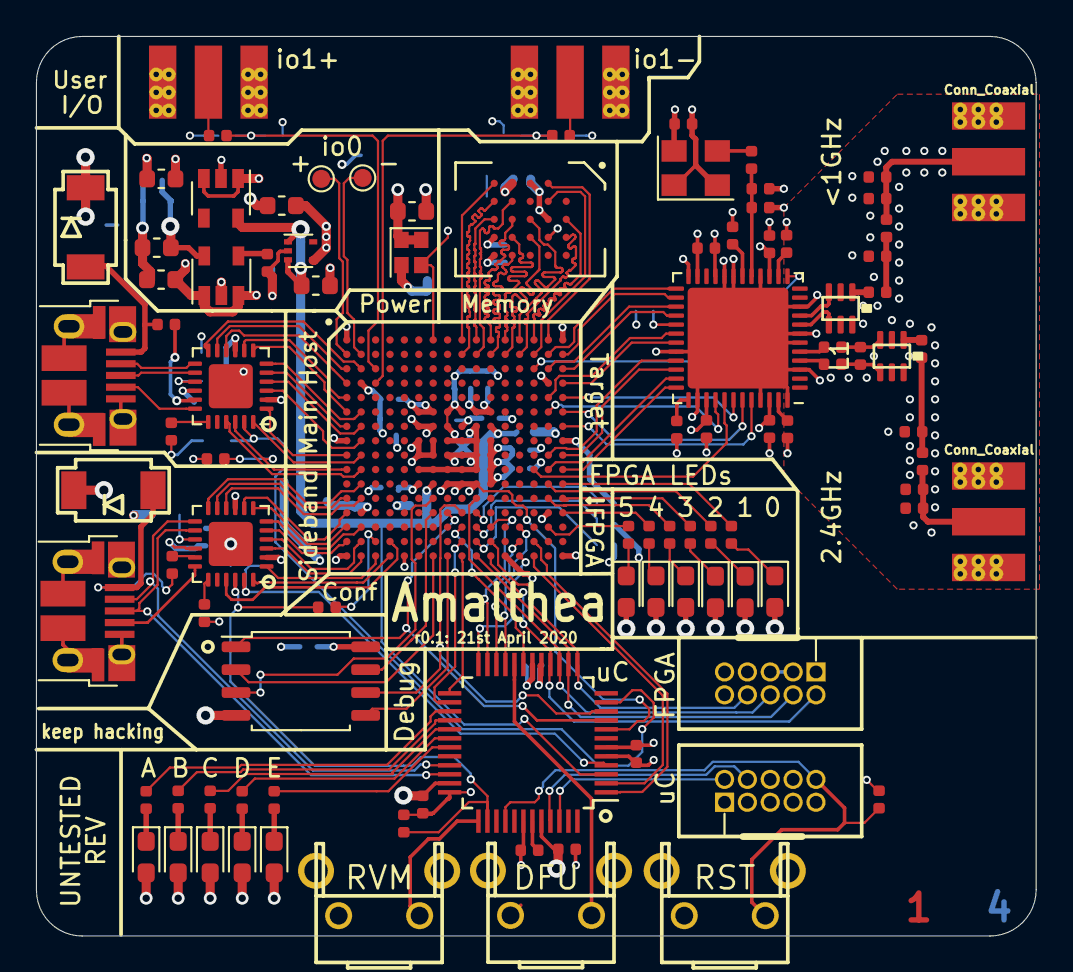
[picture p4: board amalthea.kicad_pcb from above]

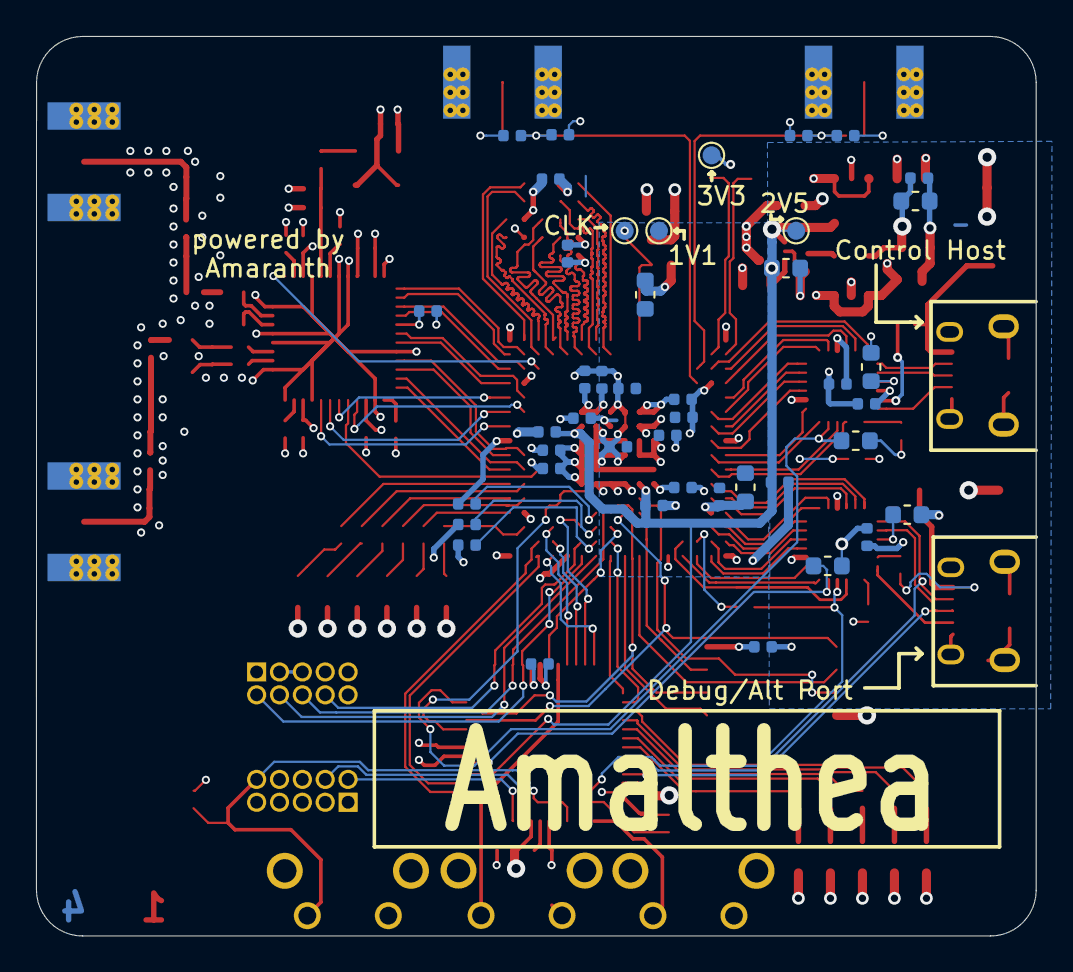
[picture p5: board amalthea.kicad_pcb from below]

Board: 4 copper layers, 55.5 x 50.0 mm, 140 parts (43 on the bottom side), 153 nets.

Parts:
C1, C2, C3, C4, C6, C20: 2.2uF; C_0603_1608Metric
C7, C8, C9, C10, C11, C12, C13, C14, C15, C16, C17, C18, C23, C24, C25, C26, C27, C31, C32, C33, C34, C35, C38, C39, C47, C49, C51, C57, C60, C61, C62, C63, C64: 0.1uF; C_0402_1005Metric
C21, C44, C45, C54, C55, C65: C; C_0402_1005Metric
C22, C28, C29, C30, C36, C37, C48, C50: 1uF; C_0603_1608Metric
C40, C41, C59: 1uF; C_0402_1005Metric
C42, C46: 1.8pF; C_0402_1005Metric
C43: 0.8pF; C_0402_1005Metric
C52: 470pF; C_0402_1005Metric
C53: 15pF; C_0402_1005Metric
C56: 1nF; C_0402_1005Metric
C58: 10pF; C_0402_1005Metric
D1, D8: PMEG3050EP,115; SOD128
D2: RED; LED_0603_1608Metric_Pad1.05x0.95mm_HandSolder
D3: ORANGE; LED_0603_1608Metric_Pad1.05x0.95mm_HandSolder
D4: YELLOW; LED_0603_1608Metric_Pad1.05x0.95mm_HandSolder
D5: GREEN; LED_0603_1608Metric_Pad1.05x0.95mm_HandSolder
D6, D10, D14: BLUE; LED_0603_1608Metric_Pad1.05x0.95mm_HandSolder
D7: PURPLE; LED_0603_1608Metric_Pad1.05x0.95mm_HandSolder
D11, D13: PINK; LED_0603_1608Metric_Pad1.05x0.95mm_HandSolder
D12: WHITE; LED_0603_1608Metric_Pad1.05x0.95mm_HandSolder
IC1: ECP5-BGA256; lattice_cabga256
J1, J2: USB_B_Micro; USB_Micro-B_Amphenol_10103594-0001LF_Horizontal
J3, J4, J8, J9: Conn_Coaxial; SMA-EDGE
J5, J6: Conn_ARM_JTAG_SWD_10; SWD_CONNECTOR_LARGE_BOX
L1: 5.6nH; L_0402_1005Metric
R1, R3: 0R; R_0402_1005Metric
R2, R4, R5, R12, R13, R14, R24, R25: 10k; R_0402_1005Metric
R6: 100k; R_0402_1005Metric
R7, R8, R9, R10, R11, R26, R27, R28, R29, R30, R31: 330; R_0402_1005Metric
R15: 1k; R_0402_1005Metric
R16, R20: 8.06k+1%; R_0402_1005Metric
R17, R21: 20k; R_0402_1005Metric
R22: 15K; R_0402_1005Metric
R23, R32, R35, R36: R; R_0402_1005Metric
SW1: BTN_RECOVERY; SWITCH-FSMRA
SW2: BTN_DFU; SWITCH-FSMRA
SW3: BTN_RESET; SWITCH-FSMRA
TP1, TP2, TP3, TP4, TP5, TP6: TestPoint; TestPoint_Pad_D1.0mm
U1: 2450FB15A050; Filter_Johanson_2x1.25mm
U3: MIC5219-3.3YM5; SOT-23-5
U4: TCR2EE11; SOT-553
U5: MIC5504-2.5YM5; SOT-23-5
U6: ATSAMD21G18A-AUT; TQFP-48_7x7mm_P0.5mm
U7: W25Q32JVSS; SOIC-8_5.23x5.23mm_P1.27mm
U8, U11: USB3343; VQFN-24-1EP_4x4mm_P0.5mm_EP2.45x2.45mm
U9: AT86RF215; QFN-48-1EP_7x7mm_P0.5mm_EP5.6x5.6mm
U10: S27KL0641; BGA-24_5x5_6.0x8.0mm
U12: 0896BM15E0025; Filter_Johanson_2x1.25mm
U13: TXETALSANF-26.000000; Oscillator_SMD_SeikoEpson_SG8002CE-4Pin_3.2x2.5mm
Y1: DSC60xx; Crystal_SMD_2016-4Pin_2.0x1.6mm

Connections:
+1V1: C1.1, C3.1, C7.1, C9.1, C11.1, C13.1, C15.1, C17.1, C29.1, IC1.G6, IC1.G7, IC1.G9, IC1.L8, IC1.L9, IC1.L10, TP4.1, U4.4, U6.8
+2V5: C22.1, C24.1, C26.1, C27.1, C30.1, IC1.G11, IC1.L7, TP5.1, U4.1, U4.3, U5.5, U6.3
+3V3: C2.1, C4.1, C8.1, C10.1, C12.1, C14.1, C16.1, C18.1, C20.1, C23.1, C25.1, C28.1, C31.1, C32.1, C33.1, C34.1, C35.1, C39.1, C49.1, C57.1, C60.1, C61.1, C62.1, C63.1, C64.1, D2.2, D3.2, D4.2, D5.2, D6.2, D7.2, D10.2, D11.2, D12.2, D13.2, D14.2, IC1.F6, IC1.F7, IC1.F10, IC1.F11, IC1.H6, IC1.H7, IC1.H11, IC1.J6, IC1.J7, IC1.J11, IC1.K11, IC1.L6, IC1.L11, J5.1, J6.1, R13.2, R22.2, R23.2, R24.2, R25.1, R32.2, TP3.1, U3.5, U5.1, U5.3, U6.6, U6.17, U6.36, U6.44, U7.8, U8.2, U8.9, U9.15, U9.21, U9.29, U9.39, U9.46, U10.B4, U10.D1, U10.E4, U11.2, U11.9, U13.4, Y1.1, Y1.4
+5V: C6.1, C38.1, C47.1, D1.1, D8.1, U3.1, U3.3, U8.16, U11.16
/DEBUG_SPI_CIPO: IC1.P11, U6.23
/DEBUG_SPI_CLK: IC1.R13, U6.22
/DEBUG_SPI_COPI: IC1.P13, U6.21
/DEBUG_SPI_CS: IC1.T13, U6.24
/Debug & Control Connections/CLKIN_60MHZ: IC1.A7, TP1.1, Y1.3
/FORCE_DFU: SW2.2, U6.20
/FORCE_RECOVERY: SW1.2, U6.37
/FPGA Configuration and Dev Features/D0: IC1.T8, U7.5
/FPGA Configuration and Dev Features/D1: IC1.T7, U7.2
/FPGA Configuration and Dev Features/D2: IC1.M7, U7.3
/FPGA Configuration and Dev Features/D3: IC1.N7, U7.7
/FPGA Configuration and Dev Features/FPGA_CFG0: IC1.N10, R12.1
/FPGA Configuration and Dev Features/FPGA_CFG1: IC1.P10, R13.1
/FPGA Configuration and Dev Features/FPGA_CFG2: IC1.R10, R14.1
/FPGA Configuration and Dev Features/FPGA_CONFIG_CLK: IC1.N9, U6.10, U7.6
/FPGA Configuration and Dev Features/FPGA_DONE: IC1.P9, U6.19
/FPGA Configuration and Dev Features/FPGA_TCK: IC1.T10, J5.4, U6.14
/FPGA Configuration and Dev Features/FPGA_TDI: IC1.R11, J5.8, U6.13
/FPGA Configuration and Dev Features/FPGA_TDO: IC1.M10, J5.6, U6.15
/FPGA Configuration and Dev Features/FPGA_TMS: IC1.T11, J5.2, U6.16
/FPGA Configuration and Dev Features/UC_SWDCLK: J6.4, U6.45
/FPGA Configuration and Dev Features/UC_SWDIO: J6.2, U6.46
/FPGA Configuration and Dev Features/~CS_DI: IC1.N8, U6.9, U7.1
/FPGA Configuration and Dev Features/~FPGA_INIT: IC1.T9, U6.25
/FPGA Configuration and Dev Features/~FPGA_PROGRAM: IC1.R9, U6.26
/FULL_RESET: J6.10, R25.2, SW3.2, U6.40
/HOST_D+: J1.3, U11.14
/HOST_D-: J1.2, U11.13
/HOST_ID: J1.4, U11.18
/HOST_PHY_1V8: C50.1, U6.11, U11.23
/Host Section/HOST_DATA0: IC1.G2, U11.4
/Host Section/HOST_DATA1: IC1.G1, U11.5
/Host Section/HOST_DATA2: IC1.F2, U11.6
/Host Section/HOST_DATA3: IC1.F1, U11.7
/Host Section/HOST_DATA4: IC1.E1, U11.8
/Host Section/HOST_DATA5: IC1.D1, U11.10
/Host Section/HOST_DATA6: IC1.C1, U11.11
/Host Section/HOST_DATA7: IC1.C2, U11.12
/Host Section/HOST_DIR: IC1.J1, U11.1
/Host Section/HOST_NXT: IC1.H2, U11.3
/Host Section/HOST_PHY_CLK: IC1.K2, U11.21
/Host Section/HOST_PHY_RESET: IC1.K1, R24.1, U11.22
/Host Section/HOST_STP: IC1.J2, U11.24
/Host Section/HOST_VBUS: D1.2, J1.1, R21.1
/Host Section/USER_IO0_N: IC1.B2, TP6.1
/Host Section/USER_IO0_P: IC1.B1, TP2.1
/Host Section/USER_IO1_N: C65.1, J8.1
/Host Section/USER_IO1_P: C21.1, J9.1
/RAM / 1V8 Section/CLK: IC1.B14, U10.B2
/RAM / 1V8 Section/RAM_DQ0: IC1.A11, U10.D3
/RAM / 1V8 Section/RAM_DQ1: IC1.B10, U10.D2
/RAM / 1V8 Section/RAM_DQ2: IC1.B12, U10.C4
/RAM / 1V8 Section/RAM_DQ3: IC1.A12, U10.D4
/RAM / 1V8 Section/RAM_DQ4: IC1.B11, U10.D5
/RAM / 1V8 Section/RAM_DQ5: IC1.A10, U10.E3
/RAM / 1V8 Section/RAM_DQ6: IC1.B9, U10.E2
/RAM / 1V8 Section/RAM_DQ7: IC1.A9, U10.E1
/RAM / 1V8 Section/RAM_RWDS: IC1.A13, U10.C3
/RAM / 1V8 Section/~CLK: IC1.A15, U10.B1
/RAM / 1V8 Section/~CS: IC1.A14, U10.A3
/RAM / 1V8 Section/~RESET: IC1.B13, U10.A4
/Right side indicators/D0: IC1.P15, R31.2
/Right side indicators/D1: IC1.N16, R30.2
/Right side indicators/D2: IC1.M15, R29.2
/Right side indicators/D3: IC1.M16, R28.2
/Right side indicators/D4: IC1.L15, R27.2
/Right side indicators/D5: IC1.L16, R26.2
/SIDEBAND_D+: J2.3, U6.34, U8.14
/SIDEBAND_D-: J2.2, U6.33, U8.13
/SIDEBAND_ID: J2.4, U8.18
/SIDEBAND_PHY_1V8: C37.1, U6.4, U8.23
/SIDEBAND_VBUS: D8.2, J2.1, R17.1
/Sideband Section/SIDEBAND_DATA0: IC1.R2, U8.4
/Sideband Section/SIDEBAND_DATA1: IC1.R1, U8.5
/Sideband Section/SIDEBAND_DATA2: IC1.P2, U8.6
/Sideband Section/SIDEBAND_DATA3: IC1.P1, U8.7
/Sideband Section/SIDEBAND_DATA4: IC1.N1, U8.8
/Sideband Section/SIDEBAND_DATA5: IC1.M2, U8.10
/Sideband Section/SIDEBAND_DATA6: IC1.M1, U8.11
/Sideband Section/SIDEBAND_DATA7: IC1.L2, U8.12
/Sideband Section/SIDEBAND_DIR: IC1.T3, U8.1
/Sideband Section/SIDEBAND_NXT: IC1.T2, U8.3
/Sideband Section/SIDEBAND_PHY_CLK: IC1.R4, U8.21
/Sideband Section/SIDEBAND_STP: IC1.T4, U8.24
/Target Section/CIPO: IC1.G16, U9.44
/Target Section/COPI: IC1.F16, U9.43
/Target Section/IRQ: IC1.F15, U9.40
/Target Section/RF09: C55.1, J3.1, R3.1, R4.2
/Target Section/RF09_N: U9.9, U12.3
/Target Section/RF09_P: U9.8, U12.4
/Target Section/RF24: C45.1, J4.1, R1.1, R2.2
/Target Section/RF24_N: C46.1, U9.5
/Target Section/RF24_P: C42.2, U9.4
/Target Section/RXCLK_N: IC1.J15, U9.33
/Target Section/RXCLK_P: IC1.J16, U9.34
/Target Section/RXD09_N: IC1.E15, U9.30
/Target Section/RXD09_P: IC1.D16, U9.31
/Target Section/RXD24_N: IC1.K15, U9.35
/Target Section/RXD24_P: IC1.K16, U9.36
/Target Section/SCLK: IC1.K14, U9.41
/Target Section/TXCLK_N: IC1.B15, U9.25
/Target Section/TXCLK_P: IC1.B16, U9.26
/Target Section/TXD_N: IC1.C15, U9.27
/Target Section/TXD_P: IC1.C16, U9.28
/Target Section/~RSTN: IC1.C14, U9.13
/Target Section/~SELN: IC1.E16, U9.42
/UC_RX_FPGA_TX: IC1.T14, U6.2
/UC_TX_FPGA_RX: IC1.R14, U6.1
/USB_INHIBIT: R15.1, R22.1, U6.38, U8.22
AVSS: C1.2, C2.2, C3.2, C4.2, C6.2, C7.2, C8.2, C9.2, C10.2, C11.2, C12.2, C13.2, C14.2, C15.2, C16.2, C17.2, C18.2, C20.2, C22.2, C23.2, C24.2, C25.2, C26.2, C27.2, C28.2, C29.2, C30.2, C31.2, C32.2, C33.2, C34.2, C35.2, C36.2, C37.2, C38.2, C39.2, C40.2, C41.2, C44.2, C45.2, C47.2, C48.2, C49.2, C50.2, C51.2, C52.2, C54.2, C55.2, C57.2, C58.2, C59.2, C60.2, C61.2, C62.2, C63.2, C64.2, IC1.A1, IC1.A16, IC1.D2, IC1.D15, IC1.F8, IC1.F9, IC1.G8, IC1.G10, IC1.H1, IC1.H8, IC1.H9, IC1.H10, IC1.H16, IC1.J8, IC1.J9, IC1.J10, IC1.K6, IC1.K7, IC1.K8, IC1.K9, IC1.K10, IC1.N2, IC1.N15, IC1.T1, IC1.T5, IC1.T12, IC1.T16, J1.5, J1.6, J2.5, J2.6, J3.2, J4.2, J5.3, J5.5, J5.9, J6.3, J6.5, J6.9, J8.2, J9.2, R2.1, R4.1, R5.2, R6.2, R12.2, R14.2, R16.1, R20.1, R35.2, R36.2, SW1.1, SW2.1, SW3.1, U1.2, U1.5, U3.2, U4.2, U5.2, U6.5, U6.18, U6.35, U6.42, U7.4, U8.25, U9.3, U9.6, U9.7, U9.10, U9.16, U9.19, U9.20, U9.23, U9.24, U9.32, U9.38, U9.45, U9.48, U9.49, U10.B3, U10.C1, U10.E5, U11.25, U12.2, U12.5, U12.6, U13.1, U13.2, Y1.2
unnamed: C21.2, IC1.C3, R23.1, R35.1
unnamed: C36.1, U8.15
unnamed: C40.1, U9.47
unnamed: C41.1, U9.14
unnamed: C42.1, L1.1, U1.4
unnamed: C43.1, C44.1, R1.2
unnamed: C43.2, U1.1
unnamed: C46.2, L1.2, U1.3
unnamed: C48.1, U11.15
unnamed: C51.1, U6.43
unnamed: C52.1, U3.4
unnamed: C53.1, C54.1, R3.2
unnamed: C53.2, U12.1
unnamed: C56.1, C58.1, R5.1, U9.17
unnamed: C56.2, U13.3
unnamed: C59.1, U9.37
unnamed: C65.2, IC1.D3, R32.1, R36.1
unnamed: D2.1, R26.1
unnamed: D3.1, R27.1
unnamed: D4.1, R28.1
unnamed: D5.1, R29.1
unnamed: D6.1, R30.1
unnamed: D7.1, R31.1
unnamed: D10.1, R7.1
unnamed: D11.1, R8.1
unnamed: D12.1, R9.1
unnamed: D13.1, R10.1
unnamed: D14.1, R11.1
unnamed: IC1.R3, R15.2
unnamed: R6.1, U9.18
unnamed: R7.2, U6.27
unnamed: R8.2, U6.28
unnamed: R9.2, U6.29
unnamed: R10.2, U6.30
unnamed: R11.2, U6.31
unnamed: R16.2, U8.19
unnamed: R17.2, U8.17
unnamed: R20.2, U11.19
unnamed: R21.2, U11.17

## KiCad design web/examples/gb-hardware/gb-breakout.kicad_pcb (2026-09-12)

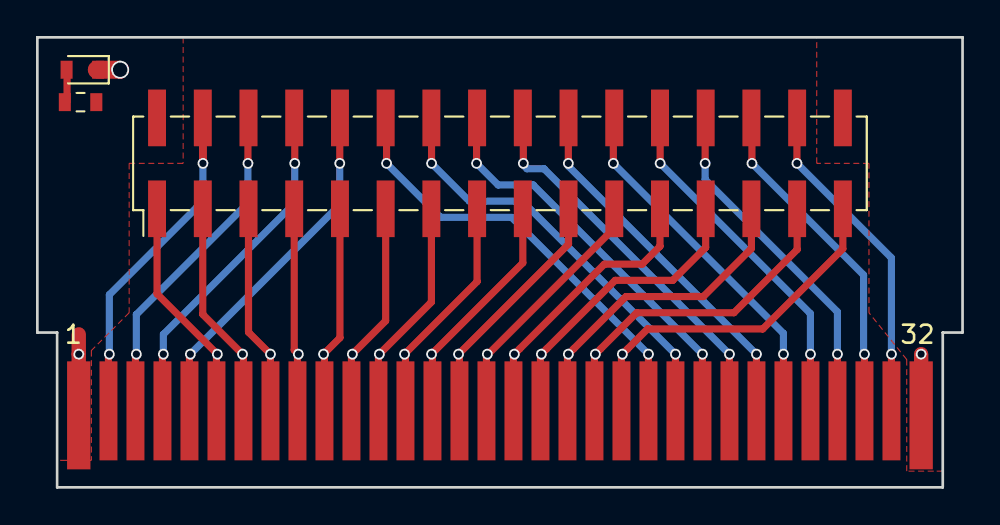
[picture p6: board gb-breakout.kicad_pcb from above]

Board: 2 copper layers, 51.4 x 25.0 mm, 4 parts (0 on the bottom side), 33 nets.

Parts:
D1: LED_R; LED_0603_1608Metric
J1: CONN_02X16; PinHeader_2x16_P2.54mm_Vertical_SMD
J2: Conn_GameBoy_Cartridge; GameBoy_Cartridge
R1: 1K; R_0603_1608Metric

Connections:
+5V: J1.2, J2.1, R1.1
/A0: J1.1, J2.6
/A1: J1.3, J2.7
/A2: J1.5, J2.8
/A3: J1.7, J2.9
/A4: J1.9, J2.10
/A5: J1.11, J2.11
/A6: J1.13, J2.12
/A7: J1.15, J2.13
/A8: J1.17, J2.14
/A9: J1.19, J2.15
/A10: J1.21, J2.16
/A11: J1.23, J2.17
/A12: J1.25, J2.18
/A13: J1.27, J2.19
/A14: J1.29, J2.20
/A15: J1.31, J2.21
/D0: J1.12, J2.22
/D1: J1.14, J2.23
/D2: J1.16, J2.24
/D3: J1.18, J2.25
/D4: J1.20, J2.26
/D5: J1.22, J2.27
/D6: J1.24, J2.28
/D7: J1.26, J2.29
/PHI: J1.4, J2.2
/VIN: J1.30, J2.31
GND: D1.1, J1.32, J2.32
unnamed: D1.2, R1.2
~CS: J1.10, J2.5
~RD: J1.8, J2.4
~RES: J1.28, J2.30
~WR: J1.6, J2.3

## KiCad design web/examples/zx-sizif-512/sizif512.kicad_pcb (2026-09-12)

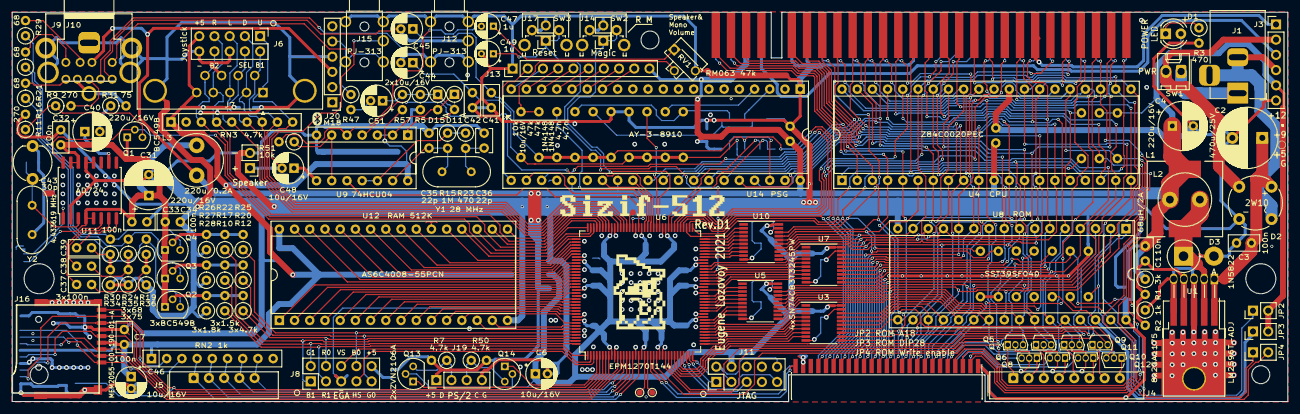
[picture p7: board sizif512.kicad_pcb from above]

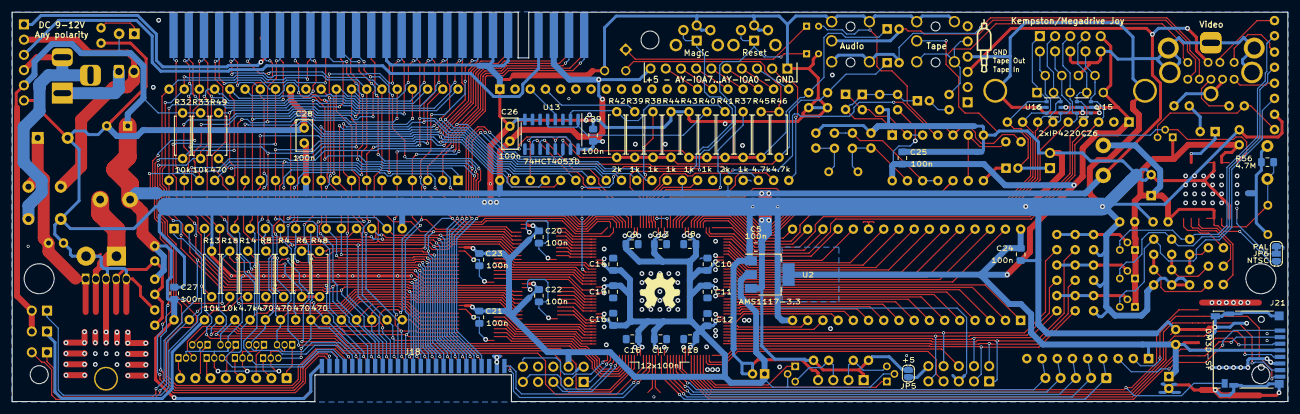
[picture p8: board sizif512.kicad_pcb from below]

Board: 2 copper layers, 213.0 x 65.0 mm, 188 parts (53 on the bottom side), 240 nets.

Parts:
C1: 10n; C_Disc_D5.0mm_W2.5mm_P2.50mm
C2: 470u/25V; CP_Radial_D10.0mm_P5.00mm
C3, C7, C26, C28, C32, C33, C34, C37, C38, C39: 100n; C_Disc_D5.0mm_W2.5mm_P2.50mm
C4, C31: 220u/16V; CP_Radial_D8.0mm_P3.50mm
C5, C8, C9, C10, C11, C12, C13, C14, C15, C16, C17, C19, C20, C21, C22, C23, C24, C25, C27, C29: 100n; C_0805_2012Metric_Pad1.15x1.40mm_HandSolder
C6, C44, C45, C46, C48, C51: 10u/16V; CP_Radial_D5.0mm_P2.00mm
C18: 10n; C_0805_2012Metric_Pad1.15x1.40mm_HandSolder
C35, C36: 22p; C_Disc_D3.8mm_W2.6mm_P2.50mm
C40: 220u/16V; CP_Radial_D6.3mm_P2.50mm
C41, C42: 4.7n; C_Disc_D5.0mm_W2.5mm_P2.50mm
C43: 30p; C_Trim_D6.3mm_P5.50mm
C47, C49: 1u; CP_Radial_D4.0mm_P2.00mm
D1: LED; LED_D4.0mm
D2: 2W10; Diode_Bridge_Round_D10.0mm
D3: 1N5822; D_DO-201AD_P5.08mm_Vertical_AnodeUp
D11, D15: 1N4148; D_DO-35_SOD27_P2.54mm_Vertical_AnodeUp
H1, H2: MountingHole; MountingHole_5mm_7mm_fence
H3, H4, H5: MountingHole; MountingHole_3mm
J1: DS-210; BarrelJack_Horizontal
J2: Conn_02x28_Row_Letter_First; ZX_EDGE
J3, J20: Pin header 1x6 Pitch=2.54mm; PinHeader_1x06_P2.54mm_Vertical
J4: DS1020-08; FFC_FPC_1x08
J5: DS1020-05; FFC_FPC_1x05
J6, J8, J11: Pin header 2x5 Pitch=2.54mm; PinHeader_2x05_P2.54mm_Vertical
J7: DB9-M; DSUB-9_Male_Horizontal_P2.77x2.84mm_EdgePinOffset4.94mm_Hou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
J9: Mini-DIN-9; minidin-9
J10: RCJ-014; CUI_RCJ-01X-WIDE
J12, J15: PJ-313
J13: Pin header 1x10 Pitch=2.54mm; PinHeader_1x10_P2.54mm_Vertical
J14, J17: Pin header 1x2 Pitch=2.54mm; PinHeader_2x01_P2.54mm_Vertical
J16: MEM2055-00-190-01-A; GCT-MEM2055-00-190-01-A
J18: Pin socket 3x25 or 2xPin socket 1x25 Pitch=1.27mm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; PinHeader_2x25_P1.27mm_Edge_SMD
J19: Pin header 1x4 Pitch=2.54mm; PinHeader_1x04_P2.54mm_Vertical
J21: DM3D-SF; microSD_HC_Hirose_DM3D-SF
JP2, JP3, JP4: Jumper / Pin header 1x2 Pitch=2.54mm; PinHeader_1x02_P2.54mm_Vertical
JP5: SolderJumper_2_Open; SolderJumper-2_P1.3mm_Open_RoundedPad1.0x1.5mm
JP6: Jumper_3_Bridged12; SolderJumper-3_P1.3mm_Bridged12_RoundedPad1.0x1.5mm_NumberL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
L1: 68uH/2A; L_Radial_D8.7mm_P5.00mm_Fastron_07HCP
L2: 68uH/2A; L_12x12mm_H8mm
L3: 220u/0.2A; L_Radial_D8.7mm_P5.00mm_Fastron_07HCP
LOGO1: graphic; black-mage2
LOGO2: Logo_Open_Hardware_Small; OSHW-Symbol_6.7x6mm_SilkScreen
LOGO3: graphic; jack35
LOGO4: graphic; bluetooth_small
LOGO5: graphic; sizif512
LS1: Pin header 1x2 Pitch=2.54mm; PinHeader_1x02_P2.54mm_Vertical
Q1, Q2, Q3, Q4: BC549B; TO-92
Q5, Q6, Q7, Q8, Q9, Q10, Q11, Q12: 2SA1175; TO-92S
Q13, Q14: ZVN2106A; TO-92
R1: 3k; R_Axial_DIN0207_L6.3mm_D2.5mm_P2.54mm_Vertical
R2: 1k; R_Axial_DIN0207_L6.3mm_D2.5mm_P2.54mm_Vertical
R3, R23: 470; R_Axial_DIN0207_L6.3mm_D2.5mm_P2.54mm_Vertical
R4, R6, R8, R48, R49: 470; R_Axial_DIN0207_L6.3mm_D2.5mm_P7.62mm_Horizontal
R5, R57: 47k; R_Axial_DIN0207_L6.3mm_D2.5mm_P2.54mm_Vertical
R7, R12, R20, R25, R50: 4.7k; R_Axial_DIN0207_L6.3mm_D2.5mm_P2.54mm_Vertical
R9, R11: 270; R_Axial_DIN0207_L6.3mm_D2.5mm_P2.54mm_Vertical
R10, R17, R22: 1.5k; R_Axial_DIN0207_L6.3mm_D2.5mm_P2.54mm_Vertical
R13, R18, R32, R33: 10k; R_Axial_DIN0207_L6.3mm_D2.5mm_P7.62mm_Horizontal
R14, R45, R46: 4.7k; R_Axial_DIN0207_L6.3mm_D2.5mm_P7.62mm_Horizontal
R15: 1M; R_Axial_DIN0207_L6.3mm_D2.5mm_P2.54mm_Vertical
R16, R19, R21, R24, R29, R30: 68; R_Axial_DIN0207_L6.3mm_D2.5mm_P2.54mm_Vertical
R26, R27, R28: 1.8k; R_Axial_DIN0207_L6.3mm_D2.5mm_P2.54mm_Vertical
R31, R34, R35, R36: 75; R_Axial_DIN0207_L6.3mm_D2.5mm_P2.54mm_Vertical
R37, R38, R39, R40, R43, R44: 1k; R_Axial_DIN0207_L6.3mm_D2.5mm_P7.62mm_Horizontal
R41, R42: 2k; R_Axial_DIN0207_L6.3mm_D2.5mm_P7.62mm_Horizontal
R47, R51: 10k; R_Axial_DIN0207_L6.3mm_D2.5mm_P2.54mm_Vertical
R56: 4.7M; R_0805_2012Metric_Pad1.15x1.40mm_HandSolder
RN2: 1k; R_Array_SIP9
RN3: 4.7k; R_Array_SIP9
RV1: RM063 47k; Potentiometer_Runtron_RM-063_Horizontal
SW1: Jumper / Pin header 1x2 Pitch=2.54mm; Molex_KK-254_AE-6410-02A_1x02_P2.54mm_Vertical
SW2, SW3: Button THT; SW_Tactile_SPST_Angled_PTS645Vx83-2LFS
TP1, TP4, TP7: TestPoint; TestPoint_Pad_D1.0mm
U1: LM2596T-ADJ; TO-220-263-5_Horizontal_TabDown
U2: AMS1117-3.3; SOT-223-3_TabPin2
U3, U5, U7, U10: SN74CB3T3245PW; TSSOP-20_4.4x6.5mm_P0.65mm
U4: Z84C0020PEC; DIP-40_W15.24mm_Socket
U6: EPM1270T144; LQFP-144_20x20mm_P0.5mm
U8: SST39SF040; DIP-32_W15.24mm_Socket
U9: 74HCU04; DIP-14_W7.62mm_Socket
U11: AD724; SOIC-16W_7.5x10.3mm_P1.27mm
U12: AS6C4008-55PCN; DIP-32_W15.24mm_Socket
U13: 74HCT4053D; SOIC-16_3.9x9.9mm_P1.27mm
U14: AY-3-8910; DIP-40_W15.24mm_Socket
U15, U16: IP4220CZ6; TSOP-6_1.65x3.05mm_P0.95mm
Y1: 28 MHz; Crystal_HC49-U_Vertical
Y2: 4.433619 MHz; Crystal_HC49-U_Vertical

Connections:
+3V3: C6.1, C7.2, C8.1, C9.1, C10.1, C11.1, C12.1, C13.1, C14.1, C15.1, C16.1, C17.1, C18.1, C19.1, C20.1, C21.1, C22.1, C23.1, C24.2, C25.2, C46.1, J6.9, J7.5, J11.4, J16.4, J21.4, Q13.2, Q14.2, R57.2, RN2.1, RN3.1, U2.2, U3.20, U5.20, U6.9, U6.19, U6.25, U6.46, U6.56, U6.64, U6.82, U6.90, U6.100, U6.116, U6.126, U6.136, U7.20, U9.14, U10.20, U12.32, U15.5, U16.5
+5V: C1.1, C4.1, C5.2, C26.2, C27.2, C28.2, C29.2, D1.2, J2.A3, J3.5, J9.2, J13.10, J18.1, J18.2, J19.1, J20.3, JP2.2, JP3.2, JP5.1, L1.2, L2.2, L3.1, R1.1, R6.2, R7.2, R18.1, R32.2, R33.2, R48.2, R50.2, U2.3, U4.11, U8.32, U13.16, U14.25, U14.28, U14.40
+5VA: C31.1, C32.2, C33.2, C34.2, JP6.3, L3.2, Q1.1, Q2.1, Q3.1, Q4.1, U11.4, U11.5, U11.14, U11.15
+9V: J2.A4, J3.3
+12V: J2.B22, J3.1
/A0: J2.A9, J18.35, U4.30, U7.18, U8.12
/A1: J2.A10, J18.33, U4.31, U7.17, U8.11
/A2: J2.A11, J18.32, U4.32, U7.16, U8.10
/A3: J2.A12, J18.31, U4.33, U7.15, U8.9
/A4: J2.A24, J18.30, U4.34, U7.14, U8.8
/A5: J2.A23, J18.36, U4.35, U8.7, U10.12
/A6: J2.A22, J18.29, U4.36, U7.13, U8.6
/A7: J2.A21, J18.28, U4.37, U7.12, U8.5
/A8: J2.B26, J18.6, Q10.3, U4.38, U5.13, U8.27
/A9: J2.A27, J18.9, Q7.3, U4.39, U5.12, U8.26
/A10: J2.B27, J18.11, Q6.3, U3.18, U4.40, U8.23
/A11: J2.A28, J18.10, Q5.3, U4.1, U5.11, U8.25
/A12: J2.A2, J18.8, Q8.3, U4.2, U7.11, U8.4
/A13: J2.B2, J18.20, Q9.3, U4.3, U8.28, U10.17
/A14: J2.A1, J18.24, Q11.3, U3.12, U4.4
/A15: J2.B1, J18.23, Q12.3, U3.13, U4.5
/AY_ABC: U6.80, U13.9, U13.10
/AY_BC1: U6.87, U14.29
/AY_BDIR: U6.88, U14.27
/AY_CLK: U6.93, U14.22
/AY_MONO: U6.81, U13.11
/BUS0: J18.49, U6.22
/BUS1: J18.50, U6.23
/Blue0: J8.8, R25.1, U6.140
/Blue1: J8.1, R22.1, U6.143
/CLK28: U6.91, U9.10
/CLKCPU: J18.34, R6.1, U4.6, U10.16
/Csync: Q1.2, U6.107, U11.16
/D0: J2.B6, J18.37, U4.14, U8.13, U10.13, U14.37
/D1: J2.B7, J18.38, U4.15, U8.14, U10.14, U14.36
/D2: J2.B8, J18.39, U4.12, U8.15, U10.15, U14.35
/D3: J2.B11, J18.22, U3.14, U4.8, U8.17, U14.34
/D4: J2.B12, J18.21, U3.11, U4.7, U8.18, U14.33
/D5: J2.B10, J18.18, U3.15, U4.9, U8.19, U14.32
/D6: J2.B9, J18.16, U3.16, U4.10, U8.20, U14.31
/D7: J2.B3, J18.14, U3.17, U4.13, U8.21, U14.30
/Green0: J8.9, R20.1, U6.141
/Green1: J8.2, R17.1, U6.144
/Hsync: J8.7, U6.3
/JOY_SEL: J6.4, J7.7, RN3.6, U6.98, U16.4
/KD0: J5.1, RN2.4, U6.18
/KD1: J5.2, RN2.5, U6.16
/KD2: J5.3, RN2.6, U6.15
/KD3: J5.4, RN2.7, U6.14
/KD4: J5.5, RN2.8, U6.13
/MIX_L: C42.2, C44.1, J18.43, R38.1, R39.1, R42.1, R44.1, R46.1, U13.14
/MIX_R: C41.2, C45.1, J18.42, R37.1, R40.1, R41.1, R43.1, R45.1, U13.13
/PS2_CLK: Q14.1, U6.4
/PS2_DAT: Q13.1, U6.5
/RA14: U6.30, U8.29
/RA15: U6.29, U8.3
/RA16: U6.28, U8.2
/RA17: R14.1, U6.27
/Red0: J8.4, R12.1, U6.142
/Red1: J8.3, R10.1, U6.1
/SD_CD: J16.9, J21.9, U6.6
/SD_CS: J16.2, J21.2, U6.12
/SD_DAT1: J16.8, J21.8, RN2.2
/SD_DAT2: J16.1, J21.1, RN2.3
/SD_MISO: J16.7, J21.7, U6.7
/SD_MOSI: J16.3, J21.3, U6.11
/SD_SCK: J16.5, J21.5, U6.8
/SND_DAC_L: R38.2, U6.85
/SND_DAC_R: R37.2, U6.89
/SND_L: C44.2, J9.8, J12.T
/SND_MONO: C48.2, J9.6, J15.R, LS1.1
/SND_R: C45.2, J9.9, J12.R
/TAPE_IN: J15.T, J20.5, R47.1
/TAPE_IN0: U6.86, U9.4
/TCK: J11.1, U6.35
/TDI: J11.9, U6.34
/TDO: J11.3, U6.36
/TMS: J11.5, U6.33
/VA0: U6.134, U12.12
/VA1: U6.133, U12.11
/VA2: U6.132, U12.10
/VA3: U6.131, U12.9
/VA4: U6.130, U12.8
/VA5: U6.129, U12.7
/VA6: U6.127, U12.6
/VA7: U6.125, U12.5
/VA8: U6.114, U12.27
/VA9: U6.113, U12.26
/VA10: U6.110, U12.23
/VA11: U6.112, U12.25
/VA12: U6.124, U12.4
/VA13: U6.117, U12.28
/VA14: U6.123, U12.3
/VA15: U6.120, U12.31
/VA16: U6.122, U12.2
/VA17: U6.121, U12.1
/VA18: U6.119, U12.30
/VD0: U6.137, U12.13
/VD1: U6.139, U12.14
/VD2: U6.138, U12.15
/VD3: U6.102, U12.17
/VD4: U6.104, U12.18
/VD5: U6.108, U12.19
/VD6: U6.106, U12.20
/VD7: U6.109, U12.21
/VID_B: J9.1, R29.2
/VID_COMP: J9.4, J10.1, R31.2
/VID_G: J9.3, R21.2
/VID_R: J9.7, R16.2
/VID_SYNC: J9.5, R9.2
/Vsync: J8.6, U6.2
/xA0: U6.63, U7.2
/xA1: U6.62, U7.3
/xA2: U6.60, U7.4
/xA3: U6.59, U7.5
/xA4: U6.58, U7.6
/xA5: U6.67, U10.8
/xA6: U6.57, U7.7
/xA7: U6.55, U7.8
/xA8: U5.7, U6.45
/xA9: U5.8, U6.44
/xA10: U3.2, U6.42
/xA11: U5.9, U6.43
/xA12: U6.53, U7.9
/xA13: U6.72, U10.3
/xA14: U3.8, U6.32
/xA15: U3.7, U6.37
/xCLKCPU: U6.71, U10.4
/xD0: U6.68, U10.7
/xD1: U6.69, U10.6
/xD2: U6.70, U10.5
/xD3: U3.6, U6.38
/xD4: U3.9, U6.31
/xD5: U3.5, U6.39
/xD6: U3.4, U6.40
/xD7: U3.3, U6.41
/~BUSACK: J2.A26, J18.3, U4.23
/~BUSRQ: J2.A19, J18.5, R32.1, U4.25
/~CLKCPU: J2.A8, R48.1, U10.18
/~DRD: J2.A16, U6.79
/~DWR: J2.A17, U6.78
/~HALT: J2.B15, J18.4, U4.18
/~INT: J18.40, R49.2, U6.73
/~INTB: J2.B13, R49.1, U4.16
/~IORQ: J2.B17, J18.13, R4.2, U4.20
/~IORQGE: J2.A13, J18.19, R4.1, U10.11
/~JOY_B1: J6.2, J7.6, RN3.8, U6.96, U16.3
/~JOY_B2: J6.8, J7.9, RN3.3, U6.105, U15.6
/~JOY_DOWN: J6.3, J7.2, RN3.7, U6.97, U16.6
/~JOY_LEFT: J6.5, J7.3, RN3.5, U6.101, U15.3
/~JOY_RIGHT: J6.7, J7.4, RN3.4, U6.103, U15.1
/~JOY_UP: J6.1, J7.1, RN3.9, U6.95, U16.1
/~M1: J2.B24, J18.25, U4.27, U5.14
/~MREQ: J2.B16, J18.27, U4.19, U5.18
/~MTR: J2.A18, U6.77
/~NMI: J2.B14, J18.41, U4.17, U6.74
/~RD: J2.B18, J18.17, U4.21, U5.15, U8.24
/~RFSH: J2.B25, J18.26, U4.28, U5.17
/~ROMCS: R8.1, U6.24
/~ROMCSB: J2.A25, J18.12, R8.2, U8.22
/~RSTCPU: J2.A20, J18.44, U4.26, U6.76, U14.23
/~VRD: U6.111, U12.24
/~VWR: U6.118, U12.29
/~WAIT: J2.B21, J18.7, R33.1, U4.24
/~WR: J2.B19, J18.15, JP4.1, U4.22, U5.16
/~xCLKCPU: U6.75, U10.2
/~xIORQGE: U6.66, U10.9
/~xM1: U5.6, U6.48
/~xMREQ: U5.2, U6.52
/~xRD: U5.5, U6.49
/~xRFSH: U5.3, U6.51
/~xWR: U5.4, U6.50
GND: C2.2, C3.2, C4.2, C5.1, C6.2, C7.1, C8.2, C9.2, C10.2, C11.2, C12.2, C13.2, C14.2, C15.2, C16.2, C17.2, C18.2, C19.2, C20.2, C21.2, C22.2, C23.2, C24.1, C25.1, C26.1, C27.1, C28.1, C29.1, C31.2, C32.1, C33.1, C34.1, C35.1, C36.1, C41.1, C42.1, C43.2, C46.2, C49.2, D2.1, D3.2, J2.A6, J2.A7, J2.A14, J3.6, J6.6, J6.10, J7.0, J7.8, J8.5, J9.0, J10.2, J11.2, J11.10, J12.S, J13.1, J14.2, J15.S, J16.6, J16.10, J16.11, J17.2, J18.47, J18.48, J19.4, J20.4, J21.6, J21.10, J21.11, JP6.1, LS1.2, Q5.2, Q6.2, Q7.2, Q8.2, Q9.2, Q10.2, Q11.2, Q12.2, R2.1, R3.2, R5.2, R11.2, R13.1, R26.1, R27.1, R28.1, R34.1, R35.1, R36.1, R43.2, R44.2, R56.1, RV1.3, SW2.1, SW3.1, U1.3, U1.5, U2.1, U3.10, U3.19, U4.29, U5.10, U5.19, U6.10, U6.17, U6.26, U6.47, U6.54, U6.65, U6.83, U6.92, U6.99, U6.115, U6.128, U6.135, U7.10, U7.19, U8.16, U9.7, U10.10, U10.19, U11.2, U11.12, U11.13, U12.16, U12.22, U13.6, U13.7, U13.8, U14.1, U14.24, U15.2, U16.2, Y2.2
unnamed: C1.2, R1.2, R2.2, U1.4
unnamed: C2.1, C3.1, D2.3, U1.1
unnamed: C35.2, R15.2, U9.13, Y1.2
unnamed: C36.2, R23.2, Y1.1
unnamed: C37.1, R19.1, R36.2
unnamed: C37.2, U11.6
unnamed: C38.1, R24.1, R35.2
unnamed: C38.2, U11.7
unnamed: C39.1, R30.1, R34.2
unnamed: C39.2, U11.8
unnamed: C40.1, U11.10
unnamed: C40.2, R31.1
unnamed: C43.1, R56.2, U11.3, Y2.1
unnamed: C47.1, RV1.1
unnamed: C47.2, R51.2, U9.5
unnamed: C48.1, U9.8
unnamed: C51.1, D11.2, D15.1, R5.1, R57.1, U9.1
unnamed: C51.2, R47.2
unnamed: D1.1, R3.1
unnamed: D2.2, J1.2, J1.3, J3.4
unnamed: D2.4, J3.2, SW1.2
unnamed: D3.1, L1.1, L2.1, U1.2
unnamed: D11.1, D15.2, U9.2, U9.3
unnamed: J1.1, SW1.1
unnamed: J4.1, Q5.1
unnamed: J4.2, Q6.1
unnamed: J4.3, Q7.1
unnamed: J4.4, Q8.1
unnamed: J4.5, Q9.1
unnamed: J4.6, Q10.1
unnamed: J4.7, Q11.1
unnamed: J4.8, Q12.1
unnamed: J8.10, JP5.2
unnamed: J13.2, U14.21
unnamed: J13.3, U14.20
unnamed: J13.4, U14.19
unnamed: J13.5, U14.18
unnamed: J13.6, U14.17
unnamed: J13.7, U14.16
unnamed: J13.8, U14.15
unnamed: J13.9, U14.14
unnamed: J19.2, Q13.3, R7.1
unnamed: J19.3, Q14.3, R50.1
unnamed: JP2.1, R13.2, U8.1
unnamed: JP3.1, R14.2, U8.30
unnamed: JP4.2, R18.2, U8.31
unnamed: JP6.2, U11.1
unnamed: Q1.3, R9.1, R11.1
unnamed: Q2.2, R10.2, R12.2, R28.2
unnamed: Q2.3, R16.1, R19.2
unnamed: Q3.2, R17.2, R20.2, R27.2
unnamed: Q3.3, R21.1, R24.2
unnamed: Q4.2, R22.2, R25.2, R26.2
unnamed: Q4.3, R29.1, R30.2
unnamed: R15.1, R23.1, U9.11, U9.12
unnamed: R39.2, U14.4
unnamed: R40.2, U13.1, U13.5
unnamed: R41.2, R42.2, U13.2, U13.3
unnamed: R45.2, R46.2, RV1.2
unnamed: R51.1, U9.6, U9.9
unnamed: TP1.1, U6.20
unnamed: TP4.1, U6.21
unnamed: TP7.1, U6.94
unnamed: U13.4, U14.3
unnamed: U13.15, U14.38
~MAGIC: J14.1, SW2.2, U6.84
~RST: C49.1, J17.1, SW3.2, U6.61

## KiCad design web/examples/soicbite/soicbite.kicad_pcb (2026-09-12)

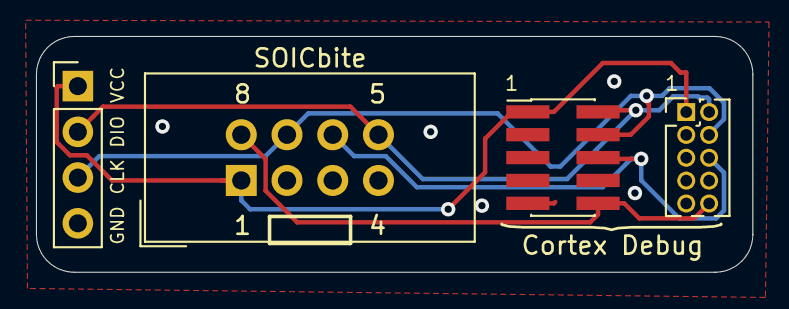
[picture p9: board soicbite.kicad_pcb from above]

Board: 2 copper layers, 39.8 x 13.1 mm, 4 parts (0 on the bottom side), 6 nets.

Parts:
J1: Conn_ARM_JTAG_SWD_10; PinHeader_2x05_P1.27mm_Vertical_SMD
J2: SOICBite IDC Header; IDC-Header_2x04_P2.54mm_Vertical
J3: Conn_01x04_Male; PinHeader_1x04_P2.54mm_Vertical
J4: Conn_ARM_JTAG_SWD_10; PinHeader_2x05_P1.27mm_Vertical

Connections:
/NRST: J1.10, J2.8, J4.10
/SWDCLK: J1.4, J2.7, J3.3, J4.4
/SWDIO: J1.2, J2.5, J3.2, J4.2
/SWO: J1.6, J2.6, J4.6
GND: J1.3, J1.5, J1.9, J2.4, J3.4, J4.3, J4.5, J4.9
VCC: J1.1, J2.1, J3.1, J4.1

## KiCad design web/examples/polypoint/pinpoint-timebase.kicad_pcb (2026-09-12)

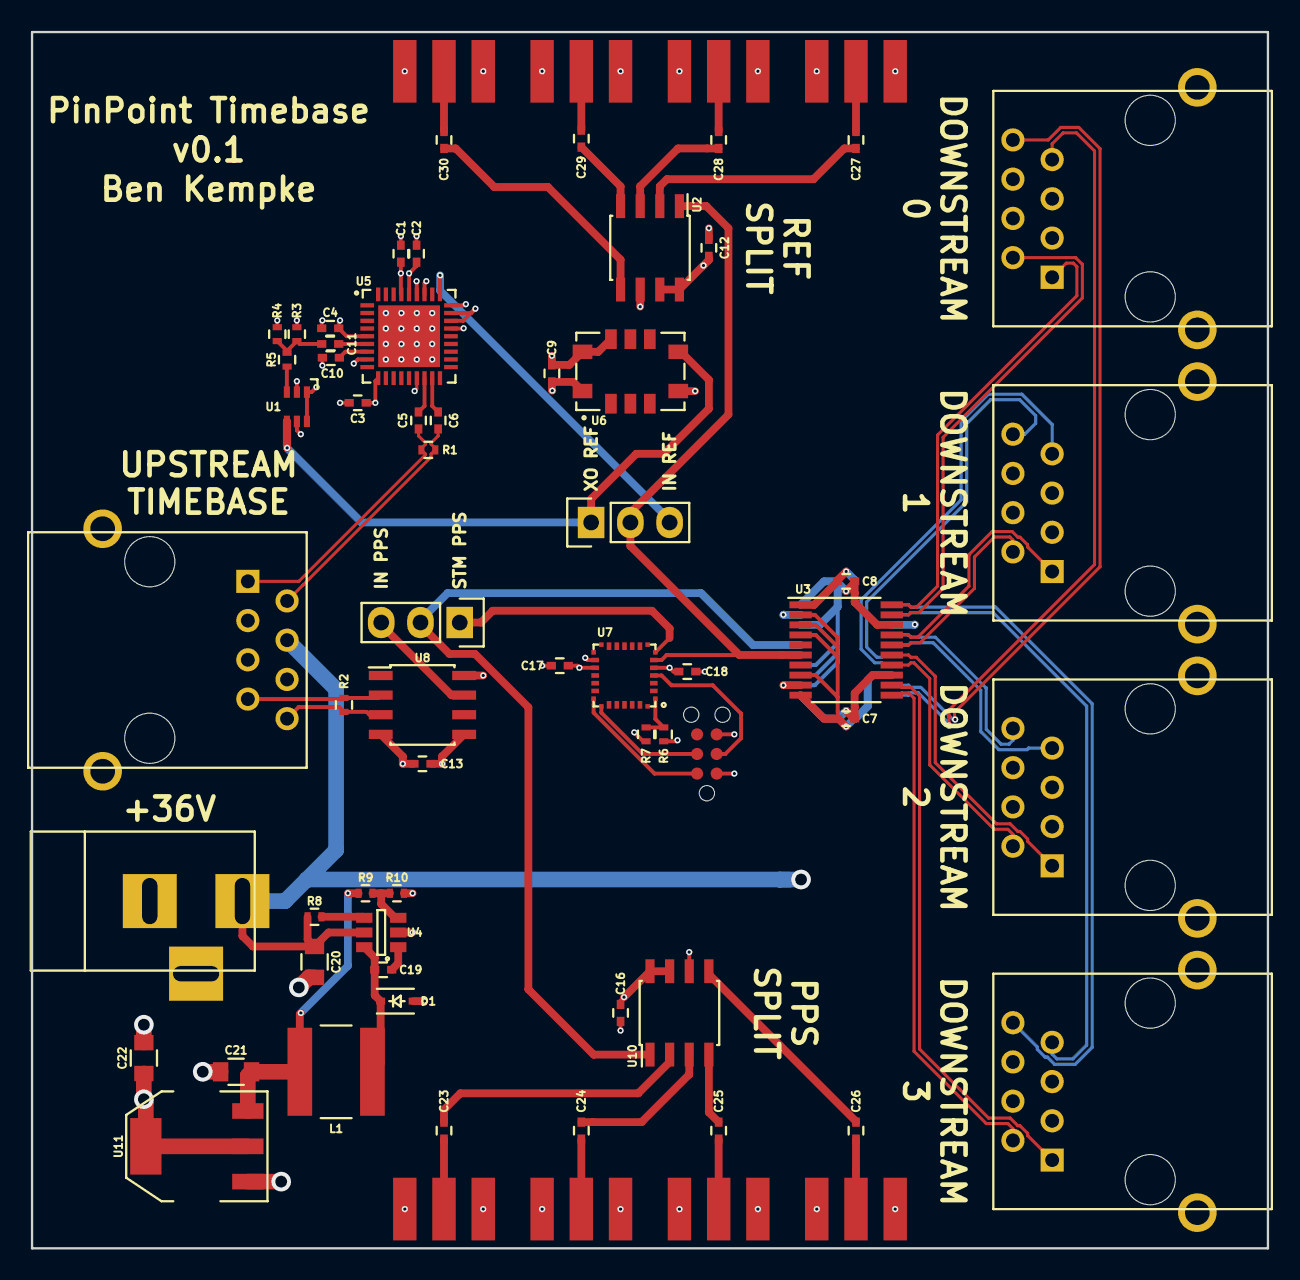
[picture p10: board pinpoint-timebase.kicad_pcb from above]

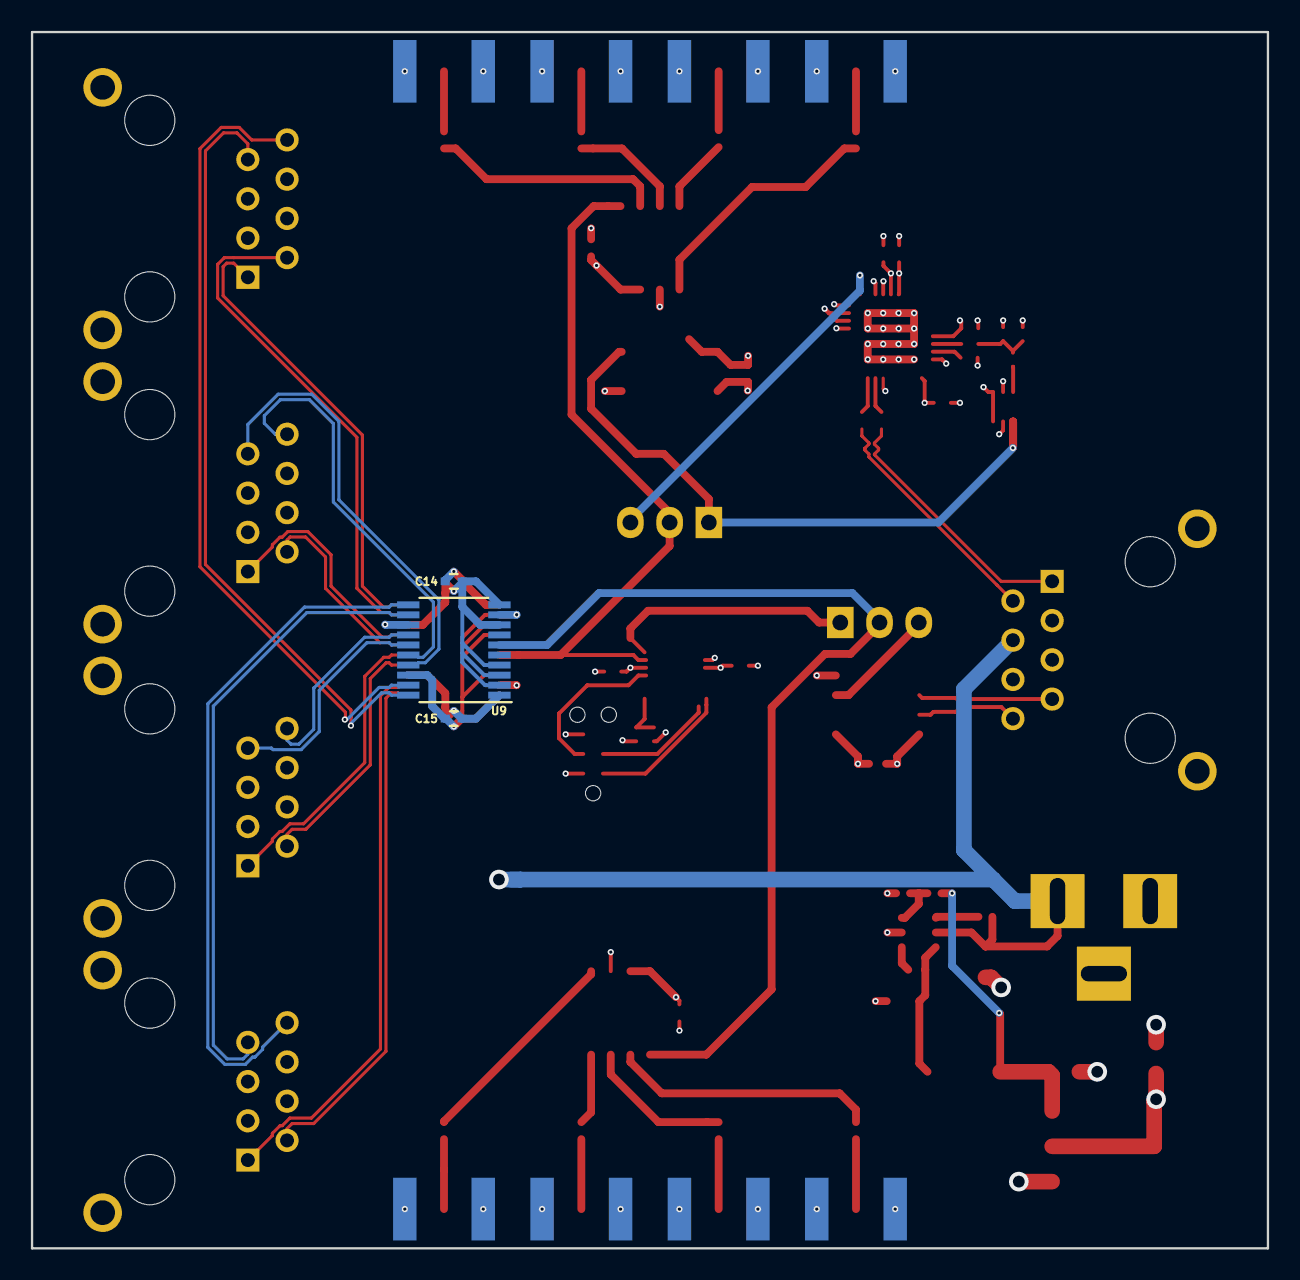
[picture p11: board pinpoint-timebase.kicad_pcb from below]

Board: 4 copper layers, 80.0 x 78.7 mm, 70 parts (3 on the bottom side), 60 nets.

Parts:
C1, C2, C3, C4, C5, C6, C7, C8, C9, C10, C11, C12, C13, C14, C15, C16, C17, C18, C19, C23, C24, C25, C26, C27, C28, C29, C30: 0.1uF; C_0402
C20: 4.7uF; C_0805
C21, C22: 10uF; C_0805
CON1: BARREL_JACK
D1: D_Schottky; SOD-323
J1, J2, J3, J4, J5: RJ45; RJ45_8
J6: TC2030-JLINK-NL; TC2030
L1: 22uH; NR6045
P1, P6: CONN_01X03; Pin_Header_Straight_1x03
P2, P3, P4, P5, P8, P9, P10: SMA; SMA_EDGE
R1, R2, R6, R7: R_Small; R_0402
R3, R4: 150; R_0402
R5: 130; R_0402
R8: 4.7K; R_0402
R9: 49.9K; R_0402
R10: 9.53K; R_0402
U1: SN74AVC1T45; SC-70-6
U2, U10: 551S; SOIC-8_3.9x4.9mm_Pitch1.27mm
U3, U9: ICS8545; TSSOP-20_4.4x6.5mm_Pitch0.65mm
U4: AOZ1282CI; SOT-23-6
U5: SI5317; QFN-36_1EP_6x6mm
U6: 7N-XX.XXXMBP-T; 7N-xx.xxxMBP-T
U7: STM32F031G4U6; UFQFPN-28
U8: 830S21; SOIC-8_3.9x4.9mm_Pitch1.27mm
U11: NCP1117; SOT-223
eP7: SMA; SMA_EDGE

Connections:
/CLK0+: J3.1, U3.20
/CLK0-: J3.2, U3.19
/CLK1+: J4.1, U3.17
/CLK1-: J4.2, U3.16
/CLK2+: J1.1, U3.15
/CLK2-: J1.2, U3.14
/CLK3+: J5.1, U3.12
/CLK3-: J5.2, U3.11
/IN_PPS+: J2.7, R2.1, U8.2
/IN_PPS-: J2.8, R2.2, U8.3
/IN_REF+: C5.2, J2.1, R1.1
/IN_REF-: C6.2, J2.2, R1.2
/PPS0+: J3.7, U9.20
/PPS0-: J3.8, U9.19
/PPS1+: J4.7, U9.17
/PPS1-: J4.8, U9.16
/PPS2+: J1.7, U9.15
/PPS2-: J1.8, U9.14
/PPS3+: J5.7, U9.12
/PPS3-: J5.8, U9.11
/REFTMP+: C5.1, U5.16
/REFTMP-: C6.1, U5.17
/SYS_CLK: P1.2, U2.1, U3.6, U7.6
GND: C1.2, C2.1, C3.2, C4.1, C7.2, C8.1, C9.2, C10.1, C12.2, C13.2, C14.2, C15.1, C16.2, C17.2, C18.1, C20.2, C21.2, C22.2, CON1.2, CON1.3, D1.2, J1.5, J1.9, J2.5, J2.9, J3.5, J3.9, J4.5, J4.9, J5.5, J5.9, J6.5, P2.2, P3.2, P4.2, P5.2, P8.2, P9.2, P10.2, R4.1, R7.2, R10.2, U1.2, U1.5, U2.6, U3.1, U3.9, U3.13, U4.2, U5.8, U5.15, U5.24, U5.27, U5.30, U5.31, U5.37, U6.4, U6.10, U7.16, U8.5, U9.1, U9.9, U9.13, U10.6, U11.1, eP7.2
unnamed: C10.2, U5.7
unnamed: C11.1, R3.1, R4.2, R5.2
unnamed: C11.2, U5.6
unnamed: C19.1, D1.1, L1.1, U4.6
unnamed: C19.2, U4.1
unnamed: C21.1, L1.2, R9.1, U11.3
unnamed: C23.1, U10.2
unnamed: C23.2, eP7.1
unnamed: C24.1, U10.3
unnamed: C24.2, P8.1
unnamed: C25.1, U10.4
unnamed: C25.2, P9.1
unnamed: C26.1, U10.5
unnamed: C26.2, P10.1
unnamed: C27.1, U2.2
unnamed: C27.2, P2.1
unnamed: C28.1, U2.3
unnamed: C28.2, P3.1
unnamed: C29.1, U2.4
unnamed: C29.2, P4.1
unnamed: C30.1, U2.5
unnamed: C30.2, P5.1
unnamed: J6.2, U7.21
unnamed: J6.3, U7.4
unnamed: J6.4, U7.22
unnamed: P1.1, U1.4, U6.5
unnamed: P1.3, U5.28
unnamed: P6.1, U7.7
unnamed: P6.2, U9.6, U10.1
unnamed: P6.3, U8.7
unnamed: R5.1, U1.3
unnamed: R6.1, R7.1, U7.1
unnamed: R8.2, U4.4
unnamed: R9.2, R10.1, U4.3
V3P3: C1.1, C2.2, C3.1, C4.2, C7.1, C8.2, C9.1, C12.1, C13.1, C14.1, C15.2, C16.1, C17.1, C18.2, C22.1, J6.1, R3.2, R6.2, U1.1, U1.6, U2.7, U2.8, U3.2, U3.3, U3.4, U3.8, U3.10, U3.18, U5.5, U5.10, U5.25, U5.26, U5.32, U5.33, U6.8, U6.9, U7.5, U7.17, U8.4, U8.8, U9.2, U9.3, U9.4, U9.8, U9.10, U9.18, U10.7, U10.8, U11.2, U11.4
VDD: C20.1, CON1.1, J1.4, J2.4, J3.4, J4.4, J5.4, R8.1, U4.5

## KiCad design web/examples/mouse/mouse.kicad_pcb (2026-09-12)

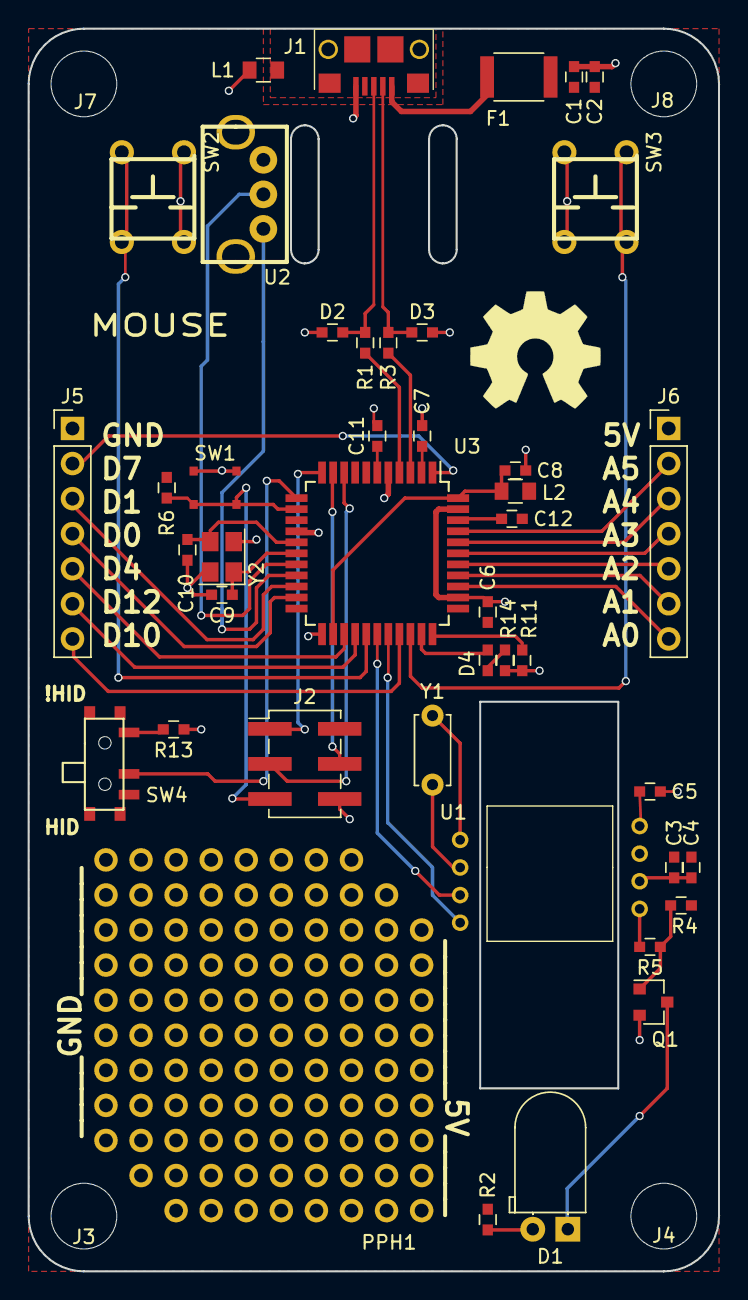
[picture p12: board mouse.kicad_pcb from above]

Board: 2 copper layers, 50.0 x 90.0 mm, 47 parts (0 on the bottom side), 47 nets.

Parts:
C1: 10uF; C_0603
C2, C4, C6, C7, C12: 0.1uF; C_0603
C3: 4.7uF; C_0603
C5: 2.2uF; C_0603
C8, C11: 1uF; C_0603
C9, C10: 18pF; C_0603
D1: D_Small; LED_D5.0mm_Horizontal_O1.27mm_Z3.0mm
D2, D3: CG0603MLC-05E; C_0603
D4: LED; C_0603
F1: MF-MSMF050-2; C_1812
J1: USB_OTG; 10118193_microUSB
J2: CONN_02X03; Pin_Header_Straight_2x03_Pitch2.54mm_SMD
J3, J4, J7, J8: NPTH; NPTH_1875
J5, J6: CONN_01X07; Pin_Header_Straight_1x07_Pitch2.54mm
L1, L2: MH2029-300Y; C_0805
PPH1: 104_PPH_Trapezoid; Mouse_PPH_Array
Q1: BC857ALT1G; SOT-23
R1, R3: 22R; C_0603
R2: 33R; C_0603
R4: 100K; C_0603
R5, R14: 1K; C_0603
R6, R11, R13: 10K; C_0603
SW1: PTS540 JM035 SMTR LFS; PTS540_Switch
SW2, SW3: LL3301DF065QJ; Mouse_Button
SW4: CJS1200; SSSS810701_ALPS_DPDT
U1: ADNS2610PTH; ADNS2610
U2: ENCODER-QUADRATURE; Mouse_Encoder
U3: ATMEGA32U4-MU; LQFP-44_10x10mm_Pitch0.8mm
Y1: 24MHz; C_Disc_D5.0mm_W2.5mm_P5.00mm
Y2: LFXTAL057485Cutt; Crystal_SMD_3225-4pin_3.2x2.5mm

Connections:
+5V: C1.1, C2.1, C3.1, C4.1, C6.1, C7.1, F1.2, J2.2, J6.1, L2.2, PPH1.27, PPH1.37, PPH1.47, PPH1.57, PPH1.67, PPH1.77, PPH1.87, PPH1.96, PPH1.104, R2.1, R4.2, R6.2, U1.7, U3.2, U3.7, U3.14, U3.34
/A0: J6.7, U3.36
/A1: J6.6, U3.37
/A2: J6.5, U3.38
/A3: J6.4, U3.39
/A4: J6.3, U3.40
/A5: J6.2, U3.41
/ADNS_SCK: U1.4, U3.29
/ADNS_SDIO: U1.3, U3.28
/D0/RX: J5.3, U3.20
/D1/TX: J5.4, U3.21
/D4: J5.5, U3.25
/D7: J5.2, U3.1
/D10: J5.7, U3.30
/D12: J5.6, U3.26
/D13: D4.2, U3.32
/D+: R1.1, U3.4
/D-: R3.1, U3.3
/HID_SELECT: SW4.2, U3.12
/HWB: R11.2, U3.33
/LEFT: SW2.3, SW2.4, U3.27
/MISO: J2.1, U3.11
/MOSI: J2.4, U3.10
/RESET: J2.5, R6.1, SW1.1, SW1.2, U3.13
/RIGHT: SW3.1, SW3.2, U3.31
/SCLK: J2.3, U3.9
/WHEEL_A: U2.A, U3.19
/WHEEL_B: U2.B, U3.18
Earth: J1.6, J1.7, J1.8, J1.9, J1.10, J1.11, L1.1
GND: C1.2, C2.2, C3.2, C4.2, C5.2, C6.2, C7.2, C8.2, C9.2, C10.2, C11.2, D2.2, D3.2, J1.5, J2.6, J5.1, L1.2, PPH1.1, PPH1.9, PPH1.18, PPH1.28, PPH1.38, PPH1.48, PPH1.58, PPH1.68, PPH1.78, Q1.2, R11.1, R13.1, R14.2, SW1.3, SW1.4, SW2.1, SW2.2, SW3.3, SW3.4, U1.6, U2.4, U2.5, U2.C, U3.5, U3.15, U3.23, U3.35, U3.43, Y2.2, Y2.4
unnamed: C5.1, U1.8
unnamed: C8.1, L2.1, U3.24, U3.44
unnamed: C9.1, U3.17, Y2.1
unnamed: C10.1, U3.16, Y2.3
unnamed: C11.1, U3.6
unnamed: C12.1, U3.42
unnamed: D1.1, Q1.3
unnamed: D1.2, R2.2
unnamed: D2.1, J1.3, R1.2
unnamed: D3.1, J1.2, R3.2
unnamed: D4.1, R14.1
unnamed: F1.1, J1.1
unnamed: Q1.1, R4.1, R5.1
unnamed: R5.2, U1.5
unnamed: R13.2, SW4.1
unnamed: U1.1, Y1.1
unnamed: U1.2, Y1.2

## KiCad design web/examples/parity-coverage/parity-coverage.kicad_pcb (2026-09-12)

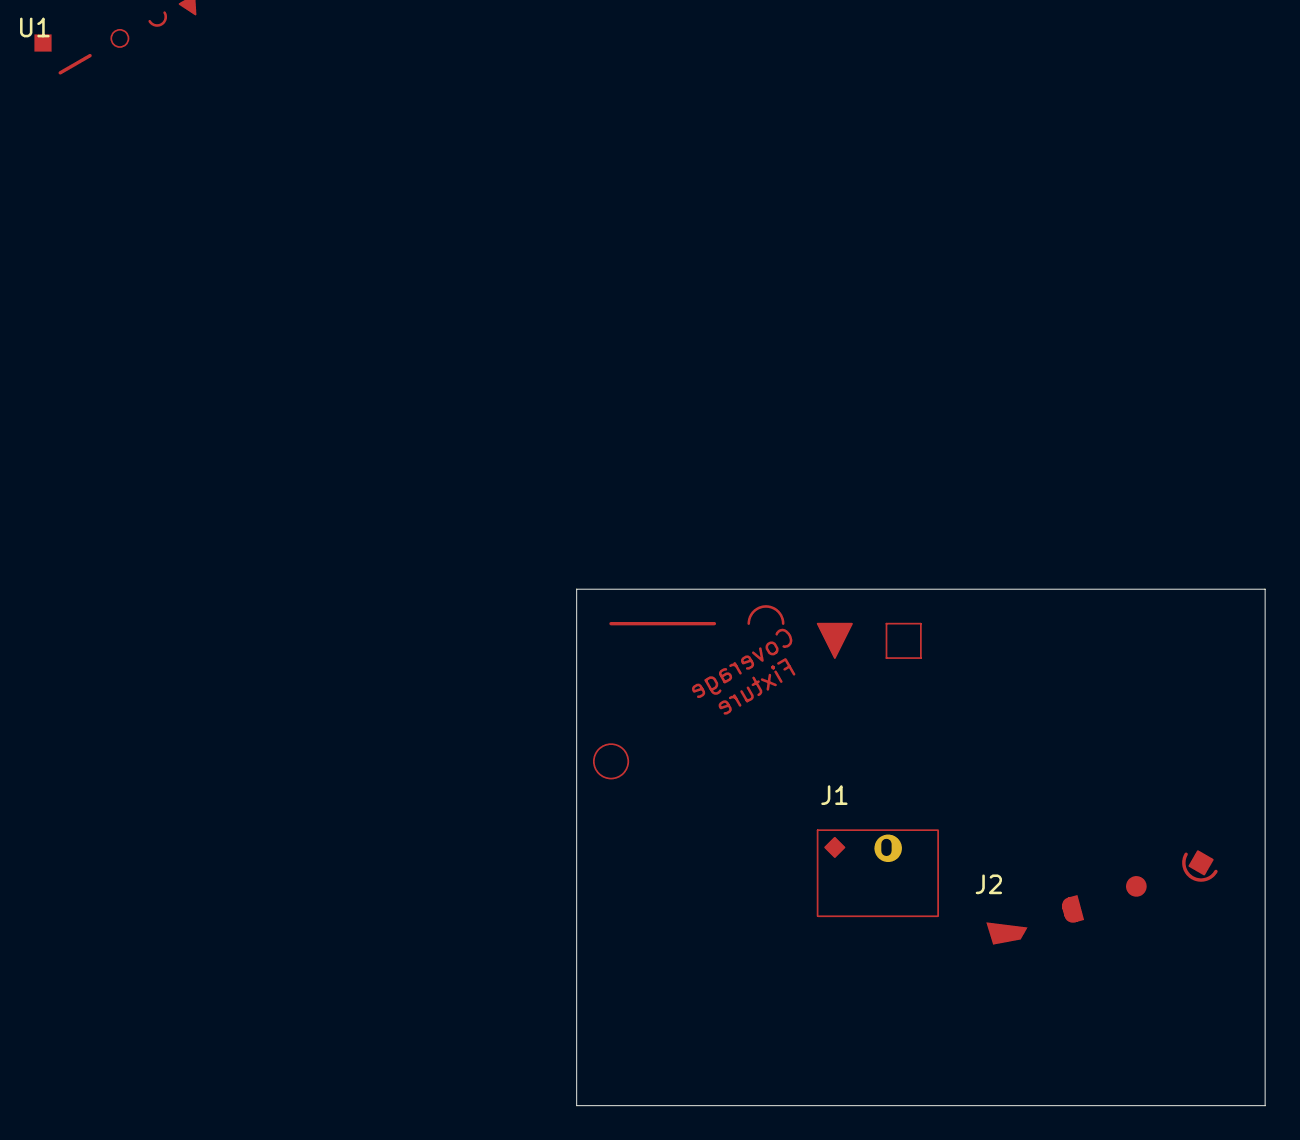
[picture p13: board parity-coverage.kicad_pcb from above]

Board: 2 copper layers, 40.0 x 30.0 mm, 3 parts (0 on the bottom side), 2 nets, no tracks yet.

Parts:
J1: CustomPad
J2: PadShapes
U1: CopperGraphics

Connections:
Return: J1.2, J2.2, J2.4
Signal: J1.1, J2.1, J2.3, U1.1

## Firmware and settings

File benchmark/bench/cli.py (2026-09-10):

"""`bench` command-line entry point."""
from __future__ import annotations

import json
import re
import subprocess
from datetime import datetime
from pathlib import Path

import click

from bench import compare as compare_mod
from bench import corpus, export as export_mod, metrics, paths, pool, referee, runner
from bench.candidates import load_candidates
from bench.report import html as html_report
from bench.report import markdown as md_report
from bench.report import plots as plots_report
from bench.report import pr as pr_report


def _require_kicad(boards: list[corpus.Board]) -> None:
    unsupported = sorted({b.id for b in boards if b.referee != "kicad"})
    if unsupported:
        raise click.ClickException(
            "KiCad reference unavailable for: " + ", ".join(unsupported)
            + "; DSN-only boards can be routed with --no-referee but cannot be scored")


@click.group()
def main() -> None:
    """Copperroute comparison suite."""


@main.group("corpus")
def corpus_cmd() -> None:
    """Manage the board corpus."""


@corpus_cmd.command("init")
@click.option("--fixtures", type=click.Path(exists=True, path_type=Path),
              default=paths.TEST_CORPUS, show_default=True)
def corpus_init(fixtures: Path) -> None:
    """Import the DSN fixtures of the test corpus."""
    boards = corpus.init_from_fixtures(fixtures)
    click.echo(f"imported {len(boards)} boards into {corpus.CORPUS / 'dsn'}")


@corpus_cmd.command("list")
@click.option("--tier", default=None)
def corpus_list(tier: str | None) -> None:
    for b in corpus.select(corpus.load_manifest(), tier=tier):
        click.echo(f"{b.id:40} nets={b.nets:4} layers={b.layers:2} referee={b.referee:8} tiers={','.join(b.tiers)}")


@corpus_cmd.command("pcbench")
@click.option("--clone", "root", type=click.Path(path_type=Path), required=True,
              help="PCBench checkout (cloned if missing)")
@click.option("--boards", "max_boards", type=int, default=None)
@click.option("--ids", default=None, help="comma-separated PCBench board dir names")
@click.option("--jobs", default=1, show_default=True,
             help="number of boards to import concurrently (each is an independent KiCad "
                  "subprocess pipeline in its own board directory).")
@click.option("--skip-existing/--force", default=True, show_default=True,
             help="skip boards already imported ok (manifest status ok + unrouted.dsn + "
                  "ground_truth.json on disk) so an interrupted import can resume; "
                  "--force re-imports everything.")
@click.option("--licensed-only", is_flag=True, default=False,
              help="import only boards whose metadata.json records a classified license; "
                   "unlicensed, unclassified and unknown boards are skipped.")
def corpus_pcbench_cmd(root: Path, max_boards, ids, jobs, skip_existing, licensed_only):
    """Import PCBench boards (strip -> DSN -> ground truth)."""
    if jobs < 1:
        raise click.ClickException("--jobs must be >= 1")
    # click.Path doesn't expand `~` itself, and this value often arrives with a literal,
    # unexpanded `~` (e.g. through scripts/remote-corpus.sh, where it must survive several
    # layers of shell quoting to reach the *remote* host's home directory) -- expand it here
    # against whatever process actually runs this command.
    root = root.expanduser()
    from bench import corpus_pcbench
    if not (root / "PCBs").exists():
        click.echo(f"cloning PCBench into {root} ...")
        subprocess.run(["git", "clone", "--depth", "1", "https://github.com/emshotton/PCBench", str(root)], check=True)
    boards = corpus_pcbench.import_boards(root, ids=ids.split(",") if ids else None, max_boards=max_boards,
                                          jobs=jobs, skip_existing=skip_existing, licensed_only=licensed_only,
                                          progress=click.echo)
    ok = sum(1 for b in boards if b.status == "ok")
    click.echo(f"imported {ok}/{len(boards)} boards")
    for b in boards:
        if b.status != "ok":
            click.echo(f"  excluded {b.id}: {b.reason}")


@corpus_cmd.command("kicad-fixtures")
@click.option("--fixtures", type=click.Path(exists=True, path_type=Path),
              default=paths.JAVA_REPO / "fixtures", show_default=True)
@click.option("--jobs", default=1, show_default=True,
             help="number of boards to import concurrently (each is an independent KiCad "
                  "subprocess pipeline in its own board directory).")
@click.option("--skip-existing/--force", default=True, show_default=True,
             help="skip boards already imported ok (manifest status ok + unrouted.dsn + "
                  "ground_truth.json on disk) so an interrupted import can resume; "
                  "--force re-imports everything.")
def corpus_kicad_fixtures_cmd(fixtures: Path, jobs: int, skip_existing: bool) -> None:
    """Import the Java repo's own KiCad fixture boards (strip -> DSN -> ground truth)."""
    if jobs < 1:
        raise click.ClickException("--jobs must be >= 1")
    from bench import corpus_pcbench
    boards = corpus_pcbench.import_kicad_fixtures(fixtures, jobs=jobs, skip_existing=skip_existing,
                                                   progress=click.echo)
    ok = sum(1 for b in boards if b.status == "ok")
    click.echo(f"imported {ok}/{len(boards)} boards")
    for b in boards:
        if b.status != "ok":
            click.echo(f"  excluded {b.id}: {b.reason}")


@corpus_cmd.command("revalidate")
@click.option("--origin", type=click.Choice(["pcbench", "freerouting-kicad"]), default="pcbench",
             show_default=True)
@click.option("--regenerate-projects", is_flag=True,
             help="regenerate raw.kicad_pro/stripped.kicad_pro from raw.orig.kicad_pcb for "
                  "boards whose project was bench-generated (ground_truth.project_generated), "
                  "so a vendor/kicad/legacy_rules.py fix is picked up without a full re-import.")
@click.option("--rerun-drc", is_flag=True,
             help="re-run kicad-cli pcb drc on raw.kicad_pcb (against the possibly "
                  "just-regenerated project) and rewrite raw-drc.json before recomputing; "
                  "needs kicad-cli. Without this flag, only boards with an existing "
                  "raw-drc.json are touched and no KiCad install is needed at all.")
@click.option("--jobs", default=1, show_default=True,
             help="boards to revalidate concurrently; only matters with --rerun-drc, since the "
                  "plain recompute is pure local file I/O.")
def corpus_revalidate_cmd(origin: str, regenerate_projects: bool, rerun_drc: bool, jobs: int) -> None:
    """Recompute drv_routing/drv_all/unconnected/reference_complete (and, optionally, the
    generated project and/or DRC report) for every already-imported --origin board from what's
    on disk, and re-apply the reference-board exclusion rule to the manifest -- without
    re-running the full strip -> DSN -> DRC -> stats import pipeline."""
    if jobs < 1:
        raise click.ClickException("--jobs must be >= 1")
    from bench import corpus_pcbench
    try:
        summary = corpus_pcbench.revalidate(origin, progress=click.echo,
                                            regenerate_projects=regenerate_projects,
                                            rerun_drc=rerun_drc, jobs=jobs)
    except paths.ToolMissing as e:
        raise click.ClickException(str(e)) from e
    click.echo(f"checked {summary['checked']} {origin} board(s), {summary['skipped']} skipped"
              + (f", {summary['regenerated_projects']} project(s) regenerated" if regenerate_projects else "")
              + (f", {summary['reran_drc']} DRC re-run(s)" if rerun_drc else ""))
    if summary["ok_to_excluded"]:
        by_reason: dict[str, int] = {}
        for _bid, reason in summary["ok_to_excluded"]:
            key = re.sub(r"\d+", "N", reason)
            by_reason[key] = by_reason.get(key, 0) + 1
        click.echo(f"ok -> excluded: {len(summary['ok_to_excluded'])}")
        for reason, n in sorted(by_reason.items()):
            click.echo(f"  {n}x {reason}")
    if summary["excluded_to_ok"]:
        click.echo(f"excluded -> ok: {len(summary['excluded_to_ok'])}")
        for bid in summary["excluded_to_ok"]:
            click.echo(f"  {bid}")


@main.command("run")
@click.option("--candidates", "cand_names", required=True, help="comma-separated names from candidates.toml")
@click.option("--candidates-file", "candidates_file", envvar="BENCH_CANDIDATES",
             type=click.Path(exists=True, path_type=Path), default=None,
             help="candidates TOML file to load --candidates from (also settable via $BENCH_CANDIDATES; "
                  "default: candidates.toml next to this repo's pyproject.toml); relative exec paths in "
                  "it resolve relative to the file's own directory. Used by scripts/remote-run.sh to "
                  "point at candidates.remote.toml on hosts without the Java repo checkout.")
@click.option("--tier", default=None)
@click.option("--boards", "board_ids", default=None, help="comma-separated board ids")
@click.option("--seeds", type=click.IntRange(min=1), default=1, show_default=True,
              help="repetitions per board; {seed} in candidate extra_args receives the repetition index")
@click.option("--max-passes", default=100, show_default=True)
@click.option("--timeout", "timeout_s", default=300, show_default=True)
@click.option("--threads", type=click.IntRange(min=1), default=1, show_default=True)
@click.option("--jobs", default=1, show_default=True,
             help="number of cells (candidate x board x seed) to run concurrently. "
                  "Use --jobs 1 for controlled quality and "
                  "wall-time numbers -- with --jobs > 1, `compare` falls back to CPU time "
                  "since wall time is contended. Rule of thumb (~1.5 GB RSS per Java cell): "
                  "4 on a 10-core/16 GB laptop, 8-12 on a 16-core/64 GB workstation.")
@click.option("--run-id", default=None)
@click.option("--no-referee", is_flag=True)
def run_cmd(cand_names, candidates_file, tier, board_ids, seeds, max_passes, timeout_s, threads, jobs,
           run_id, no_referee):
    """Route boards with candidates and score the results."""
    if jobs < 1:
        raise click.ClickException("--jobs must be >= 1")
    candidates_file = Path(candidates_file) if candidates_file else paths.ROOT / "candidates.toml"
    try:
        chosen = list(load_candidates(candidates_file, cand_names.split(",")).values())
    except KeyError as e:
        raise click.ClickException(f"unknown candidate: {e.args[0]}") from e
    except (FileNotFoundError, paths.ToolMissing, ValueError) as e:
        raise click.ClickException(str(e)) from e
    try:
        boards = corpus.select(corpus.load_manifest(), tier=tier,
                               ids=board_ids.split(",") if board_ids else None)
    except KeyError as e:
        raise click.ClickException(e.args[0]) from e
    if not no_referee:
        if board_ids:
            _require_kicad(boards)
        else:
            skipped = len(boards)
            boards = [b for b in boards if b.referee == "kicad"]
            skipped -= len(boards)
            if skipped:
                click.echo(f"skipping {skipped} boards without a KiCad reference")
    if not boards:
        raise click.ClickException("no boards selected" + (" with a KiCad reference" if not no_referee else ""))
    missing = [b.id for b in boards if not b.path.exists()]
    if missing:
        raise click.ClickException(
            "missing board input file(s) for: " + ", ".join(missing)
            + " -- run `bench corpus init` / `bench corpus kicad-fixtures` (or `bench corpus pcbench`)")
    run_id = run_id or datetime.now().strftime("%Y%m%d-%H%M%S")
    cfg = runner.RunConfig(run_id=run_id, candidates=chosen, boards=boards, seeds=seeds,
                           max_passes=max_passes, timeout_s=timeout_s, threads=threads, jobs=jobs, tier=tier,
                           candidates_file=str(candidates_file.resolve()))
    hook = None
    if not no_referee:
        hook = referee.score_cell
    try:
        run_dir = runner.run(cfg, referee=hook, progress=click.echo)
    except FileExistsError as e:
        raise click.ClickException(f"run already exists: {run_id}; choose a new --run-id") from e
    click.echo(f"run written to {run_dir}")


@main.command("referee")
@click.option("--run", "run_id", required=True)
@click.option("--only-missing", is_flag=True, help="skip cells that already have metrics.json")
@click.option("--jobs", default=1, show_default=True,
             help="number of cells to re-score concurrently. Needs only the run's manifest and "
                  "results -- no candidates.toml.")
def referee_cmd(run_id: str, only_missing: bool, jobs: int) -> None:
    """(Re)score every cell of a run."""
    if jobs < 1:
        raise click.ClickException("--jobs must be >= 1")
    run_dir = runner.RESULTS / run_id
    meta = runner.load_meta(run_dir)
    boards = {b.id: b for b in corpus.load_manifest()}
    todo = []
    for c in meta["cells"]:
        cell = runner.cell_dir(run_dir, c["candidate"], c["board"], c["seed"])
        if only_missing and (cell / "metrics.json").exists():
            continue
        todo.append((c, cell))

    if only_missing and meta.get("referee_rescore", {}).get("status") == "incomplete":
        raise click.ClickException("full rescore is incomplete; rerun without --only-missing")
    if not todo:
        click.echo("scored 0 cells: nothing left to score")
        return

    _require_kicad([boards[c["board"]] for c, _ in todo])
    if not only_missing:
        meta["referee_rescore"] = {"status": "incomplete", "referee": "kicad"}
        runner._save_meta(run_dir, meta)

    def _score(item: tuple[dict, Path]) -> tuple[dict, dict, str | None]:
        c, cell = item
        board = boards[c["board"]]
        try:
            return c, referee.score_cell(board, cell), None
        except Exception as e:
            # One bad cell must not abort the rest of the pass -- especially under jobs > 1,
            # where other cells may already be scoring concurrently in other worker threads.
            # Same fallback the runner uses for a referee hook that raises.
            reason = f"referee raised {type(e).__name__}: {e}"
            r = {"status": "referee_failed", "referee": board.referee, "reason": reason,
                 "candidate_output": (cell / "out.ses").exists()}
            (cell / "referee.json").write_text(json.dumps(r, indent=2) + "\n")
            return c, metrics.build(cell, board), reason

    def _print(result: tuple[dict, dict, str | None]) -> None:
        c, m, error = result
        if error:
            click.echo(f"{c['candidate']:16} {c['board']:32} seed {c['seed']}: ERROR {error}")
        else:
            click.echo(f"{c['candidate']:16} {c['board']:32} seed {c['seed']}: "
                       f"unrouted={m['unrouted']} viol={m['violations']} score={m['score']:.1f}"
                       + (" DISAGREE" if m["disagreement"] else "") + (" FAILED" if m["failed"] else ""))

    # Results are printed (via on_done) in submission order from the main thread, same
    # pattern as `run` uses for meta.json -- regardless of which worker finishes first.
    results = pool.run_cells(todo, _score, jobs, on_done=_print)

    if not only_missing:
        meta["referee_rescore"]["status"] = "complete"
    runner._save_meta(run_dir, meta)

    scored = len(results)
    clean = sum(1 for _, m, _ in results if m["clean_pass"])
    failed = sum(1 for _, m, error in results if error or m["failed"])
    disagree = sum(1 for _, m, _ in results if m["disagreement"])
    click.echo(f"scored {scored} cells: {clean} clean pass, {failed} failed, {disagree} disagreements")


def _latest_run_for(name: str) -> Path:
    runs = sorted(runner.RESULTS.glob("*/meta.json"), key=lambda p: p.stat().st_mtime, reverse=True)
    for m in runs:
        if any(c["name"] == name for c in json.loads(m.read_text())["candidates"]):
            return m.parent
    raise click.ClickException(f"no run contains candidate {name}")


@main.command("compare")
@click.option("--baseline", required=True)
@click.option("--against", required=True, help="comma-separated candidate names")
@click.option("--runs", default=None, help="comma-separated run ids (default: latest run per candidate)")
@click.option("--tier", default=None)
@click.option("--out", "out_name", default=None)
@click.option("--allow-mixed", is_flag=True)
@click.option("--fail-on-regression", is_flag=True,
              help="exit nonzero for routing-quality losses or no comparable boards; timing/RSS are advisory by default")
@click.option("--require-complete", is_flag=True,
              help="with --fail-on-regression, also require every shared board and planned repetition")
@click.option("--performance-regression-percent", type=click.FloatRange(min=0, min_open=True), default=None,
              help="opt in to time/RSS gating above this percent and a noise allowance; "
                   "with --fail-on-regression, fewer than 3 measured samples per side also fails the gate")
@click.option("--time-metric", "time_metric", type=click.Choice(["auto", "wall", "cpu"]), default="auto",
             show_default=True,
             help="which time metric decides verdicts and median_time_ratio. 'auto' uses wall time "
                  "when every compared run used --jobs 1, else falls back to CPU time (wall time is "
                  "contended once cells run concurrently).")
def compare_cmd(baseline, against, runs, tier, out_name, allow_mixed, fail_on_regression, require_complete, performance_regression_percent, time_metric):
    """Compare candidates and write reports/<id>.{json,md,pr.md,html}."""
    names = against.split(",")
    if runs:
        ids = runs.split(",")
        missing = [r for r in ids if not (runner.RESULTS / r / "meta.json").exists()]
        if missing:
            raise click.ClickException(f"unknown run id(s): {', '.join(missing)}")
        run_dirs = [runner.RESULTS / r for r in ids]
    else:
        run_dirs = []
        for n in [baseline, *names]:
            rd = _latest_run_for(n)
            if rd not in run_dirs:
                run_dirs.append(rd)
    try:
        cmp = compare_mod.compare(run_dirs, baseline, names, corpus.load_manifest(), tier=tier,
                                  allow_mixed=allow_mixed, time_metric=time_metric,
                                  performance_regression_percent=performance_regression_percent)
    except compare_mod.IncompatibleRuns as e:
        raise click.ClickException(str(e)) from e
    out_name = out_name or f"{datetime.now().strftime('%Y%m%d-%H%M%S')}-{baseline}-vs-{'-'.join(names)}"
    paths.REPORTS.mkdir(exist_ok=True)
    (paths.REPORTS / f"{out_name}.json").write_text(json.dumps(cmp, indent=2) + "\n")
    (paths.REPORTS / f"{out_name}.md").write_text(md_report.render(cmp))
    (paths.REPORTS / f"{out_name}.pr.md").write_text(pr_report.render(cmp, out_name))
    (paths.REPORTS / f"{out_name}.html").write_text(html_report.render(cmp, html_report.load_history(paths.REPORTS)))
    for n in names:
        click.echo(f"{n} vs {baseline}: {cmp['overall'][n]['verdict']} "
                   f"({cmp['overall'][n]['wins']}W/{cmp['overall'][n]['losses']}L/{cmp['overall'][n]['ties']}T)")
    for name, cov in cmp["coverage"].items():
        click.echo(f"{name}: compared {cov['compared_boards']}/{len(cov['shared_boards'])} shared boards; "
                   f"{len(cov['incomplete_boards'])} incomplete, {len(cov['skipped_boards'])} skipped")
    click.echo(f"reports written to {paths.REPORTS / out_name}.{{json,md,pr.md,html}}")
    click.echo(f"paste into a pull request: uv run bench pr-summary --compare {out_name}")
    if fail_on_regression:
        reasons = compare_mod.gate_failures(cmp, require_complete=require_complete)
        if reasons:
            raise click.ClickException("regression check failed; see the comparison report:\n"
                                       + "\n".join(f"  {r}" for r in reasons))



@main.command("report")
@click.option("--compare", "compare_id", required=True)
def report_cmd(compare_id: str) -> None:
    """Regenerate the Markdown, pull-request and HTML reports from a compare JSON."""
    cmp = json.loads((paths.REPORTS / f"{compare_id}.json").read_text())
    (paths.REPORTS / f"{compare_id}.md").write_text(md_report.render(cmp))
    (paths.REPORTS / f"{compare_id}.pr.md").write_text(pr_report.render(cmp, compare_id))
    (paths.REPORTS / f"{compare_id}.html").write_text(html_report.render(cmp, html_report.load_history(paths.REPORTS)))
    click.echo(f"wrote {paths.REPORTS / compare_id}.{{md,pr.md,html}}")


@main.command("pr-summary")
@click.option("--compare", "compare_id", required=True,
              help="a compare id under reports/, without the extension")
def pr_summary_cmd(compare_id: str) -> None:
    """Print a short Markdown summary of a comparison, for pasting into a pull request."""
    path = paths.REPORTS / f"{compare_id}.json"
    if not path.exists():
        raise click.ClickException(f"no comparison at {path}; run `bench compare` first")
    click.echo(pr_report.render(json.loads(path.read_text()), compare_id), nl=False)
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

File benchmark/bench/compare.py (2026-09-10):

"""Compare routing quality before speed, using repeated runs to estimate noise."""
from __future__ import annotations

import json
import statistics
from datetime import datetime, timezone
from pathlib import Path

from bench import metrics, referee, runner
from bench.corpus import Board

NUMERIC = ["unrouted", "violations", "vias", "wirelength_mm", "score", "wall_s", "cpu_s",
           "peak_rss_mb", "passes", "wirelength_ratio", "via_ratio"]
HARD_LEVELS = {"clean_pass_rate", "unrouted", "violations"}
NOISE_FACTOR = 2.0
DEFAULT_TIME_METRIC = "wall_s"


def _levels(time_metric: str = DEFAULT_TIME_METRIC) -> list[tuple[str, bool]]:
    """(metric, higher_is_better) in verdict order. Level 5 (time) is whichever metric
    the comparison chose -- wall_s when every run in it used jobs=1, else cpu_s, since
    wall time is contended and no longer a fair signal once cells run concurrently."""
    return [("clean_pass_rate", True), ("unrouted", False), ("violations", False),
            ("score", True), (time_metric, False), ("peak_rss_mb", False)]


class IncompatibleRuns(ValueError):
    pass


def _median(values: list) -> float | None:
    vals = [v for v in values if v is not None]
    return statistics.median(vals) if vals else None


def aggregate(cells: list[dict]) -> dict:
    agg = {"n": len(cells), "clean_pass_rate": sum(1 for c in cells if c.get("clean_pass")) / len(cells) if cells else 0.0,
           "failed": sum(1 for c in cells if c.get("failed"))}
    for k in NUMERIC:
        agg[k] = _median([c.get(k) for c in cells])
    return agg


def noise(cells: list[dict]) -> dict[str, float]:
    out: dict[str, float] = {"clean_pass_rate": 0.0}
    for k in NUMERIC:
        vals = [c.get(k) for c in cells if c.get(k) is not None]
        out[k] = statistics.stdev(vals) if len(vals) >= 3 else 0.0
    return out


def verdict(base: dict, other: dict, noise_floor: dict[str, float],
           time_metric: str = DEFAULT_TIME_METRIC) -> dict:
    levels = _levels(time_metric)
    last = levels[-1][0]
    for metric, higher_better in levels:
        b, o = base.get(metric), other.get(metric)
        if b is None or o is None:
            continue
        band = NOISE_FACTOR * noise_floor.get(metric, 0.0)
        if abs(o - b) <= band:
            continue
        better = o > b if higher_better else o < b
        return {"result": "win" if better else "loss", "level": metric}
    return {"result": "tie", "level": last}


def collect(run_dirs: list[Path], names: list[str], metas: dict | None = None) -> tuple[dict, dict, list[str]]:
    """Return (cells[cand][board] -> list[metrics], cand_info[cand], warnings)."""
    cells: dict[str, dict[str, list[dict]]] = {n: {} for n in names}
    info: dict[str, dict] = {}
    warnings: list[str] = []
    unisolated = False
    identities = {}
    for rd in run_dirs:
        meta = metas[rd] if metas is not None else runner.load_meta(rd)
        rescoring = meta.get("referee_rescore", {}).get("status") == "incomplete"
        if rescoring:
            warnings.append(f"{meta['run_id']}: full referee rescore is incomplete; rerun bench referee without --only-missing")
        for c in meta["candidates"]:
            if c["name"] in names:
                identity = (c["sha"], c.get("kind"), c.get("extra_args", []))
                if c["name"] in identities and identities[c["name"]] != identity:
                    raise IncompatibleRuns(
                        f"candidate {c['name']} has different commits or settings across runs; "
                        "use distinct candidate names for baseline and change")
                identities[c["name"]] = identity
                info[c["name"]] = {"sha": c["sha"], "version": c.get("version", "")}
        selected = set(names) & {c["name"] for c in meta["candidates"]}
        for e in meta["cells"]:
            if e["candidate"] not in selected:
                continue
            mp = runner.cell_dir(rd, e["candidate"], e["board"], e["seed"]) / "metrics.json"
            if mp.exists():
                m = json.loads(mp.read_text())
                m["_run"], m["_seed"], m["_candidate"] = meta["run_id"], e["seed"], e["candidate"]
                if rescoring:
                    m["unjudged"] = True
                if not m.get("isolated_config", False):
                    unisolated = True
                cells[e["candidate"]].setdefault(e["board"], []).append(m)
    if unisolated:
        warnings.append("results may be affected by shared freerouting.json — rerun")
    return cells, info, warnings


def _arg(args: dict, key: str):
    if key == "jobs":
        return args.get("jobs", 1)
    return args.get(key)


def _check_config(metas: dict[Path, dict], allow_mixed: bool) -> tuple[dict, list[str]]:
    configs = [(rd.name, meta["args"]) for rd, meta in metas.items()]
    keys = ["threads", "jobs", "max_passes", "timeout_s"]
    first_name, first = configs[0]
    warnings = []
    for name, args in configs[1:]:
        if any(_arg(args, k) != _arg(first, k) for k in keys):
            msg = f"incompatible runs: {first_name} has config {first!r} but {name} has config {args!r}"
            if not allow_mixed:
                raise IncompatibleRuns(msg)
            warnings.append(msg)
    hosts = [meta.get("host") for meta in metas.values() if meta.get("host")]
    if hosts and any(host != hosts[0] for host in hosts[1:]):
        warnings.append(f"host metadata differs: {hosts!r}; verify the measurements used the same hardware")
    seeds = sorted({args.get("seeds", 1) for _, args in configs})
    if len(seeds) > 1:
        warnings.append(f"different repetition counts across runs: {seeds}; noise uses actual baseline samples per board")
    config = {k: _arg(first, k) for k in keys}
    config.update(seeds=seeds[0] if len(seeds) == 1 else None, repetition_counts=seeds)
    return config, warnings


def _resolve_time_metric(metas: dict[Path, dict], time_metric: str) -> str:
    if time_metric in ("wall", "wall_s"):
        return "wall_s"
    if time_metric in ("cpu", "cpu_s"):
        return "cpu_s"
    if time_metric != "auto":
        raise ValueError(f"unknown time_metric: {time_metric!r}")
    return "wall_s" if all(m["args"].get("jobs", 1) == 1 for m in metas.values()) else "cpu_s"


def _judged(cells: list[dict]) -> list[dict]:
    """Exclude referee failures from routing verdicts; retain them in coverage and failures."""
    return [c for c in cells if not c.get("unjudged")]
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

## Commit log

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2026-08-28 test(parity): generate Java reference outputs via a jar-linked driver
    -de/-do cannot produce unrouted references (headless writer emits SES/JSON only;
    -mp 0 means unlimited; --router.enabled=false leaves fanout/optimizer running;
    disabling all three writes nothing). RefWriter.java links against the pinned
    2.3.0 jar and calls DsnReader -> DsnWriter/SesWriter directly. Adds headless
    JVM flags. References for the four Plan-1 fixtures committed (0 wires each).
    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
    [roundtrip.dsn]
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2026-08-28 feat(dsn): network scope — nets, via infos/rules, classes, component and pin insertion
    `Network.readScope` (Network.java:1197-1323) and its whole insertion tail, in
    Java's order: merge the net classes' `use_via` names into
    `ReadScopeParameter.viaPadstackNames` and `setViaPadstacks` the resolved list,
    then insertViaInfos, insertViaRules, insertNetClasses, insertClassPairs,
    insertComponents (per component: one insert_pin per package pin, then the
    package/via/place keepouts, then the component outlines) and
    insertLogicalParts. That order fixes every item id after the board outline,
    which is what the tests assert.
    Also `Network.readNetScope`/`readNetPins`/`createOrderedSubnets`/`readViaInfo`/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
    [alias.dsn, class_pair.dsn, via_order.dsn]
2026-08-28 fix(dsn): Task 9 review round 1 — pin the skipped-setViaPadstacks branch, tag the untagged
    Review item 1 (Important). `tests/data/network_via.dsn`: a `structure` with no
    `(via …)`, no `(class …)` anywhere, and two `(via <name> <padstack> default)`
    infos in the `network` scope. `ReadScopeParameter.viaPadstackNames` therefore
    stays `null`, the `!= null` guard at Network.java:1286 skips `setViaPadstacks`
    entirely, and the padstacks `Network.readViaInfo` appended through
    `addViaPadstack` (:274) survive — Java's `viapadstacks[2] VA VB`. Golden
    captured with the same NProbe command as the others and recorded in its header.
    Verified the test does what it is for: forcing the reader back onto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
    [network_via.dsn]
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2026-08-29 fix(dsn): Task 10 review round 1 — tryCorrectNet contact order, insertVia obligation, citations
    Review item 1 (important). `Wiring.tryCorrectNet` (Wiring.java:583-599) walks a
    `TreeSet<Item>` — **descending** id (quirk #44) — and `break`s on the first
    single-net contact, so a netless wire takes the net of the **highest-id** item
    it touches. The port's `BTreeSet` iterates ascending; the walk is now
    `.rev()`ed. New fixture `wiring_try_correct_net.dsn` makes the two directions
    disagree (a netless `(wire …)` between two single-pin components on different
    nets) and `try_correct_net_takes_the_highest_id_contact` pins the JVM's answer
    — `nets=[2,]`, the higher-id pin's net. Verified RED w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
    [wiring_try_correct_net.dsn]
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2026-08-29 test(dsn): tests/reference — three trace/via/plane fixtures (ruling G)
    The four committed references leave six writers untested: between them they
    have zero `polyline_path`, zero wiring `(via `, zero
    `(type shove_fixed|fix|protect)` and zero `(plane `. Controller ruling G adds
    three stems that cover all four, generated with the committed
    `scripts/gen-reference.sh` against the pinned 2.3.0 jar (JDK 25, headless):
    Issue413-test 11 polyline_path, 4 wiring vias, 3 fixed states 8,492 B
    (and the only .ses reference with `(wire` entries — 11)
    Issue110-RelayModule 22 wiring vias, 22 fixed states 171,349 B
    Issue753-CPU-85_r104 3 (plane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
    [roundtrip.dsn]
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2026-08-29 fix(settings): Task 11 carry-forward — citations, two branches, the p4t1 loose ends
    The deferred minors from the Tasks 4-9 reviews, plus the pre-existing clippy
    warning in the differential package. Nothing changes behaviour except the
    `p4t1` driver's design-name fallback and one matrix row.
    Wrong Java line numbers, all re-read at the clone's HEAD. A script that
    recomputes each `@Test`'s real span found nine bad citations; each is now the
    method's actual range, and the two that deliberately cite a *fragment* say so:
    BendCostSettingsTest.setGetBendCost :20-42 -> :20-43
    BendCostSettingsTest.nullScoringSafety :61-83 -> :61-114 (ported to :83)
    NeckWidthSettingsT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
    [p4t1-cases.tsv]
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2026-09-02 feat(cli): the legacy shim rewired to fr-settings, bug-for-bug, with Java's exit ladder
    `crates/freerouting/src/legacy.rs` no longer reproduces any of Java's parse rules.
    It is a mode and slot resolver over `GlobalSettings.applyCommandLineArguments`
    (`:521-838`): the `-de` rule is `fr_settings::classify_de_arguments_reporting`
    (plan-4 ruling 10), the `i++`-after-a-throw rule is
    `fr_settings::legacy_flag_value_is_consumed`, and the values themselves reach the
    router only through `CliSettings` over the RAW argv — two parsers, not one (scan
    ruling R19), so `-mpx 5` sets `max_passes` on neither and `-decoy a.dsn` sets the
    design input on both. `LegacyError` and its four variants are deleted: n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
    [p8t5-argv.tsv]
2026-09-02 fix(cli): Task 5 review round 1 — SF1-SF5 and four nits
    SF1 json_file.rs's `a_router_object_the_reader_rejects_is_swallowed` claimed Java's
    `catch` at :58 "makes the two agree on the outcome". False: quirk #141 block D
    records `{"max_passes": "42"} -> 42` — Gson coerces, it does not throw. The
    comment now states the divergence (Java answers 42, the port contributes nothing
    at priority 10) and says :55-62 bounds it rather than removing it.
    SF2 `ExitCode::NotImplemented`'s doc contained the literal old identifier, so Task 14's
    grep gate tripped on the comment written to defuse it. Reworded to name it
    descriptively, and it now points at the controller's repl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
    [p8t5-argv.tsv]
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2026-09-02 test(dsn): directed fixtures for the four zero-coverage Plan 3 paths
    Plan 3 shipped four ported paths that nothing executed — not the 530-pair
    `sweep-p3t15.sh`, not the seven `tests/reference` fixtures, not the 105-file
    corpus test. `docs/plan-3-handoff.md`'s register row names them:
    `SesWriter.writeWasIs`'s swap body, `Component.readLockType`'s
    `(lock_type position)` arm, `SesWriter.writeConductionArea` (quirk #110's mixed
    int/double output) and quirk #105 (`Wiring.readViaScope`'s net-number loop that
    never increments). Each now has a directed synthetic fixture, JVM ground truth
    and a named test.
    Coverage only: no `src/` file is touched, no type is declared, no signature
    changes. Every f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
    [p8t13-conduction-area.dsn, p8t13-lock-type.dsn, p8t13-via-net-numbers.dsn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]
2026-09-02 test(dsn): commit the quirk-#105 control fixture, not just its prose
    Task 13 review nit. The claim that isolates quirk #105's jar hang to the
    padded zero net number — "the same file with `(net NORDERED 1)` on the via
    routes and exits 0" — existed only as prose in the report and the doc comment.
    It anchors a T1 roadmap row and an upstream-PR candidate, so it needs committed
    evidence.
    `crates/fr-dsn/tests/data/p8t13-via-net-numbers-control.dsn` is now that
    evidence: the hang fixture byte for byte, with one token changed. A subnet
    number > 0 sends `Wiring.getSubnets` (Wiring.java:226-230) down its single-net
    branch, so `foundNets.size() == 1` and `readViaScope`'s loop pads nothing. Its
    tra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
    [p8t13-via-net-numbers-control.dsn]
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2026-09-02 fix(cli): ruling BJ — wire `--set` on the native form, and make five documents true
    Task 14 review round 1: one blocking finding (B1), five should-fixes, four nits.
    Controller ruling BJ resolves B1's substance by **wiring** the flag Task 14 had
    recorded as inert, because the replacement spelling Task 14 named was worse than
    the gap it documented.
    B1 + RULING BJ — the native form had NO generic settings override at all
    Task 14's first pass found `--set section.field=value` declared on `route`,
    parsed by clap and read by nothing, and named Java's `--section.field=value` as
    the live replacement "on both forms". The reviewer measured that replacement:
    clap owns the native command li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
    [p8t5-argv.tsv]
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2026-09-03 fix(router): seed the fanout target sort in quirk #44's descending id order
    `RoutingBoard.fanout:1002-1021` sorts the pin's unconnected set by squared
    distance with a **stable** sort, so the seed order decides every exact tie.
    Java seeds `new ArrayList<>(unconnectedSet)` over `Item.getUnconnectedSet`'s
    plain `new TreeSet<>()` (Item.java:676-690), whose `compareTo` is
    `item.id - id` (Item.java:95-103) — **descending** id, quirk #44. The port
    seeded a `BTreeSet<ItemId>`, which iterates **ascending**, so on a tie it
    escaped the pin toward the lower-id pad where Java goes to the higher.
    A PORT defect, not a Java quirk: no new register id. Quirk #44's row gains a
    "port defect history" note (th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
    [p8-fanout-tie.dsn]
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2026-09-03 feat(benchmark): import the freerouting-bench comparison suite
    Plain copy of ../freerouting-bench's tracked files (78; docs/ excluded,
    README kept) into benchmark/, with the nesting path fixes: paths.py
    derives RUST_REPO=ROOT.parent / JAVA_REPO=sibling clone; candidates
    manifests and remote-run.sh shifted one level. Generated state
    (results/, binaries/, fetched corpus, .venv) stays git-ignored by the
    suite's own .gitignore.
    Verification:
    uv run python -c 'import bench...' paths resolve OK exit 0
    uv run pytest -m 'not slow' -q 202 passed exit 0
    Claude-Session: https://claude.ai/code/session_015f1ubhBBpiWHAooDsso97Z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
    [full-rs-vs-java-java-current-278fe14.csv, full-rs-vs-java-rs-main-6a4a3bd.csv, mini.dsn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]
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2026-09-03 chore(plan9): the gate machinery — register status column, // fixed: vocabulary, ids #293-#296, --from-port generators, quality-ab.sh and the bench view script
    Plan 9 Task 0. No behavioural change: no golden regenerates and no committed
    reference byte moves. This is the machinery every later task writes its
    evidence into.
    The register (docs/java-quirks.md)
    * The rules header's "Do not fix these in the port until parity is proven"
    is replaced by Plan 9's rule: parity is proven and is no longer the
    acceptance test; a row's status says whether the port still reproduces it;
    fixing a row means editing its status cell and adding a `// fixed: T<n>`
    comment BESIDE — never dele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
    [quality-ab-T0.tsv, stem-times.tsv]
2026-09-03 chore(plan9): Task 0 review round — the jar reference column, the cpu floor, and the // fixed: (#id) marker
    Addresses the Task 0 review's one blocking finding, its six should-fixes and
    eight of its ten nits. No behavioural change; no golden regenerates and no
    committed reference byte moves. Amendments A17-A20 in the plan's log.
    B1 (BLOCKING) — quality-ab.sh loaded the jar baseline and threw it away
    `benchmark/baselines/quality-baseline-java-head.tsv` was read into `jar` and
    never referenced again: no jar column in COLUMNS, no jar value emitted, and
    from Task 1 on the header would have printed `# jar-baseline: <path>` with no
    qualifier — a harness affirming a reference it did n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
    [quality-ab-T0.tsv, stem-times.tsv]
2026-09-03 freeze(plan9): the jar's last byte-parity snapshot, and the jar quality column derived from it
    The last moment the port is byte-identical to the jar. `tests/reference/` is regenerated **from
    the port** from the next commit onwards and the jar's differential drivers will eventually be
    retired, so this snapshot is otherwise unrecoverable. No code changes in this commit, by design
    (brief step 1).
    The order inside this commit is the whole point, and is ruling BP1's, fixing two impossibilities
    in the earlier draft — a copy of a directory into itself, and a write into a tree that had already
    been chmodded:
    1. rsync the tree into a SIBLING directory, and verify it;
    2. derive the jar quality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
    [quality-baseline-java-head.tsv, roundtrip.dsn]
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2026-09-03 docs: snapshot the Plan 9 fixture ground-truth bank (in progress)
    Preserves the parallel agent's pre-built fixtures and hand-derived
    expected outcomes in-repo (session scratchpad is temp storage). Partial
    — the bank agent is still adding rows; refreshed at bank completion.
    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
    [p9t11-per-layer-width.dsn, p9t13-multi-net-smd-pin.dsn, p9t8-ninety-degree.dsn]
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2026-09-03 benchmark: quality-ab T1 — the G2 gate passes, the jar column renders, and cpu_s does not move
    `scripts/quality-ab.sh T1 --update-baseline`, 29 stems (8 batch + 13 CLI + 8 DRC), median of 3.
    Exit 0, "all rows within the G2 rules", every row flagged `ok`.
    ## The jar column renders for the first time
    # jar-baseline: benchmark/baselines/quality-baseline-java-head.tsv
    [read; rendered in the jar_* columns as context, never a gate; 29 stems]
    Task 0's B1 fix said the `jar_*` columns would render `-` and the header would say `[absent]` until
    Task 1 wrote that file. It is written (`35f9078`), it is read, and all 29 rows carry real numbers.
    **28 of the 29 rows have `jar_* == port`, to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
    [quality-ab-T1.tsv, stem-times.tsv]
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2026-09-03 feat(router): repair the two measured Java regressions — R1 (#293) airline-first ordering restored, R2 (#294) micro-neckdown floored at the rules minimum; M1 bench recorded
    The task's evidence commit, and a **ruling BP12 escalation with a named next step**. The two
    fixes and their goldens are in the four commits below this one; this one carries what they
    measured, and it does not close the two gates that did not pass.
    ## Committed artefacts
    benchmark/baselines/ab/quality-ab-T2.tsv R1 + R2, --repeats 3, at bd296d7
    benchmark/baselines/ab/quality-ab-T2-r1-only.tsv the bisection: R2's guard removed, nothing
    else, so e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
    [quality-ab-T2-r1-only.tsv, quality-ab-T2.tsv]
2026-09-03 fix(plan9): Task 2 review round — the G2 breach is 10 rows, p7t1's order diverges by design, M1 is deferred
    Review: SPEC PASS-with-fixes / QUALITY PASS, 0 blocking, all five priorities SOUND, every
    number in the ablation reproduced by the reviewer bar one. Three should-fixes and three nits,
    in one commit. No behaviour change: nothing under `crates/*/src` moves except two doc comments.
    ## SF1 — the G2 breach is **10 rows on 6 distinct stems**, not "7 of 21"
    `grep -c INCOMPLETE-ROSE benchmark/baselines/ab/quality-ab-T2.tsv` answers **10**, over
    `router-dac2020-bm01`, `router-j2-reference`, `router-fanout-bm11`, `router-strict-drc-cnh`,
    `Issue026-J2_reference` and `large-outline` — the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
    [quality-ab-T2-r1-only.tsv]
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2026-09-03 benchmark: re-cut quality-ab T3 against Task 2's baseline — quality 0 moved, timing gate RED and not ours
    The rebase onto Task 2 (5152291) made `quality-ab-T2.tsv` exist, so this is the run of
    record: `scripts/quality-ab.sh T3 --update-baseline`, 29 rows, gate-version g1, port-sha
    444c6e0f16a2, port-baseline `quality-ab-T2.tsv` (no longer `[absent]`).
    QUALITY: 0 of 377 measured cells moved.
    --------------------------------------
    29 stems x 13 measured columns — mp_cap, incomplete, violations, clearance_violations,
    hole_clearance_violations, normalized_score, trace_length_mm, via_total, via_through,
    via_blind, via_buried, bend_count and Task 2's new neckdown_below_class_width — every o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
    [quality-ab-T3.tsv, stem-times.tsv]
2026-09-03 fix(plan9): Task 3 review round — the docs stop describing the behaviour the task deleted
    S1 `crates/fr-dsn/tests/kicad_writer.rs` still told a reader that quirk #289's test is
    `do_out_json_writes_the_pre_routing_board` and that it "pastes the jar's own 1 540 bytes as
    a literal" — a test and a literal this task deleted. Rewritten to the shipped behaviour:
    the test is `do_out_json_writes_the_routed_board`, it cross-checks the JSON's `traces`
    count against the SES's `(wire ` count instead of a pasted document, and the paragraph now
    also says why nothing in *that* file moved (`write` is called with whichever board its
    caller hands it; Task 3 changed only which board that is).
    S2 `docs/cli-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
    [stem-times.tsv]
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2026-09-03 docs(plan9): Task 3 landing — rung (c) can never convert, and the timing baseline says it is laptop-cut
    Two notes the landing owes, both of them things a later reader would otherwise have to
    re-derive.
    **The accept wave's concern 2, answered where the wave asks the question.** The wave's
    "Converted drivers" table still said of `p8t7` rung (c) that "Plan 9 Task 3 rewrites this
    rung for #289" and showed it as `MATCH` — future tense, and now wrong on both counts. The
    row is rewritten to the shipped state and to the stronger claim the wave asked to have
    recorded: rung (c) **can never convert to port-golden**, because two of its three checks
    are assertions about the *jar* (that the jar still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
    [stem-times.tsv]
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2026-09-03 measure(plan9): Task 4 close — goldens moved: NONE, and the measurements that say so
    Step 8 of the task, which the plan wrote as "regenerate G (+ B/R/C where #95
    moved a board)". **Measured: nothing moved, so under ruling BT nothing is
    regenerated** — a family regenerates only when a fix moves it.
    * **#95** — the corpus sweep the register row asks for
    (`the_corpus_sweep_counts_boards_whose_settings_were_read`, run at both sides
    of the fix): **2 of 106 before, 2 of 106 after**. The corpus's only two files
    carrying an `(autoroute_settings …)` scope at all —
    `Issue103-Board-Routed.dsn` and `Issue187-processor.Z80.dsn` — both write it
    *before* their first keepout, so neith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
    [quality-ab-T4.tsv]
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2026-09-03 bench: the cpu-timing baseline migrates to the workbench (ruling BW)
    stem-times.tsv is now workbench-cut (task T3-wb via the fixed
    remote-gates.sh: python312 in the shell, extra-arg forwarding, baseline
    pull-back, honest gate-failure exit). The migration run's 1.233 ESCALATE
    is the cross-host comparison itself — adjudicated expected and noted in
    the file; ratios are workbench-vs-workbench from the next task on.
    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
    [quality-ab-T3-wb.tsv, stem-times.tsv]
2026-09-03 measure(plan9): Task 4 landing rebase onto Task 3's tip (66544f6) — re-measured
    Second rebase, at the landing slot. 9 commits replayed onto
    `plan-9-post-parity` at **66544f6** (the Task 3 merge, including its rebased
    commits, the accept wave and its fix round 50aa7f8).
    ## One conflict, in the predicted place
    `docs/superpowers/plans/2026-09-03-plan-9-post-parity.md`, the amendment log —
    exactly the serializer the coordinator named. Task 3's **A22** landed at the end
    of that table per its fix round, and this branch's **A23** wanted the same slot.
    **Resolved by keeping both, in numeric order: A22 (Task 3), then A23 (Task 4).**
    No content was dropped from either side and no row was renumbe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
    [quality-ab-T4.tsv]
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2026-09-03 benchmark: quality-ab T6 — 0 of 493 quality cells move; the cpu lane needs a workbench run
    The tier-G2 A/B over all 29 reference stems, at each stem's own committed `-mp` cap, repeats 3.
    Re-measured after the landing rebase onto `b6aa45f` (Task 4's merge), so this is against the real
    immediate predecessor rather than the stale T2 baseline the pre-rebase run had to use.
    QUALITY LANE: **0 of 493 cells moved against `quality-ab-T4.tsv`.** Every incomplete, violation,
    clearance and hole-clearance count, every `normalized_score`, `trace_length_mm`, via total and
    split, every bend count and every sub-class-width segment count is identical, stem for stem. That
    is the right result for this task,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
    [quality-ab-T6.tsv]
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2026-09-03 fix(plan9): Task 6 review round — the #42/#49 argument was wrong, and the divergence table reported drift as healing
    B1 (blocking). My #42/#49 deferral rested on "every production caller already guards". **That is
    false**, and the reviewer found the counter-example I had missed by sampling callers and
    generalising: `RoutingBoard.fanout`'s port (`routing_board_ext.rs`, the `getSmdPins` loop) reads
    `components.get(pin_item.component_id())` unconditionally, exactly as Java's `:1045` does.
    The conclusion survives on a better ground, which the reviewer verified at all fifteen call sites:
    **the collections are append-only.** `Components`, `Packages` and `LogicalParts` expose `add` /
    `add_with_g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
    [quality-ab-T6.tsv]
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2026-09-03 measure(plan9): T5's quality-ab row — quality bit-identical on all 29 stems
    `scripts/quality-ab.sh T5` at 916b8e5, three repeats, against the T4 port
    baseline (ruling BP15). Console output in full at
    `scripts/differential/out/quality-ab-T5.txt` (gitignored).
    ## The quality half: nothing moved, anywhere
    Comparing every column that is a gate input, T4 -> T5, over all 29 stems (8 batch,
    13 CLI, 8 DRC):
    incompletes unchanged on all 29
    violations unchanged on all 29
    clearance violations unchanged on all 29
    hole-clearance violations unchanged on all 29
    normalized_score unchanged on all 29
    **Incompletes rose on no stem.*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
    [quality-ab-T5.tsv]
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2026-09-03 test(router): the 90-degree fixture, and Task 17's subsumption table
    `complete_shape_90` had no board. Nothing in the committed corpus declares
    `(snap_angle ninety_degree)` — `Issue103`, `Issue187` and `Issue413` are all
    `fortyfive_degree` — so the regime quirk #159 lives in was reachable only from
    `tests/tree_ext.rs`'s synthetic `TestBoard`. `crates/fr-router/tests/data/
    p9t8-ninety-degree.dsn` is the fixture the plan owes it: a 200 mm x 200 mm
    two-layer board with four corner pads on two nets that must cross and one
    40 mm x 40 mm through-board blocker in the middle, so the maze builds rooms
    around an obstacle under the 90-degree tree. Taken verbatim from
    `docs/plan-9-prep/fixtures/task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
    [p9t8-ninety-degree.dsn]
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2026-09-03 fix(router): T8 review round — the stale-index pins flipped, the A/B armed, five records corrected
    The review's three SPEC blockers and its five smaller findings. B3 is adjudicated
    by the controller in this task's favour and needs only an attribution sentence.
    B1 — the T17 stale-index pin was RED and this task reported it green
    ---------------------------------------------------------------------
    It was red. The report said *"`stale_index.rs` is green throughout (its four tests
    pass before and after every commit)"* and **that was never measured**. The only
    `--run-ignored all` sweep that would have covered it was killed mid-run: my 13:25
    log ends with `SLOW [>240.000s] fr-router::stale_i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
    [quality-ab-T8.tsv, stem-times.tsv]
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2026-09-03 measure(plan9): T7's quality-ab row — 0 of 522 quality cells moved, both KiCad stems clean
    Ruling BP15. Run without `--claims-connectivity` (ruling BZ(a)): T7's fix list
    claims no connectivity win — it claims that a malformed board is refused, that
    a pad gets its own padstack and that a net gets a predictable number — so the
    must-fall rule is a NOTE and the script says so in the tsv header.
    0 of 522 quality cells moved against `quality-ab-T6.tsv`. Every incomplete,
    violation, clearance, hole-clearance, score, trace-length, via, bend and
    neckdown cell on all 29 stems is byte-identical.
    cli/kicad-ecc83-json incomplete 6, violations 14, score 309.9979,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
    [quality-ab-T7.tsv]
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

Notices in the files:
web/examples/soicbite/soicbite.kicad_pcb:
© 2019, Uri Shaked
